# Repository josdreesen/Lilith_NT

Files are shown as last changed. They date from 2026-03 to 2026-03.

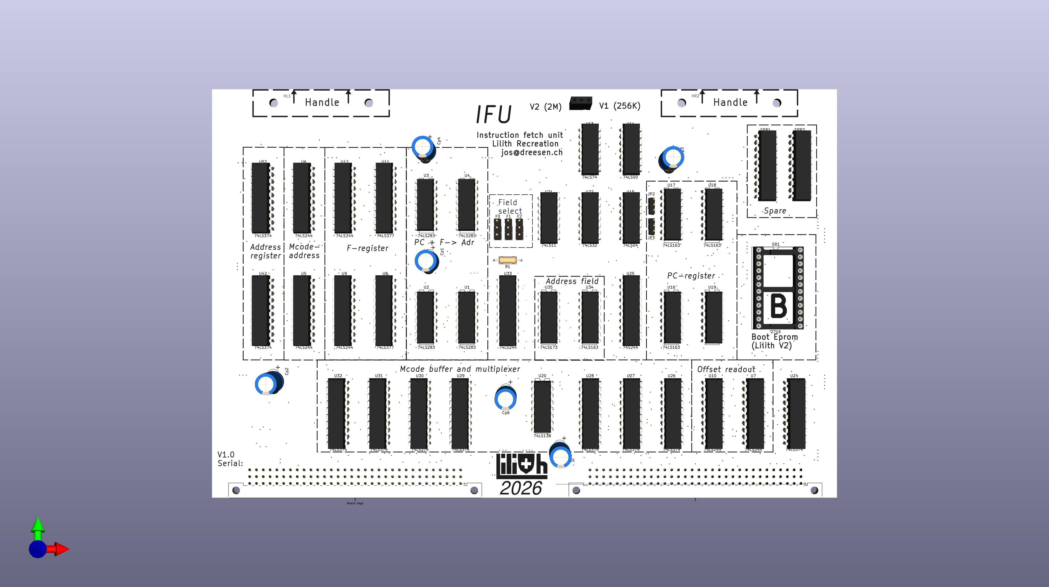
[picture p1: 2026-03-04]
IFU_NT/IFU_NT.jpg

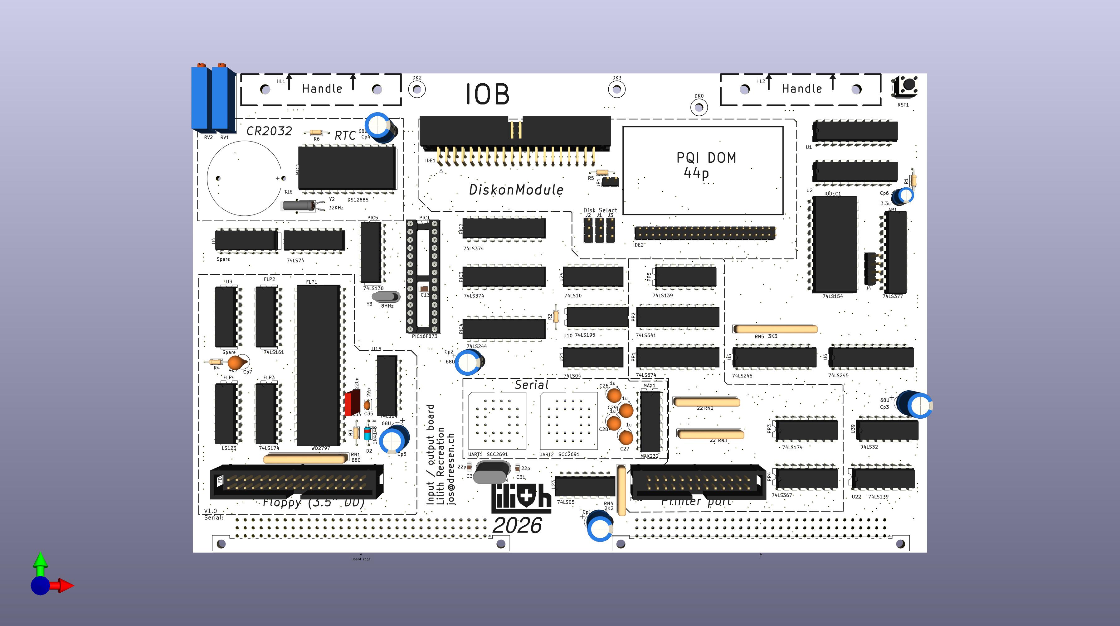
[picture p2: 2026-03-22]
IOB_NT/IOB_NT.jpg

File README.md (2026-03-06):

# Lilith_NT

This database documents my attempt to recreate the 1980's ETH Lilith Modula-2 workstation. Both hardware and software is to be documented here.

The actual CPU will be identical to the original machine, shortcuts will be made to avoid some of the original problems :
- The disk was either a Honeywell-Bull 10Mb cartridge drive, or a 15Mb  MFM drive, controlled by a WD1001.
- NEW -> This is to be replaced by a DOM-disk with ATA interface.
- The original ha 4 PCB's with each 32 4116-type DRAM-chips, for a total of 128K 16bit words.
- NEW -> a single PCB will hold 16 256Kx4 chips, for a total of 1M 16bit words.
  Other characteristics will remain the same ( i.e. write access in 16bit words, read access in either 16bit of 64bit words)
- NEW : DIN41642 connectors will replace the original, hard to find and expensive 1.125" spaced board edge connectors.

Lilith-NT's hardware consists of 8 PCB's, all newly designed in a more compact format (Dual eurocard, 233.4mm x 152mm)

DPU : a MC6802 based debugging aid. This takes over the main busses in the system, allowing direct access to the hardware.
      Original schematic, slightly newer memory chips, new board layout.
      Not needed in normal operation of a Lilith.

ALU : the actual CPU, consisting of 4 AMD2901 bitslices, hardware stack and a 16bit barrel shifter.
      Original schematic with a new board layout.

MCU : microcode unit. Contains the microprogram that controls the bitslices, also has the microcode sequencer and clockgen circuitry.
      Original schematic with a new PCB layout, but now also has the memory address registers, originally in the CDP board.

IFU : instruction fetch unit. Also contains boot eprom. Original schematic with a new board layout.

DRAM: main memory, consisting of 16 4x256K DRAMs. Updated design of the original, using much denser chips. 
      Also contains the Dataregister which was originally in the CDP board.
      
DSP : Display unit / Videocard. Original schematic with a new board layout.      

IOP : IO board : new design, new PCB combining PS2 keyboard & mouse interface. 
      Also contains 2 serial channels, ATA/DOM disk, floppy interface and RTC chip.
      
Mainboard : carrries the above mentioned boards in dedicated slots.
            New design, using DIN-connectors instead of the PCB cardedge connectors to reduce cost and increase reliability.
            Goldplating PCB's is considerable more expensive than just using the DIN connectors.

The subdirectories, one for each pcb,  contain a .zip file with the gerbers, a .pdf with the schematic, a rendering of the PCB
and the Kicad Database itself.

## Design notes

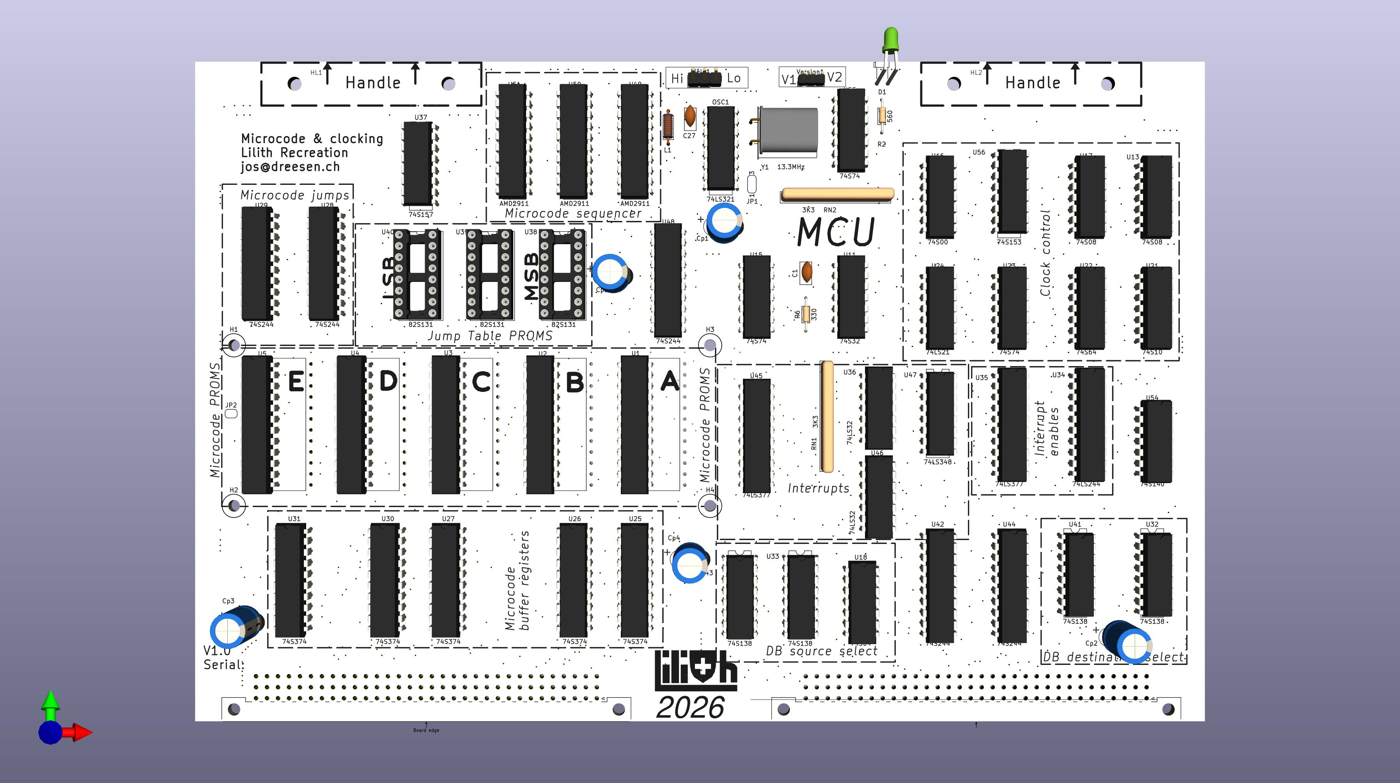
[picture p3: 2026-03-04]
MCU_NT/MCU_NT.jpg

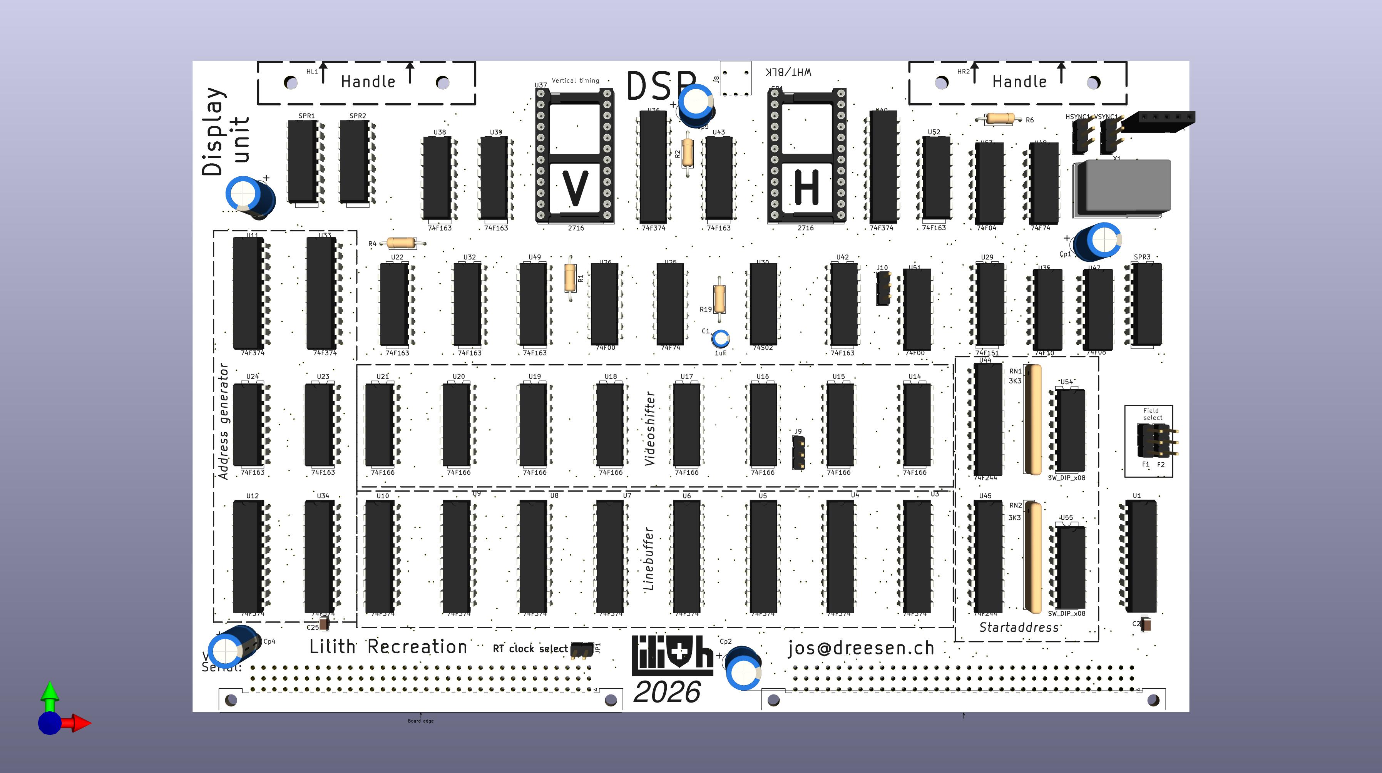
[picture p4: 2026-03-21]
DSP_NT/DSP_NT.jpg

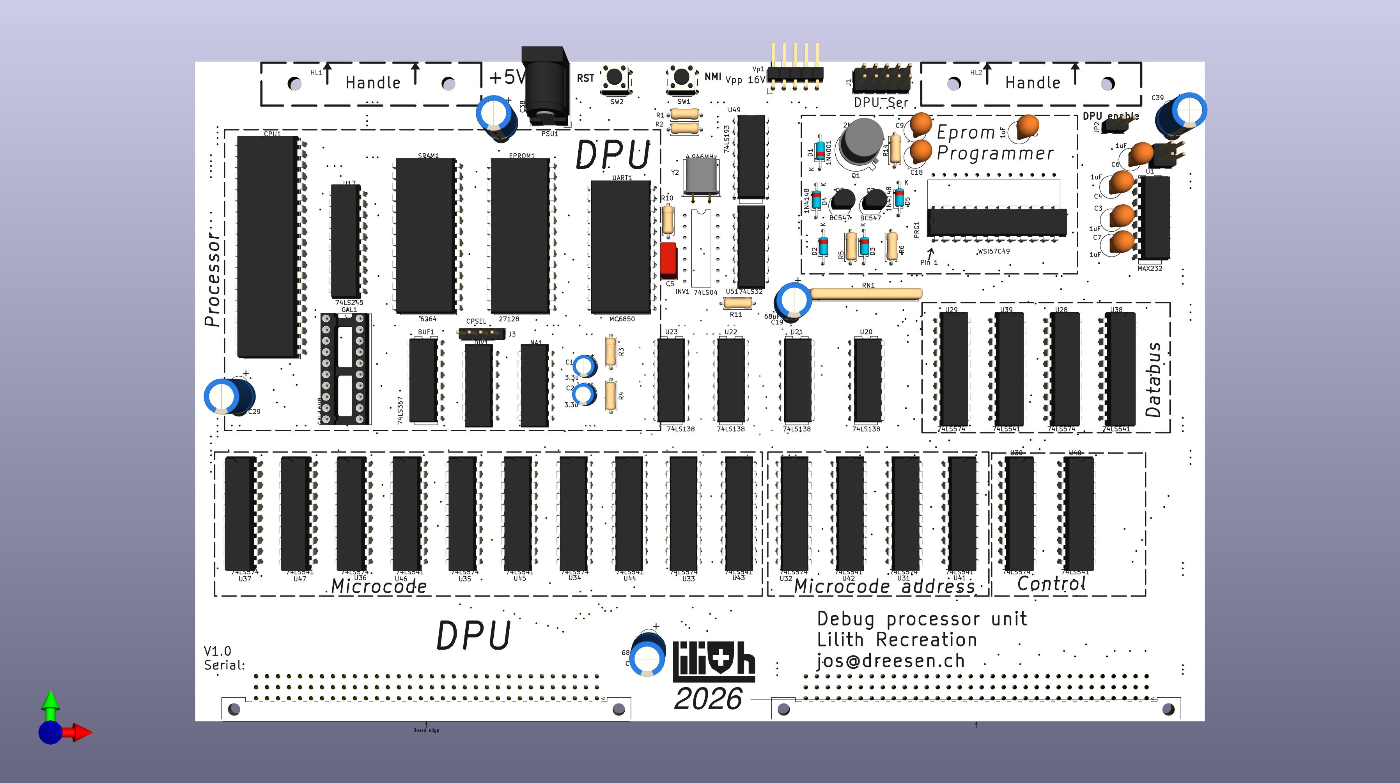
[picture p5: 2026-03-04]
DPU_NT/DPU_NT.jpg

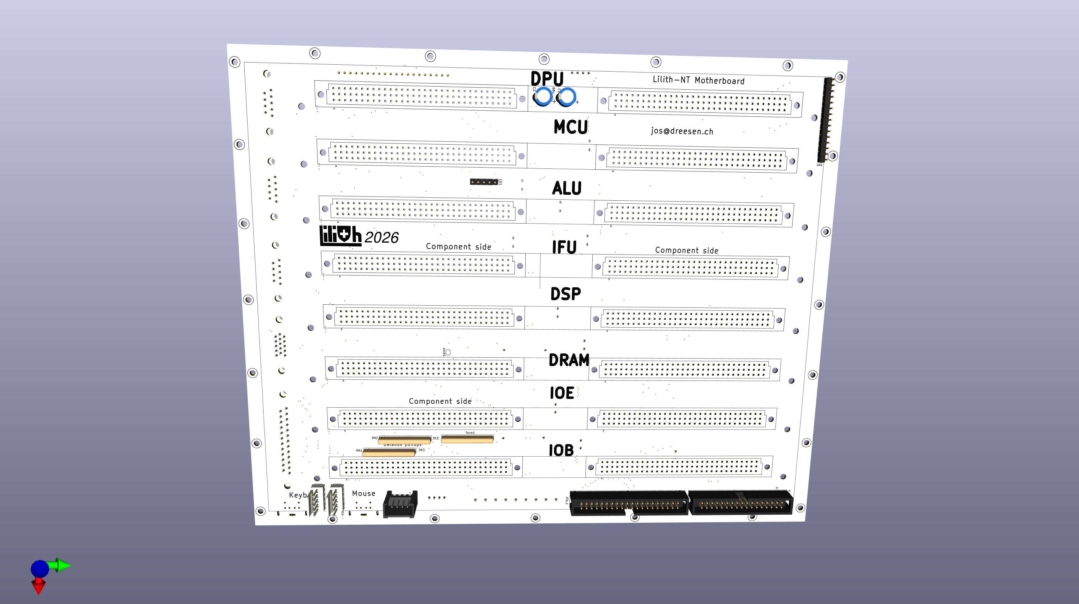
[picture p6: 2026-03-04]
Backplane_NT/Backplane_NT.jpg

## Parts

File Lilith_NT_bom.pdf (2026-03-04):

| Package_ | Number | Pins | Total pins

## Programmed ICs

PIC16F873-XXISP | Package_DIP:DIP-28_W7.62mm_Socket | 1 | 28 | 28 | IOB
Eprom 27128 | Package_DIP:DIP-28_W15.24mm | 1 | 28 | 28 | DPU
Eprom 2716 | Package_DIP:DIP-24_W15.24mm_Socket | 3 | 24 | 72 | DSP | IFU
WSI57C49 | Package_DIP:DIP-24_W15.24mm | 5 | 24 | 120 | MCU
82S131 | Package_DIP:DIP-16_W7.62mm_Socket | 3 | 16 | 48 | MCU
GAL16V8 | Package_DIP:DIP-20_W7.62mm_Socket | 2 | 20 | 40 | DPU | DRAM

## Special ICs

AMD2901 | Package_DIP:DIP-40_W15.24mm | 4 | 40 | 160 | ALU
AMD2911 | Package_DIP:DIP-20_W7.62mm | 3 | 20 | 60 | MCU
DS12885 | Package_DIP:DIP-24_W15.24mm | 1 | 24 | 24 | IOB
WD2797 | Package_DIP:DIP-40_W15.24mm | 1 | 40 | 40 | IOB
SCC2691 | Package_LCC:PLCC-28_THT-Socket | 2 | 28 | 56 | IOB
MAX232 | Package_SO:SO-16_5.3x10.2mm_P1.27mm | 1 | 16 | 16 | IOB
DRAM 256Kx4” | Package_DIP:DIP-20_W7.62mm | 16 | 20 | 320 | DRAM
SRAM 8K 6264 | Package_DIP:DIP-28_W15.24mm | 1 | 28 | 28 | DPU
LM555xN | Package_DIP:DIP-8_W7.62mm | 1 | 8 | 8 | DRAM
MAX232 | Package_DIP:DIP-16_W7.62mm | 1 | 16 | 16 | DPU
MC6802 | Package_DIP:DIP-40_W15.24mm | 1 | 40 | 40 | DPU
MC6850 | Package_DIP:DIP-24_W15.24mm | 1 | 24 | 24 | DPU
SN74S409 | Package_DIP:DIP-48_W15.24mm | 1 | 48 | 48 | DRAM

## TTL ICs

74F00 | Package_DIP:DIP-14_W7.62mm | 2 | 14 | 28 | DSP
74F04 | Package_DIP:DIP-14_W7.62mm | 1 | 14 | 14 | DSP
74F08 | Package_DIP:DIP-14_W7.62mm | 1 | 14 | 14 | DSP
74F10 | Package_DIP:DIP-14_W7.62mm | 1 | 14 | 14 | DSP
74F151 | Package_DIP:DIP-16_W7.62mm | 1 | 16 | 16 | DSP
74F74 | Package_DIP:DIP-14_W7.62mm | 2 | 14 | 28 | DSP
74F163 | Package_DIP:DIP-16_W7.62mm | 10 | 16 | 160 | DSP
74F166 | Package_DIP:DIP-16_W7.62mm | 8 | 16 | 128 | DSP
74F244 | Package_DIP:DIP-20_W7.62mm | 3 | 20 | 60 | DSP
74F374 | Package_DIP:DIP-20_W7.62mm | 14 | 20 | 280 | DSP
74LS00 | Package_DIP:DIP-14_W7.62mm | 1 | 14 | 14 | IFU
74LS04 | Package_DIP:DIP-14_W7.62mm | 5 | 14 | 70 | DPU | DRAM | IFU | IOB
74LS05 | Package_DIP:DIP-14_W7.62mm | 1 | 14 | 14 | IOB
74LS08 | Package_DIP:DIP-14_W7.62mm | 1 | 14 | 14 | IOB
74LS10 | Package_DIP:DIP-14_W7.62mm | 1 | 14 | 14 | IOB
74LS11 | Package_DIP:DIP-14_W7.62mm | 1 | 14 | 14 | IFU
74LS123 | Package_DIP:DIP-16_W7.62mm | 2 | 16 | 32 | DRAM | IOB
74LS125 | Package_DIP:DIP-14_W7.62mm | 1 | 14 | 14 | ALU
74LS132 | Package_DIP:DIP-14_W7.62mm | 1 | 14 | 14
74LS138 | Package_DIP:DIP-16_W7.62mm | 6 | 16 | 96 | DPU | IFU | IOB
74LS139 | Package_DIP:DIP-16_W7.62mm | 3 | 16 | 48 | DRAM | IOB
74LS153 | Package_DIP:DIP-16_W7.62mm | 1 | 16 | 16 | ALU
74LS154 | Package_DIP:DIP-24_W15.24mm | 1 | 24 | 24 | IOB
74LS161 | Package_DIP:DIP-16_W7.62mm | 1 | 16 | 16 | IOB
74LS163 | Package_DIP:DIP-16_W7.62mm | 5 | 16 | 80 | IFU
74LS173 | Package_DIP:DIP-16_W7.62mm | 2 | 16 | 32 | ALU | IFU
74LS174 | Package_DIP:DIP-16_W7.62mm | 2 | 16 | 32 | IOB
74LS191 | Package_DIP:DIP-16_W7.62mm | 1 | 16 | 16 | ALU
74LS193 | Package_DIP:DIP-16_W7.62mm | 1 | 16 | 16 | DPU
74LS195 | Package_DIP:DIP-16_W7.62mm | 1 | 16 | 16 | IOB
74LS21 | Package_DIP:DIP-14_W7.62mm | 1 | 14 | 14 | MCU
74LS244 | Package_DIP:DIP-20_W7.62mm | 10 | 20 | 200 | IFU | MCU | IOB
74LS245 | Package_DIP:DIP-20_W7.62mm | 11 | 20 | 220 | DPU | DRAM | IOB
74ls278 | Package_DIP:DIP-14_W7.62mm | 1 | 14 | 14 | DRAM
74LS283 | Package_DIP:DIP-16_W7.62mm | 5 | 16 | 80 | ALU | IFU
74LS32 | Package_DIP:DIP-14_W7.62mm | 8 | 14 | 112 | DPU | IFU | MCU | IOB
74LS321 | Package_DIP:DIP-16_W7.62mm | 1 | 16 | 16 | MCU
74LS348 | Package_DIP:DIP-16_W7.62mm | 1 | 16 | 16 | MCU
74LS367 | Package_DIP:DIP-16_W7.62mm | 2 | 16 | 32 | DPU | IOB
74LS374 | Package_DIP:DIP-20_W7.62mm | 13 | 20 | 260 | IFU | IOB
74LS377 | Package_DIP:DIP-20_W7.62mm | 5 | 20 | 100 | IFU | MCU | IOB
74LS541 | Package_DIP:DIP-20_W7.62mm | 18 | 20 | 360 | DPU | DRAM
74LS574 | Package_DIP:DIP-20_W7.62mm | 14 | 20 | 280 | DPU | DRAM
74LS74 | Package_DIP:DIP-14_W7.62mm | 5 | 14 | 70 | DPU | DRAM | IFU | IOB
74LS86 | Package_DIP:DIP-14_W7.62mm | 1 | 14 | 14 | ALU
74S00 | Package_DIP:DIP-14_W7.62mm | 1 | 14 | 14 | ALU
74S00 | Package_DIP:DIP-14_W7.62mm | 2 | 14 | 28 | DRAM | MCU
74S02 | Package_DIP:DIP-14_W7.62mm | 2 | 14 | 28 | ALU | DSP
74S04 | Package_DIP:DIP-14_W7.62mm | 2 | 14 | 28 | ALU | MCU
74S08 | Package_DIP:DIP-14_W7.62mm | 2 | 14 | 28 | MCU
74S10 | Package_DIP:DIP-14_W7.62mm | 1 | 14 | 14 | MCU
74S138 | Package_DIP:DIP-16_W7.62mm | 4 | 16 | 64 | MCU
74S140 | Package_DIP:DIP-14_W7.62mm | 1 | 14 | 14 | MCU
74S153 | Package_DIP:DIP-16_W7.62mm | 1 | 16 | 16 | MCU
74S157 | Package_DIP:DIP-16_W7.62mm | 2 | 16 | 32 | ALU | MCU
74S174 | Package_DIP:DIP-16_W7.62mm | 1 | 16 | 16 | ALU
74S182 | Package_DIP:DIP-16_W7.62mm | 1 | 16 | 16 | ALU
74s189 | Package_DIP:DIP-16_W7.62mm | 4 | 16 | 64 | ALU
74S240 | Package_DIP:DIP-20_W7.62mm | 2 | 20 | 40 | ALU
74S244 | Package_DIP:DIP-20_W7.62mm | 9 | 20 | 180 | ALU | IFU | MCU
74S32 | Package_DIP:DIP-14_W7.62mm | 13 | 14 | 182 | ALU | DRAM | MCU
74S350 | Package_DIP:DIP-16_W7.62mm | 8 | 16 | 128 | ALU
74S374 | Package_DIP:DIP-20_W7.62mm | 5 | 20 | 100 | MCU
74S64 | Package_DIP:DIP-14_W7.62mm | 3 | 14 | 42 | ALU | MCU
74S74 | Package_DIP:DIP-14_W7.62mm | 3 | 14 | 42 | MCU | IOB
| Number of IC’s | 293
| Number of IC solder joints | 5374
Resistors | | | 2
| 100 Resistor_SMD:R_0805_2012Metric_Pad1.20x1.40m | 20 | 2 | 40 | DRAM
| 0 Resistor_SMD:R_0805_2012Metric_Pad1.20x1.40m | 9 | 2 | 18 | DRAM
3K3 | Resistor_THT:R_Array_SIP10,Resistor_THT:R_Ax | 5 | 10 | 50 | DRAM
3K3 | Resistor_THT:R_Array_SIP10 | 1 | 10 | 10 | DPU
3K3 | Resistor_THT:R_Array_SIP10 | 2 | 10 | 20 | DSP
3K3 | Resistor_THT:R_Array_SIP10 | 2 | 10 | 20 | MCU
| 560 Resistor_THT:R_Axial_DIN0204_L3.6mm_D1.6mm_P | 4 | 2 | 8 | ALU
| 560 Resistor_THT:R_Axial_DIN0204_L3.6mm_D1.6mm_P | 1 | 2 | 2 | MCU
| 330 Resistor_THT:R_Axial_DIN0204_L3.6mm_D1.6mm_P | 1 | 2 | 2 | MCU
| 560 Resistor_THT:R_Axial_DIN0207_L6.3mm_D2.5mm_P | 4 | 2 | 8 | DSP
10k | Resistor_THT:R_Axial_DIN0207_L6.3mm_D2.5mm_P | 1 | 2 | 2 | DSP
| 560 Resistor_THT:R_Axial_DIN0207_L6.3mm_D2.5mm_P | 1 | 2 | 2 | IFU
10K | Resistor_THT:R_Axial_DIN0207_L6.3mm_D2.5mm_P | 3 | 2 | 6 | DPU
1K | Resistor_THT:R_Axial_DIN0207_L6.3mm_D2.5mm_P | 6 | 2 | 12 | DPU
2K2 | Resistor_THT:R_Axial_DIN0207_L6.3mm_D2.5mm_P | 3 | 2 | 6 | DRAM
4K7 | Resistor_THT:R_Axial_DIN0207_L6.3mm_D2.5mm_P | 1 | 2 | 2 | DRAM
| 680 Resistor_THT:R_Array_SIP10 | 1 | 10 | 10 | IOB
| 220 Resistor_THT:R_Array_SIP10 | 1 | 10 | 10 | IOB
3K3 | Resistor_THT:R_Array_SIP10 | 1 | 10 | 10 | IOB
3K3 | Resistor_THT:R_Array_SIP10 | 2 | 10 | 20 | MoBo
R_Network_Dividers_x08_SResistor_THT:R_Array_SIP10 | 1 | 10 | 10 | MoBo
| 22 Resistor_THT:R_Array_SIP8 | 2 | 8 | 16 | IOB
10K | Resistor_THT:R_Axial_DIN0204_L3.6mm_D1.6mm_P | 1 | 2 | 2 | IOB
2K2 | Resistor_THT:R_Axial_DIN0204_L3.6mm_D1.6mm_P | 2 | 2 | 4 | IOB
1K | Resistor_THT:R_Axial_DIN0204_L3.6mm_D1.6mm_P | 1 | 2 | 2 | IOB
75K | Resistor_THT:R_Axial_DIN0204_L3.6mm_D1.6mm_P | 1 | 2 | 2 | IOB

## Connectors

PCB interconnect | DIN41642-96pin-male-90degrees | 16 | 96 | 1536 | ALU | DPU | DRAM | DSP | IFU | MCU | IOB
PCB interconnect | DIN41642-96pin-female | 16 | 96 | 1536 | ALU | MoBo
DE15_Socket_HighDensity_Connector_Dsub:DSUB-15-HD_Socket_Vertical_P2 | 1 | 15 | 15 | MoBo
Conn_02x13_Top_Bottom Connector_Dsub:DSUB-25_Socket_Vertical_P2.77x | 1 | 25 | 25 | MoBo
DE9_Pins_MountingHoles Connector_Dsub:DSUB-9_Pins_Vertical_P2.77x2.8 | 3 | 9 | 27 | MoBo
Conn_02x13_Top_Bottom Connector_IDC:IDC-Header_2x13_P2.54mm_Vertica | 1 | 26 | 26 | IOB
Conn_02x17_Odd_Even | Connector_IDC:IDC-Header_2x17_P2.54mm_Vertica | 1 | 34 | 34 | IOB
Conn_02x17_Odd_Even | Connector_IDC:IDC-Header_2x17_P2.54mm_Vertica | 1 | 34 | 34 | MoBo
Conn_02x20_Odd_Even | Connector_IDC:IDC-Header_2x20_P2.54mm_Horizon | 1 | 40 | 40 | IOB
Conn_02x20_Odd_Even | Connector_IDC:IDC-Header_2x20_P2.54mm_Vertica | 1 | 20 | 20 | MoBo
Conn_01x05_Pin | Connector_Molex:Molex_KK-254_AE-6410-05A_1x0 | 2 | 5 | 10 | MoBo
Conn_01x09_Socket | Connector_Phoenix_MC_HighVoltage:PhoenixConta | 1 | 9 | 9 | MoBo
Conn_02x22_Odd_Even | Connector_PinHeader_2.00mm:PinHeader_2x22_P2 | 2 | 44 | 88 | IOB
Conn_01x01_Pin | Connector_PinHeader_2.54mm:PinHeader_1x01_P2 | 1 | 1 | 1 | MoBo
Conn_01x04_Pin | Connector_PinHeader_2.54mm:PinHeader_1x04_P2 | 4 | 4 | 16 | IOB
Conn_01x04_Pin | Connector_Stocko:Stocko_MKS_1654-6-0-404_1x4_ | 3 | 4 | 12 | MoBo
Mini-DIN-7 | Mini-DIN PS2 | 2 | 9 | 18 | MoBo

## Capacitors

22p | Capacitor_SMD:C_0805_2012Metric | 2 | 2 | 4 | IOB
22p | Capacitor_SMD:C_0805_2012Metric_Pad1.18x1.45 | 2 | 2 | 4 | IOB
100n | Capacitor_SMD:C_1206_3216Metric_Pad1.33x1.80 | 25 | 2 | 50 | IOB
22p | Capacitor_THT:C_Disc_D3.0mm_W2.0mm_P2.50m | 1 | 2 | 2 | IOB
220n | Capacitor_THT:C_Rect_L7.0mm_W2.5mm_P5.00m | 1 | 2 | 2 | IOB
1u | Capacitor_THT:CP_Radial_Tantal_D4.5mm_P2.50 | 4 | 2 | 8 | IOB
4u7 | Capacitor_THT:CP_Radial_Tantal_D4.5mm_P2.50 | 1 | 2 | 2 | IOB
470n | Capacitor_SMD:C_0805_2012Metric_Pad1.18x1.45 | 75 | 2 | 150 | DRAM | DPU
100n | Capacitor_SMD:C_1206_3216Metric_Pad1.33x1. | 160 | 2 | 320 | DRAM | ALU
68uF | Capacitor_Tantalum_SMD:CP_EIA-7343-20_Kemet-V | 8 | 2 | 16 | DRAM
68uF | Elco 5mm pitch | 40 | 2 | 80 | ALU | DPU
220p | Capacitor_THT:C_Disc_D5.0mm_W2.5mm_P2.50m | 1 | 2 | 2 | MCU | | DSP | IFU | MCU
10p | Capacitor_THT:C_Disc_D5.0mm_W2.5mm_P2.50m | 1 | 2 | 2 | MCU
1n | Capacitor_THT:C_Rect_L7.2mm_W3.5mm_P5.00 | 4 | 2 | 8 | DRAM | | DSP | IFU | IOB
1uF | Capacitor_THT:CP_Radial_D4.0mm_P2.00mm | 1 | 2 | 2 | DSP
3.3u | Capacitor_THT:CP_Radial_D5.0mm_P2.50mm | 2 | 2 | 4 | DPU
1uF | Capacitor_THT:CP_Radial_Tantal_D5.0mm_P2.50 | 7 | 2 | 14 | DPU

## Chrystals

CXO_DIP8 28 MHz | Oscillator:Oscillator_DIP-8 | 1 | 4 | 4 | DSP
13.3MHz | Crystal:Crystal_HC18-U_Horizontal | 1 | 2 | 2 | MCU
4.946MHz | Crystal:Crystal_HC52-8mm_Horizontal | 1 | 2 | 2 | DPU
32KHz | Crystal:Crystal_AT310_D3.0mm_L10.0mm_Horizonta | 1 | 4 | 4 | IOB | 32KHz
3.684MHz | Crystal:Crystal_HC49-U_Vertical | 1 | 2 | 2 | IOB | 3.684MHz
8MHz | Crystal:Crystal_HC52-6mm_Vertical | 1 | 2 | 2 | IOB | 8MHz
| Total number of solder points | | | 9801

## Rest

10uH | Inductor_THT:L_Axial_L5.3mm_D2.2mm_P7.62mm_H | 1 | | | MCU
CR2032 | Battery:BatteryHolder_MYOUNG_BS-07-A1BJ001_ | 1 | | | IOB
SW_DIP_x08 | Package_DIP:DIP-16_W7.62mm | 2 | 16 | | DSP
RSTNMI | Button_Switch_THT:SW_PUSH_6mm | Button_Switch_THT:SW_PUSH_6mm 1 | | | DPU
Barrel_Jack_Switch | Connector_BarrelJack:BarrelJack_GCT_DCJ200-10- | 1 | | | DPU
Boot | LED_THT:LED_D3.0mm_Horizontal_O3.81mm_Z10 | 2 | | | MCU | DRAM
10uH | Inductor_THT:L_Axial_L5.3mm_D2.2mm_P7.62mm_H | 1 | | | MCU
50K | Potentiometer_THT:Potentiometer_Bourns_3006P_Ho | 1 | | | IOB
10K | Potentiometer_THT:Potentiometer_Bourns_3006P_Ho | 1 | | | IOB

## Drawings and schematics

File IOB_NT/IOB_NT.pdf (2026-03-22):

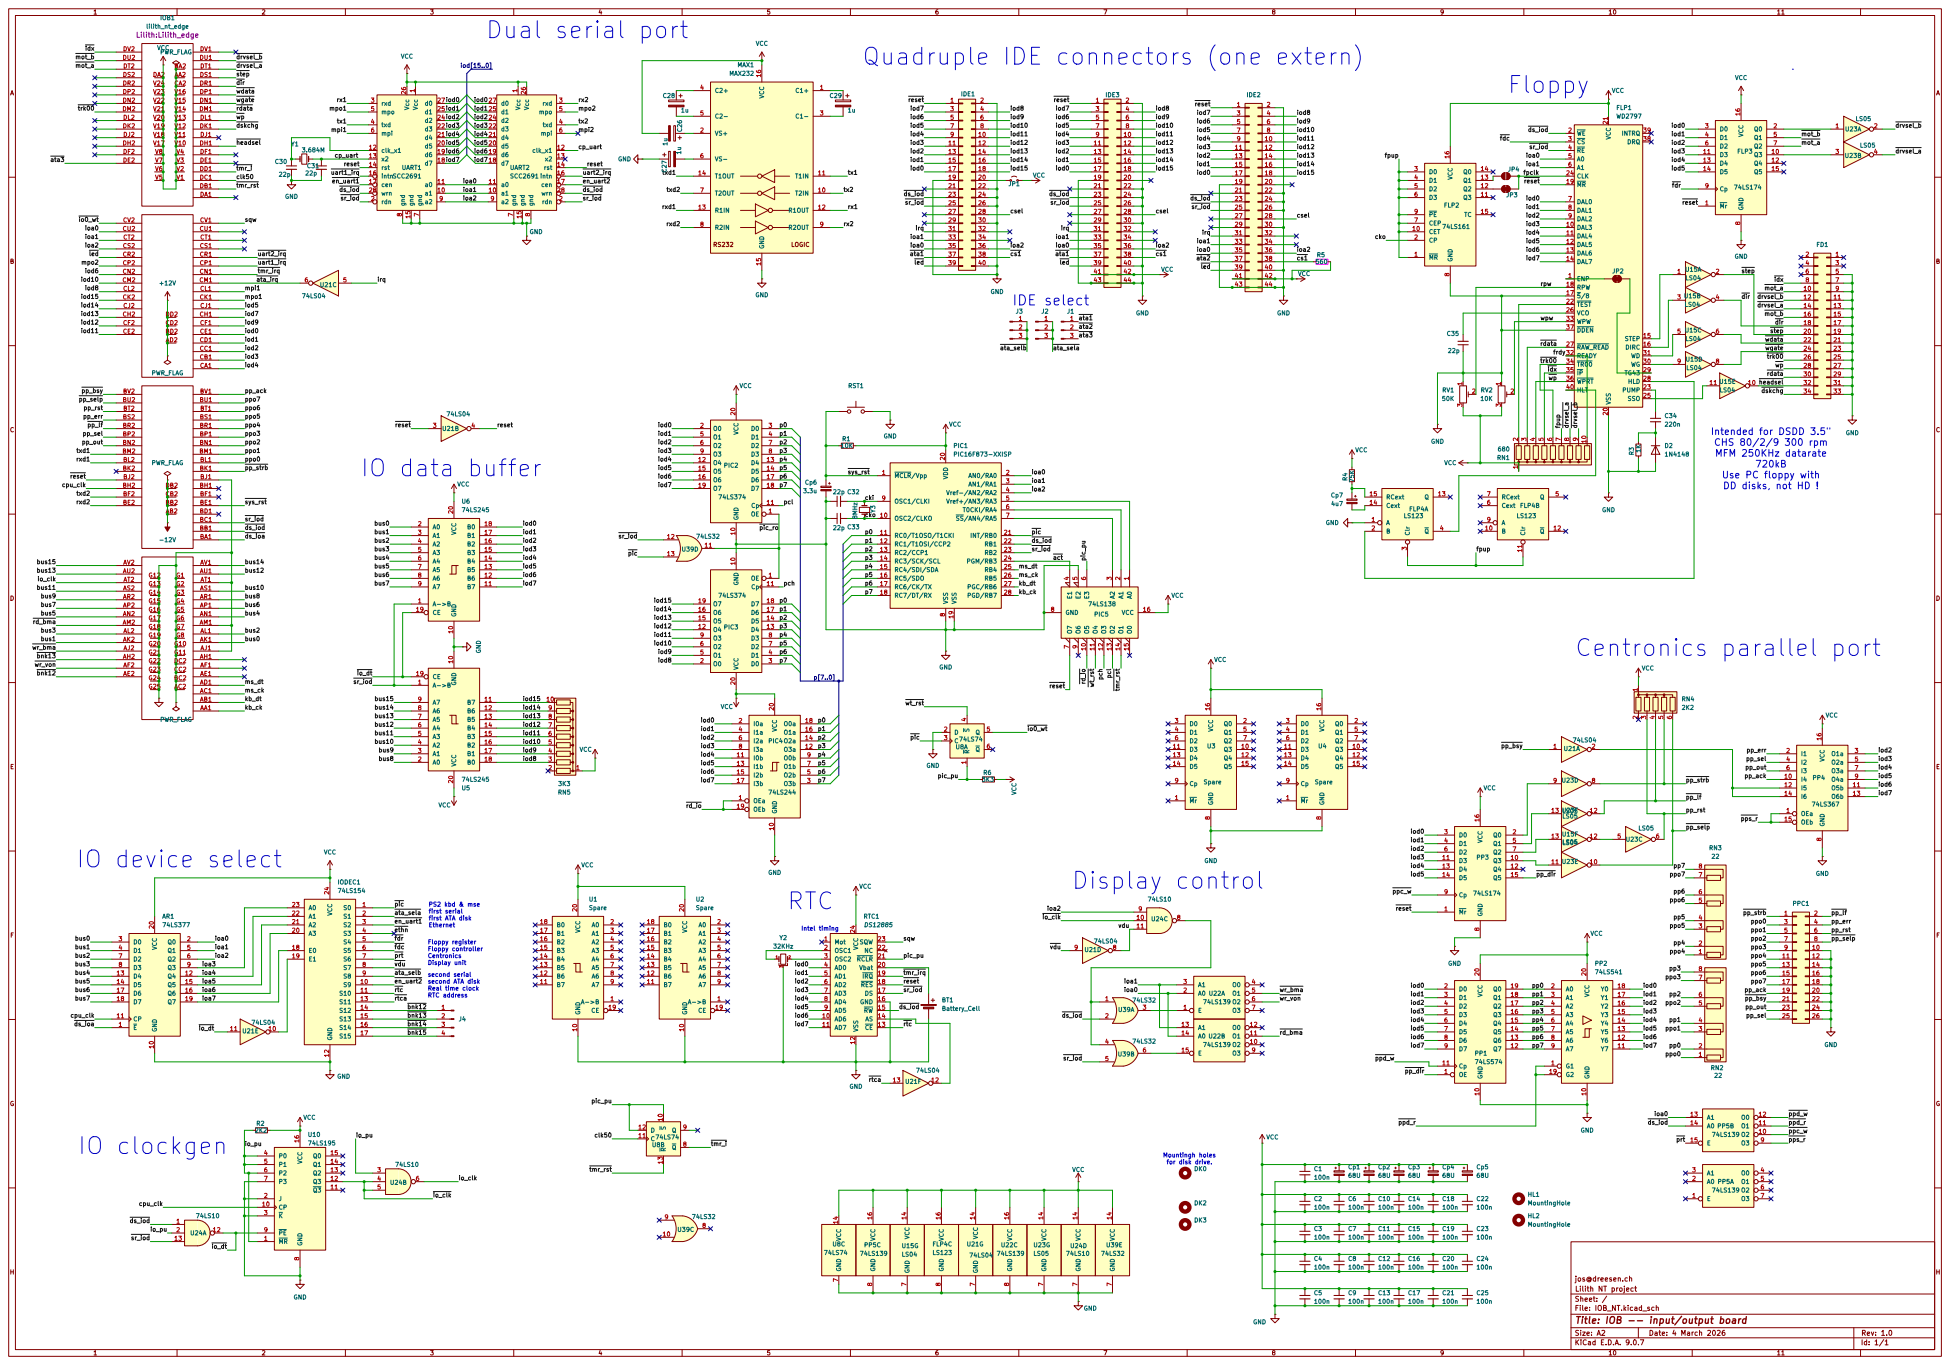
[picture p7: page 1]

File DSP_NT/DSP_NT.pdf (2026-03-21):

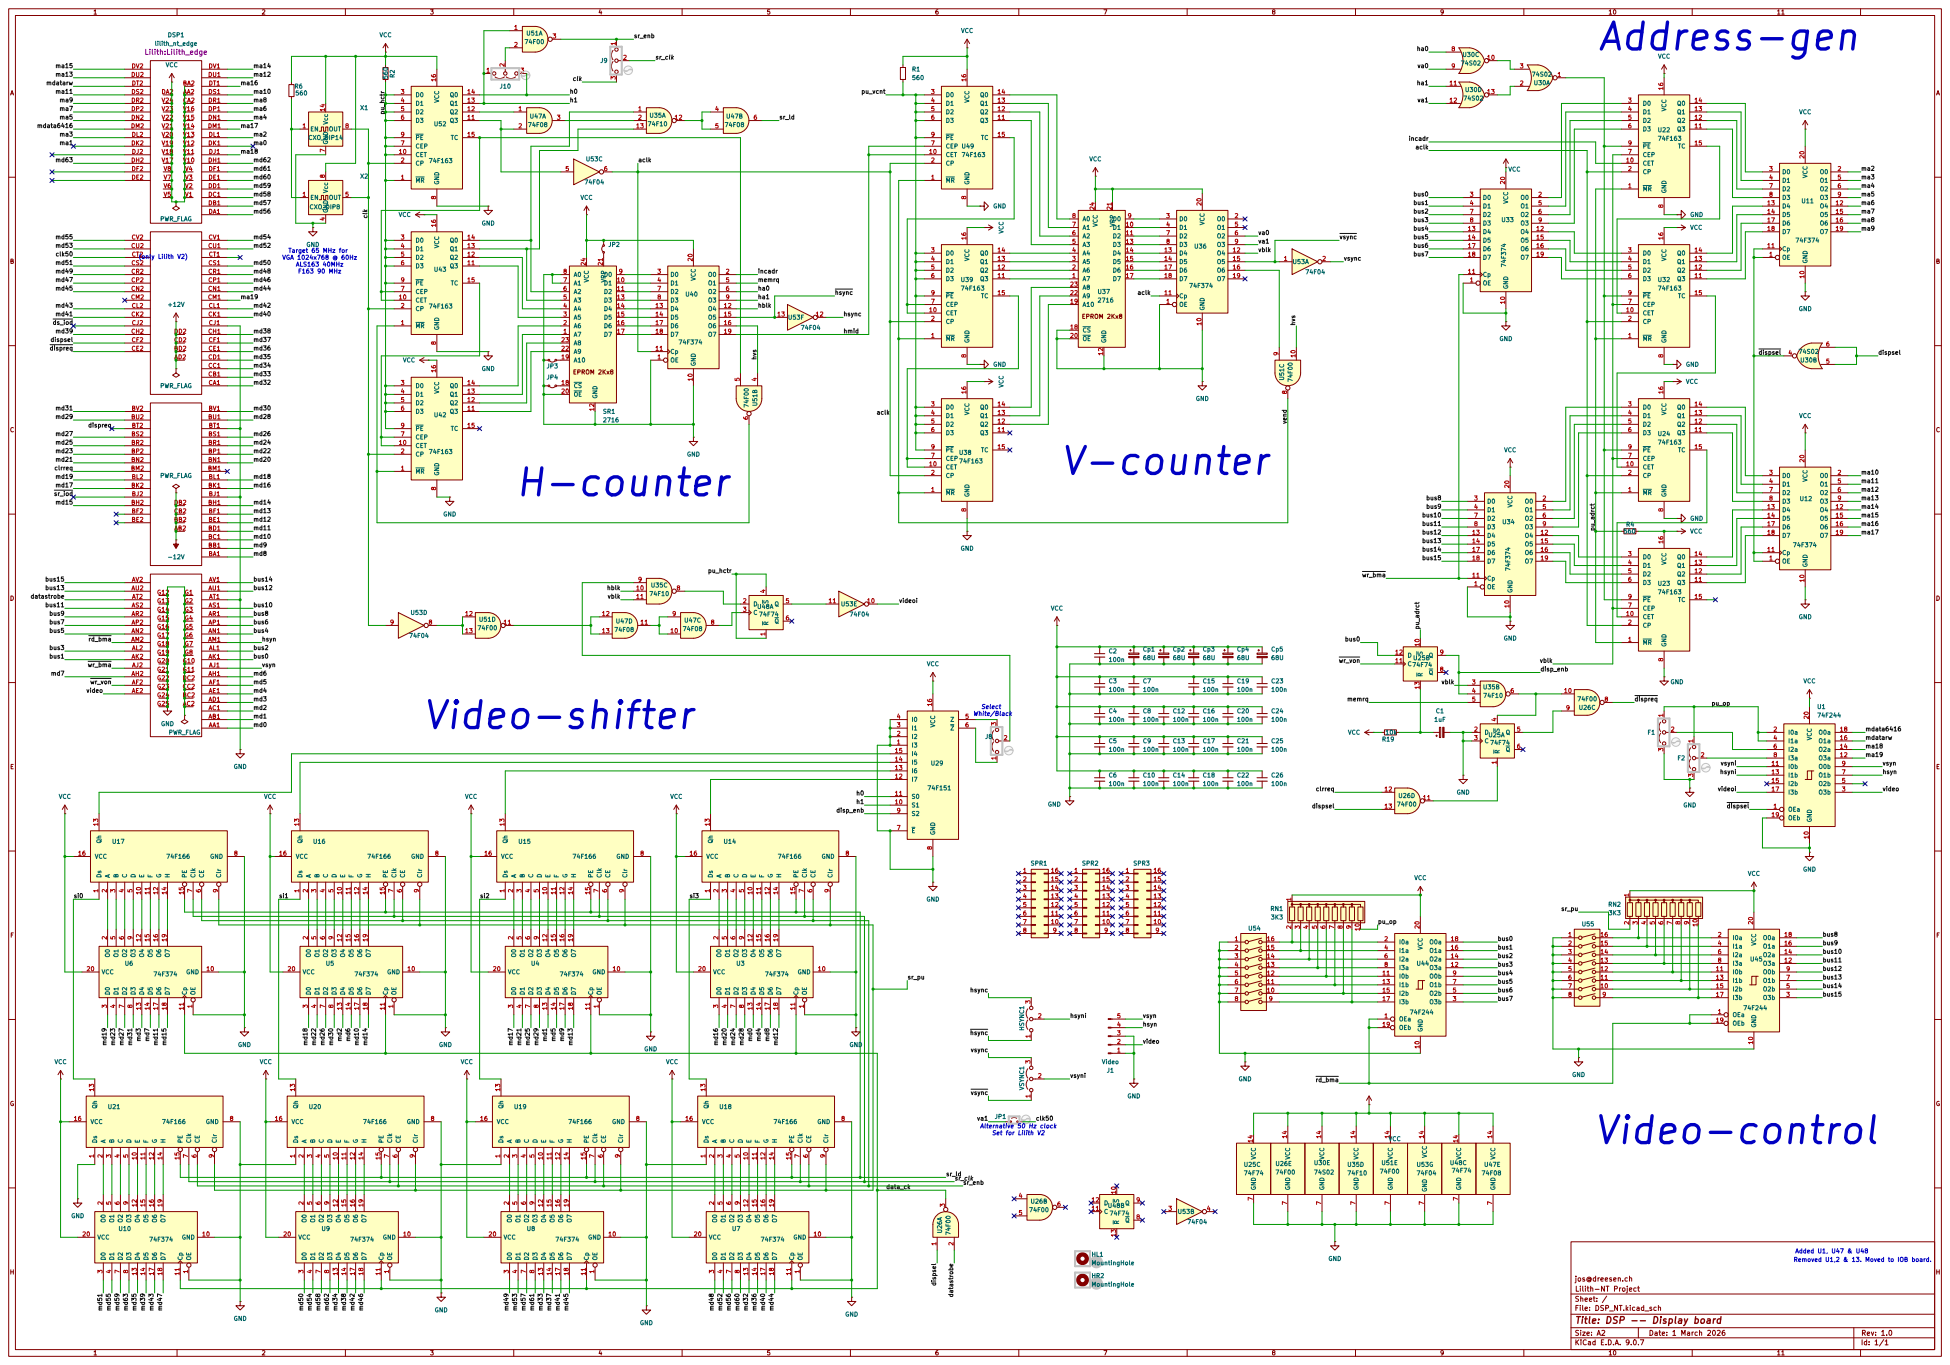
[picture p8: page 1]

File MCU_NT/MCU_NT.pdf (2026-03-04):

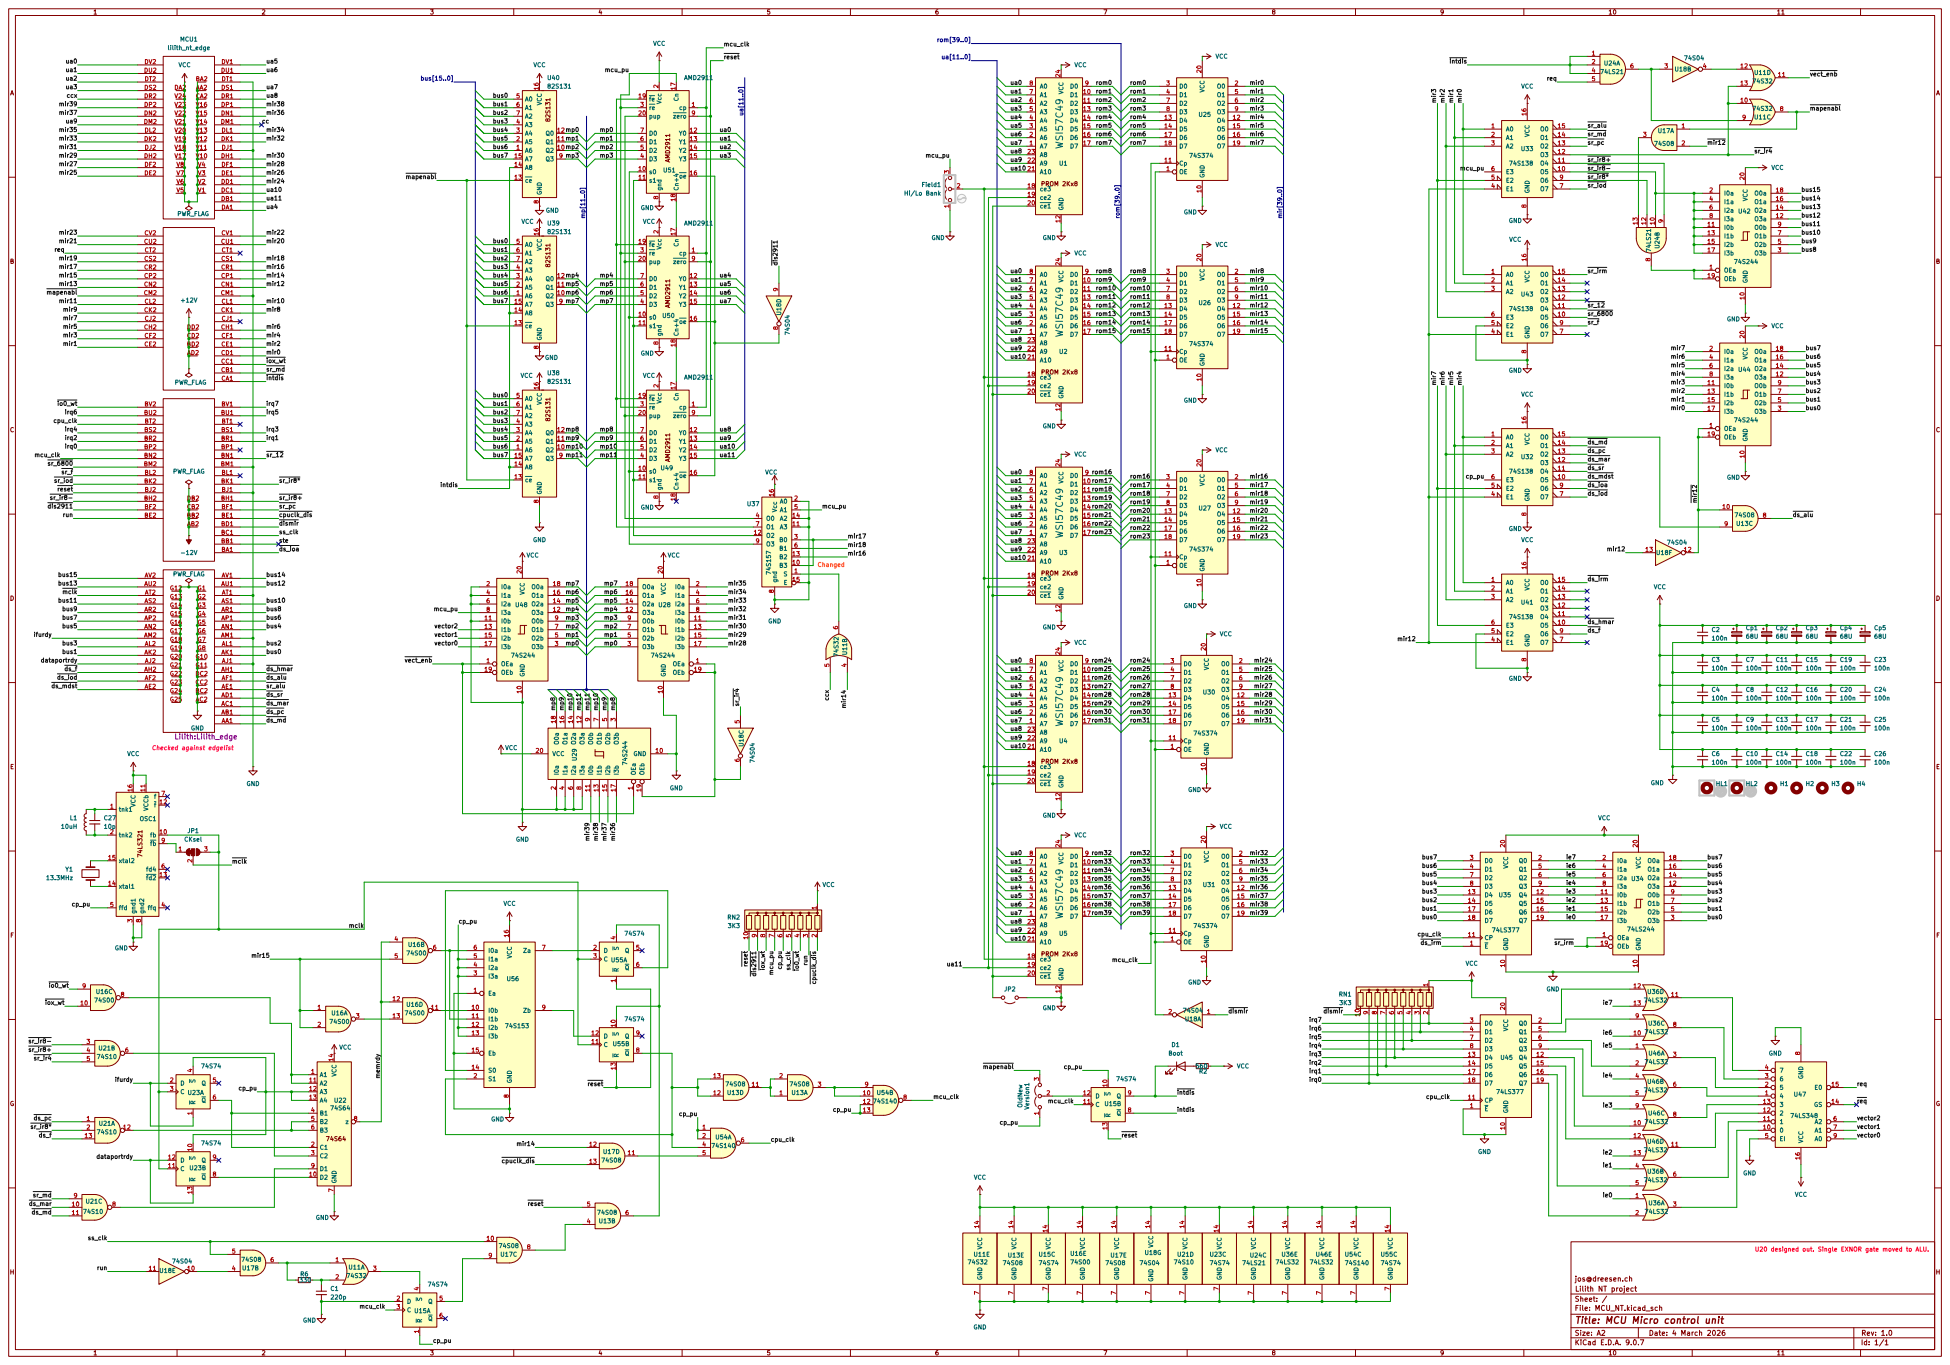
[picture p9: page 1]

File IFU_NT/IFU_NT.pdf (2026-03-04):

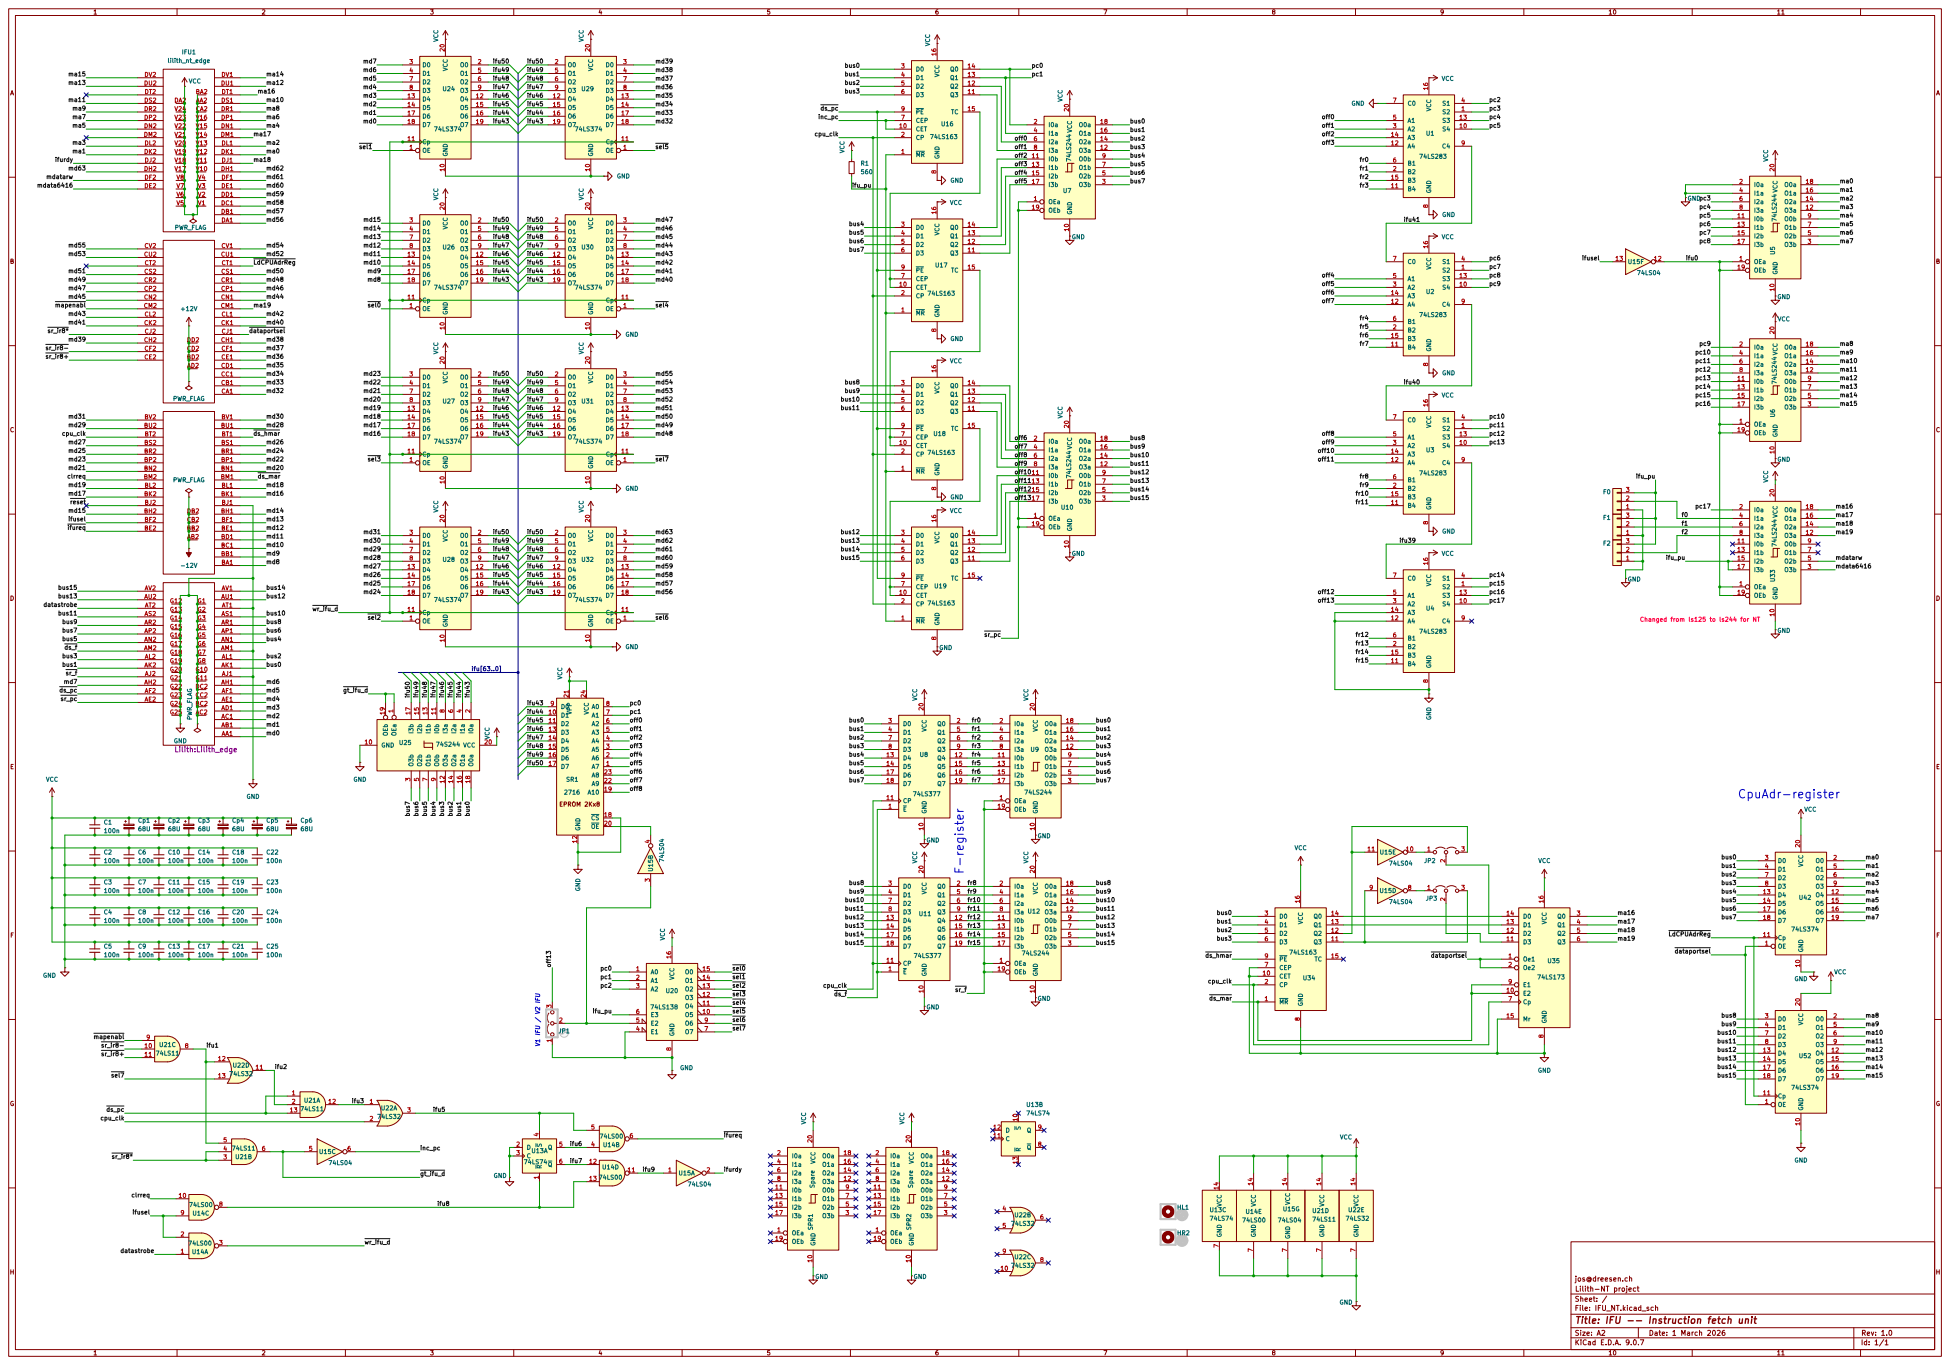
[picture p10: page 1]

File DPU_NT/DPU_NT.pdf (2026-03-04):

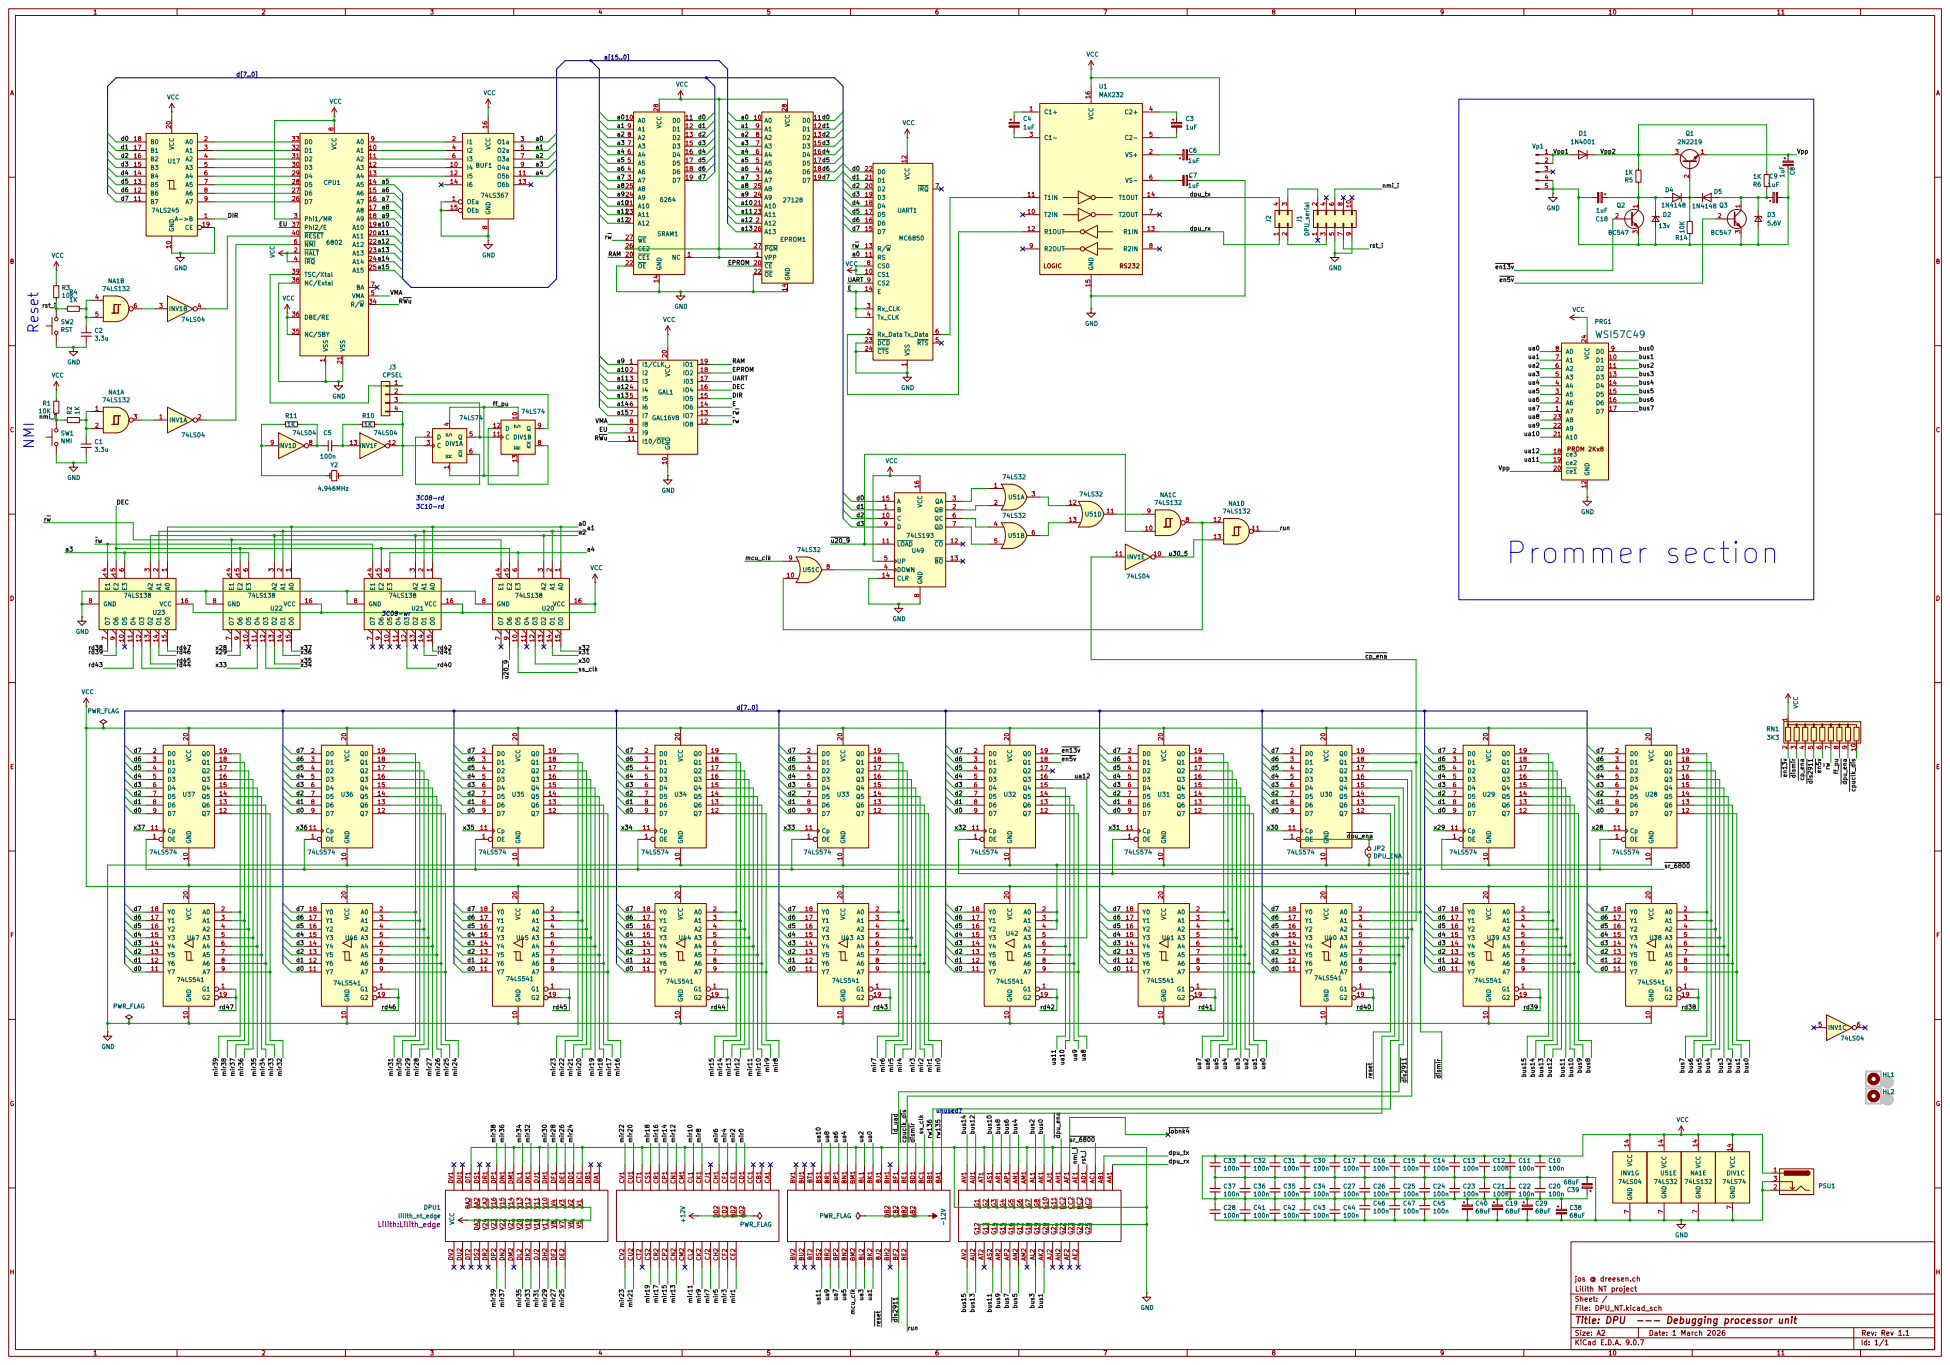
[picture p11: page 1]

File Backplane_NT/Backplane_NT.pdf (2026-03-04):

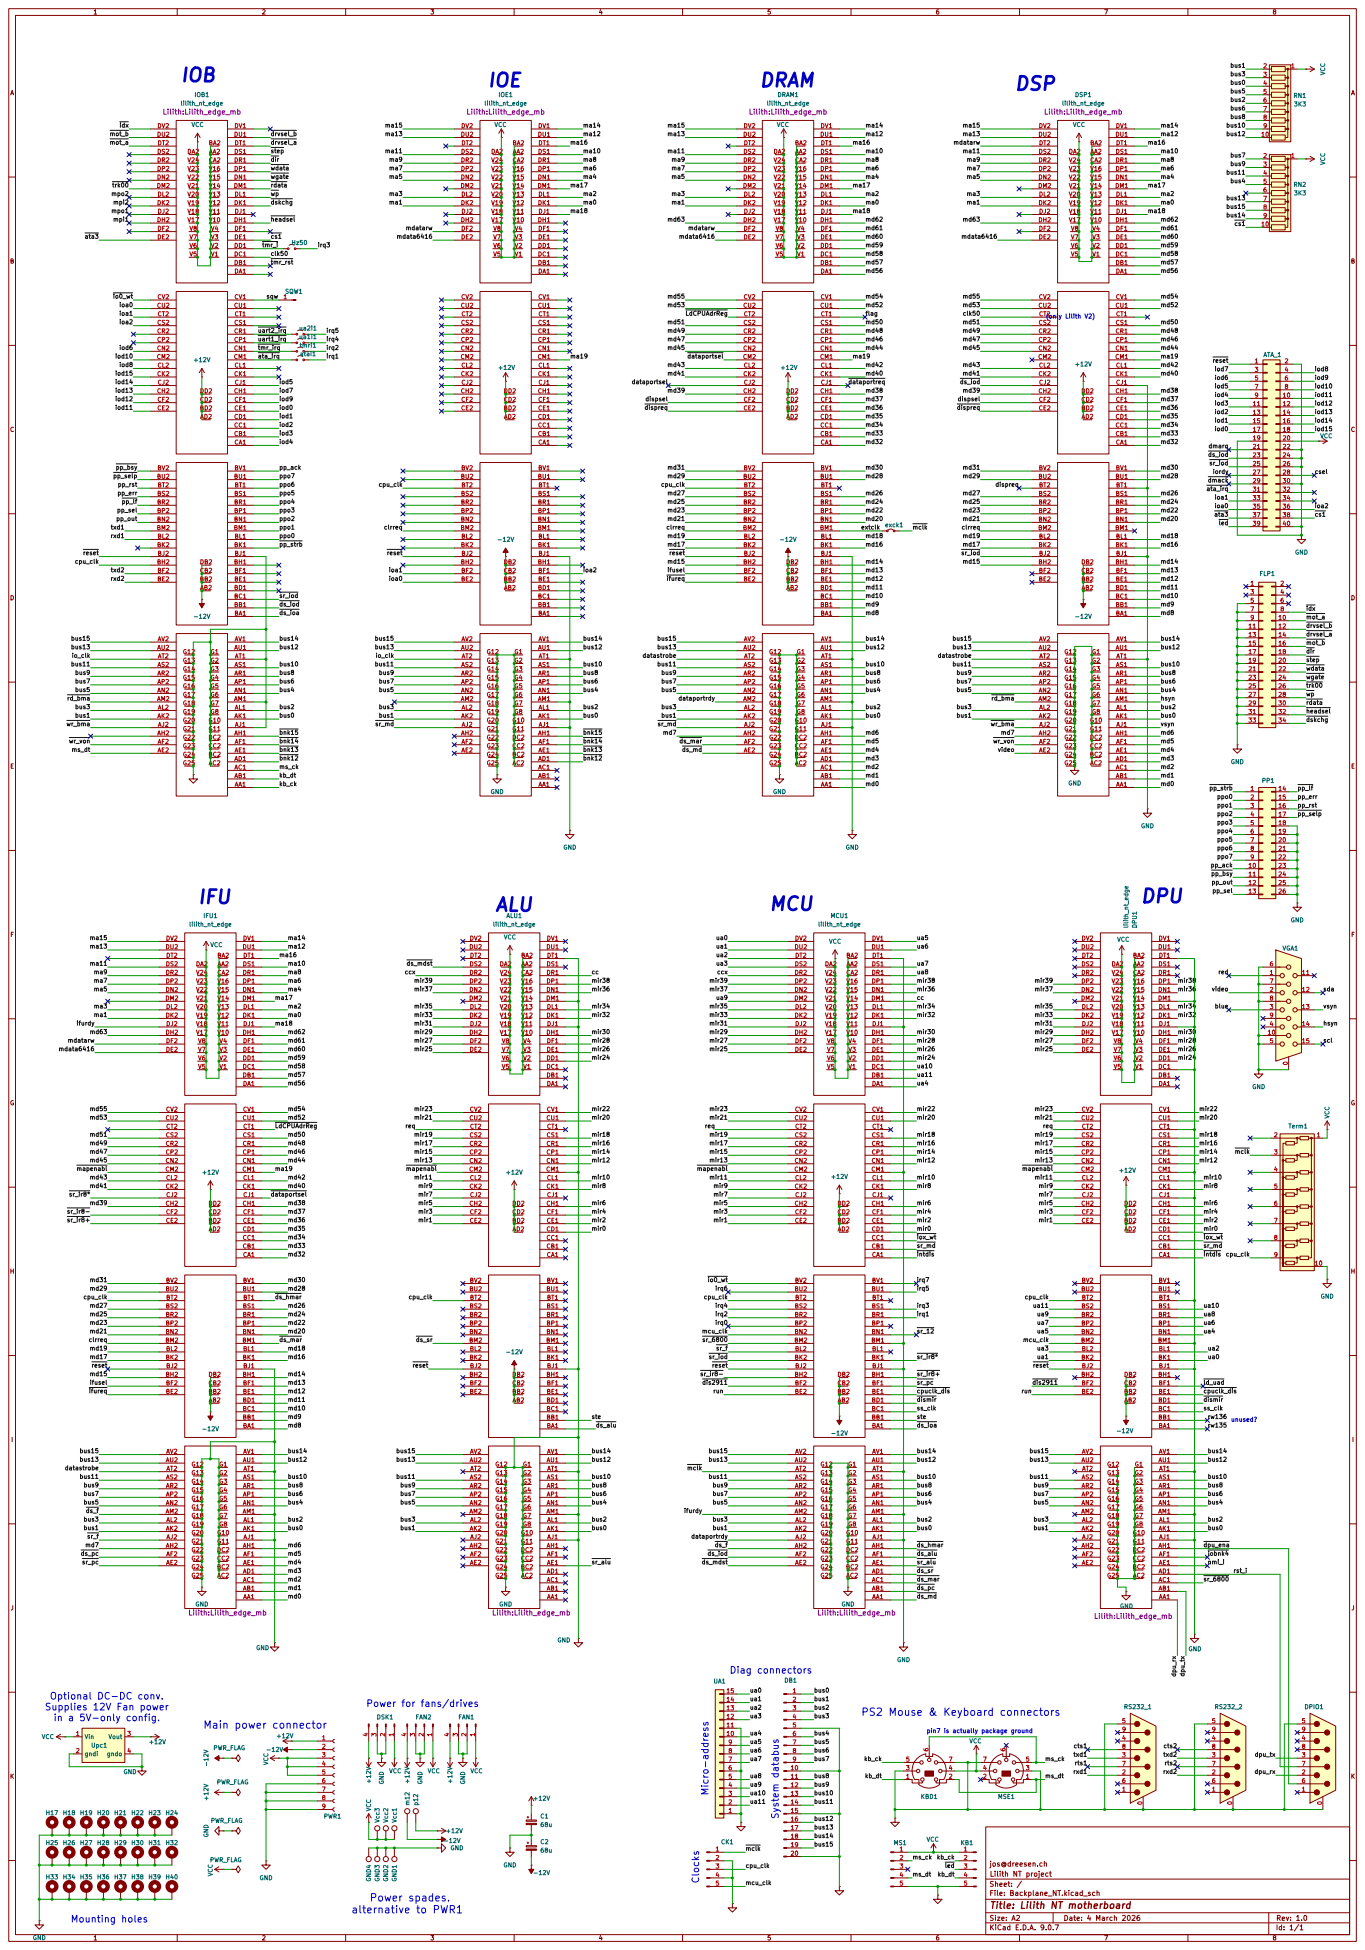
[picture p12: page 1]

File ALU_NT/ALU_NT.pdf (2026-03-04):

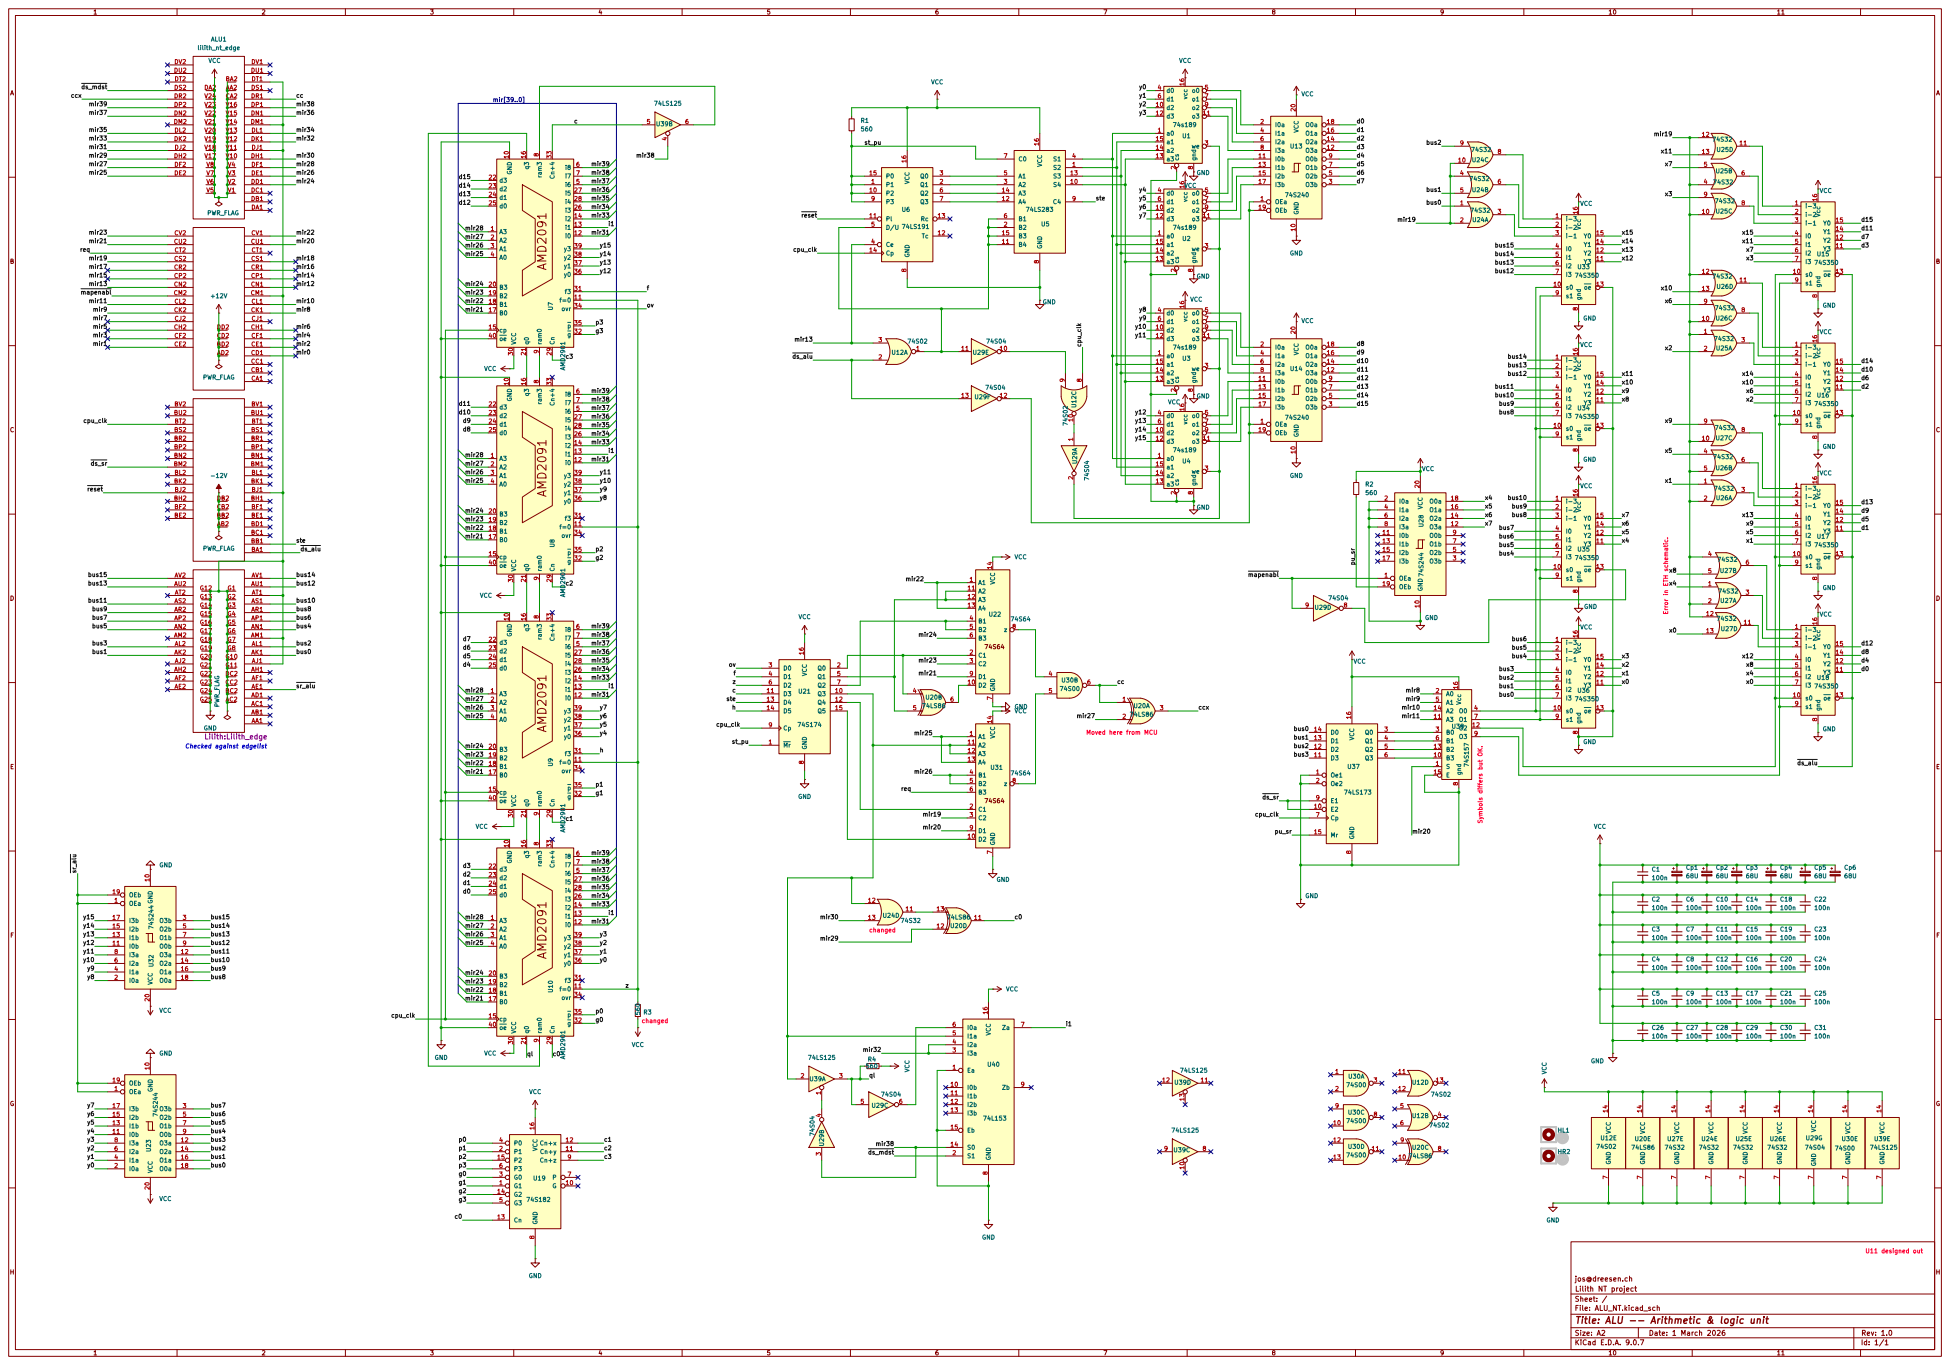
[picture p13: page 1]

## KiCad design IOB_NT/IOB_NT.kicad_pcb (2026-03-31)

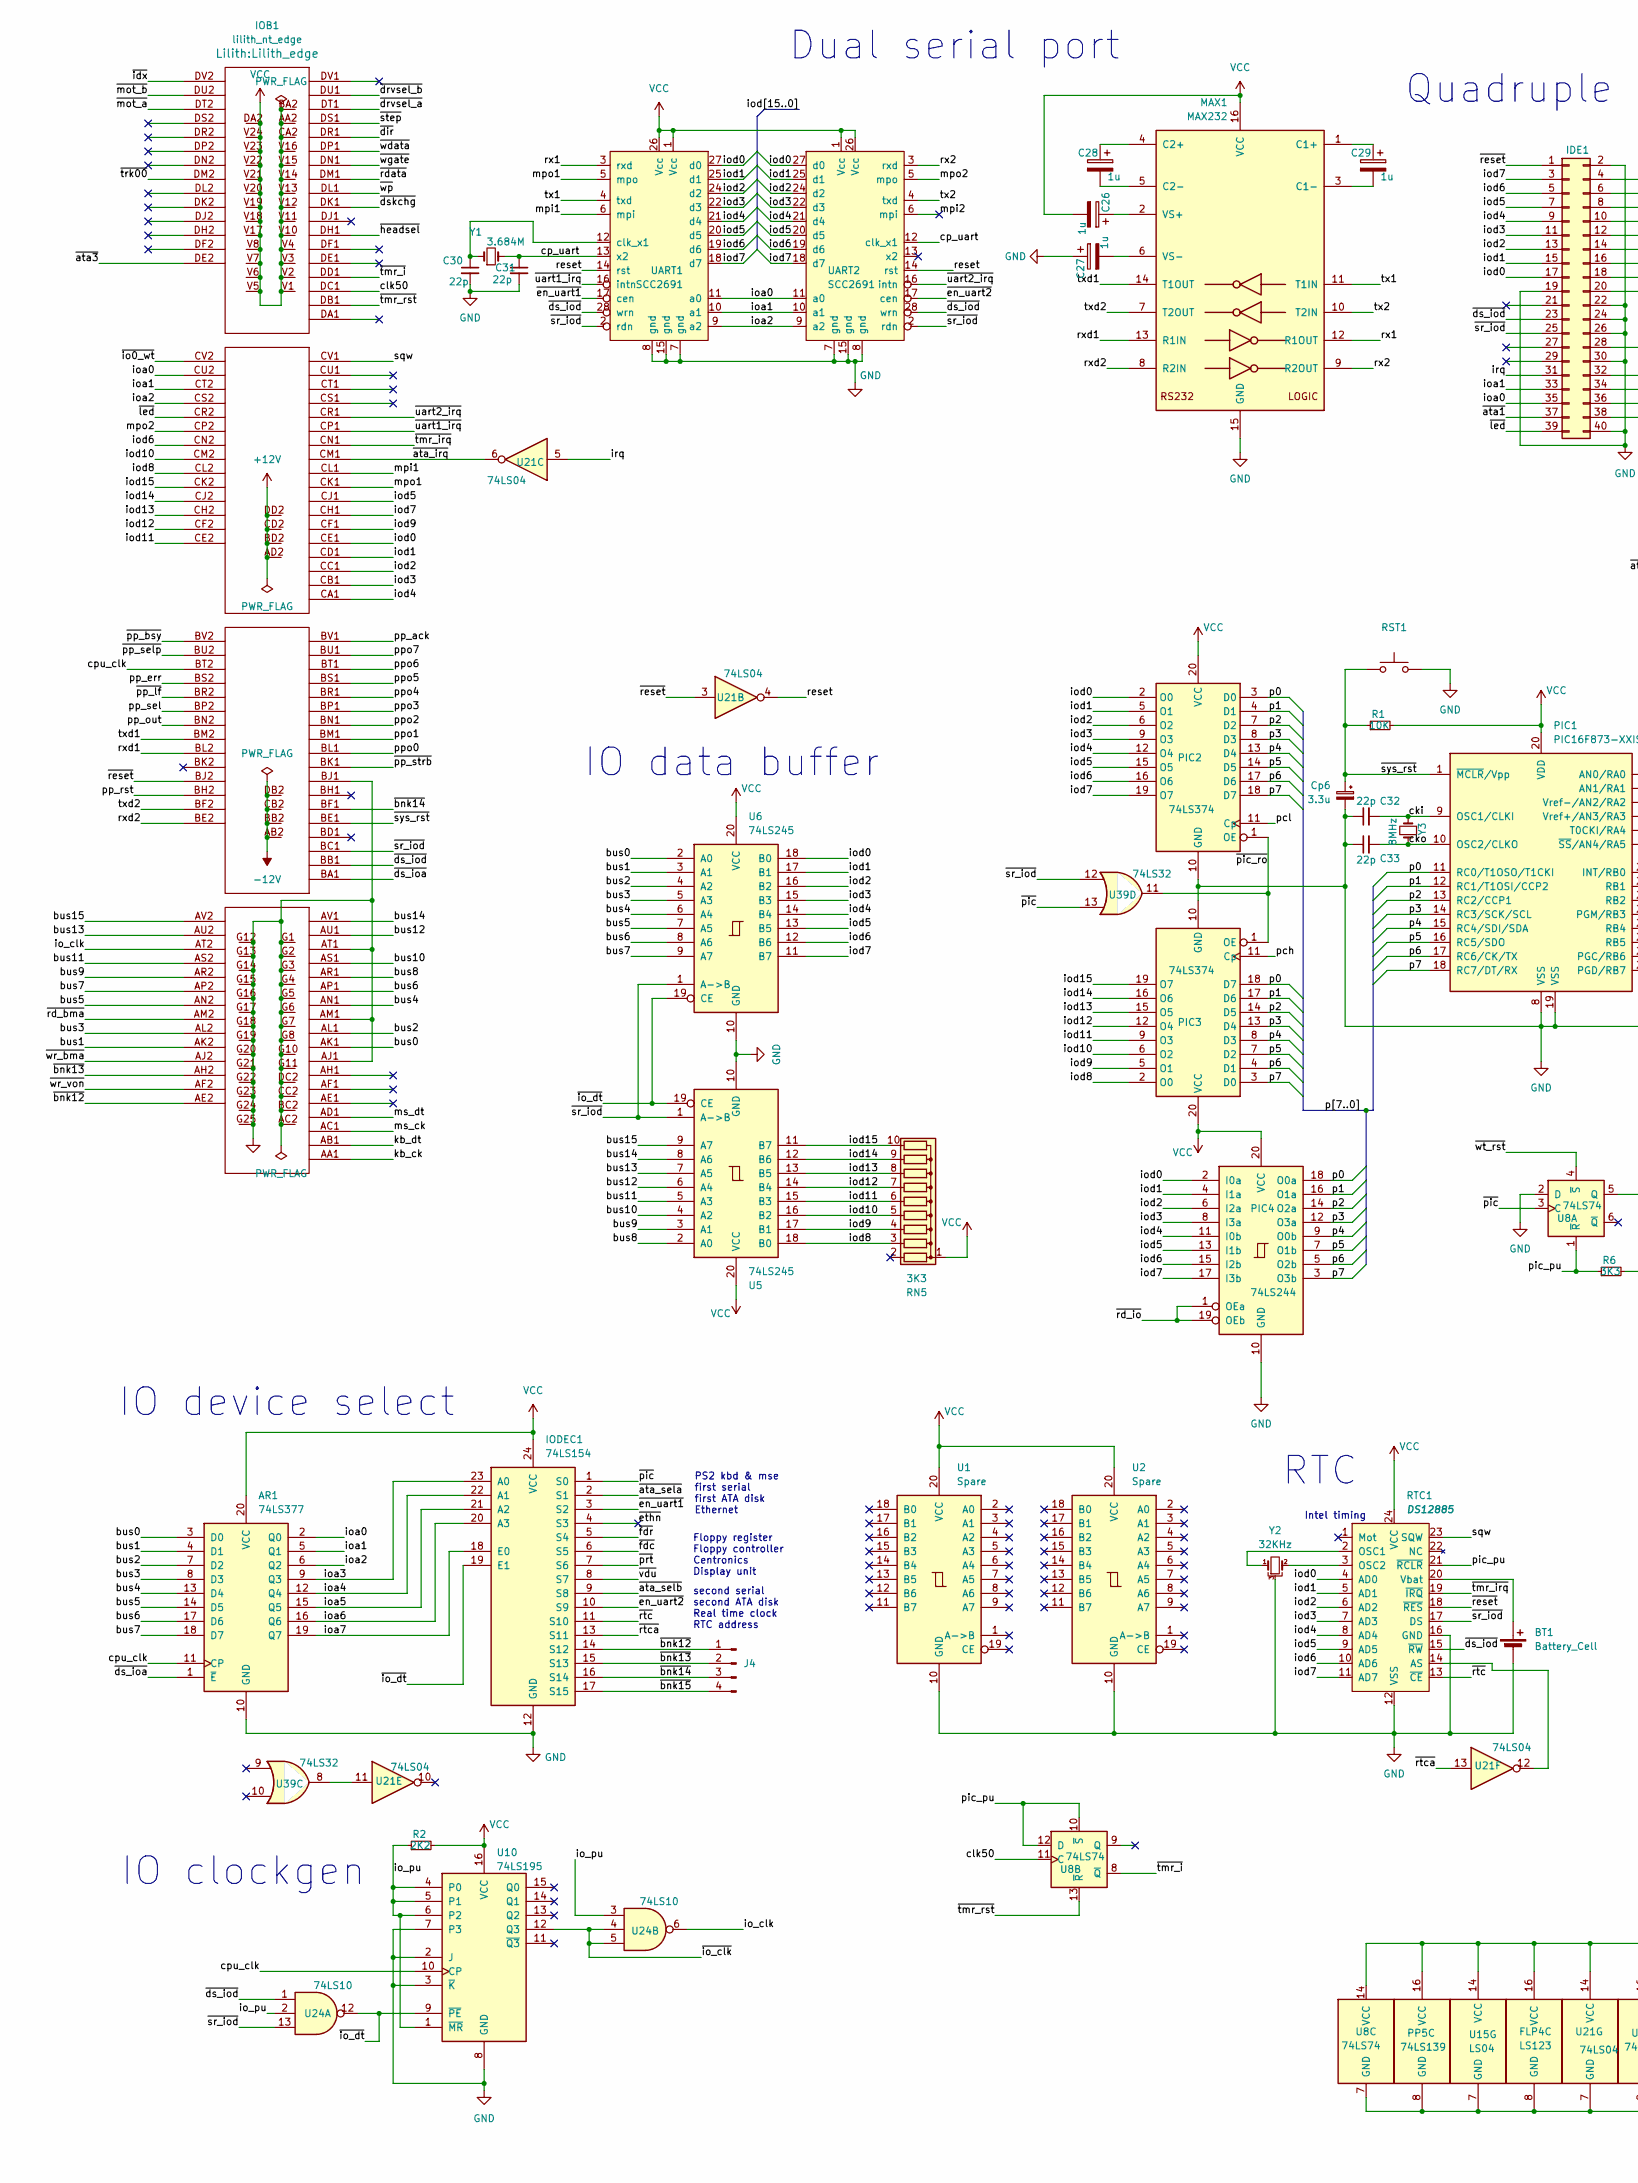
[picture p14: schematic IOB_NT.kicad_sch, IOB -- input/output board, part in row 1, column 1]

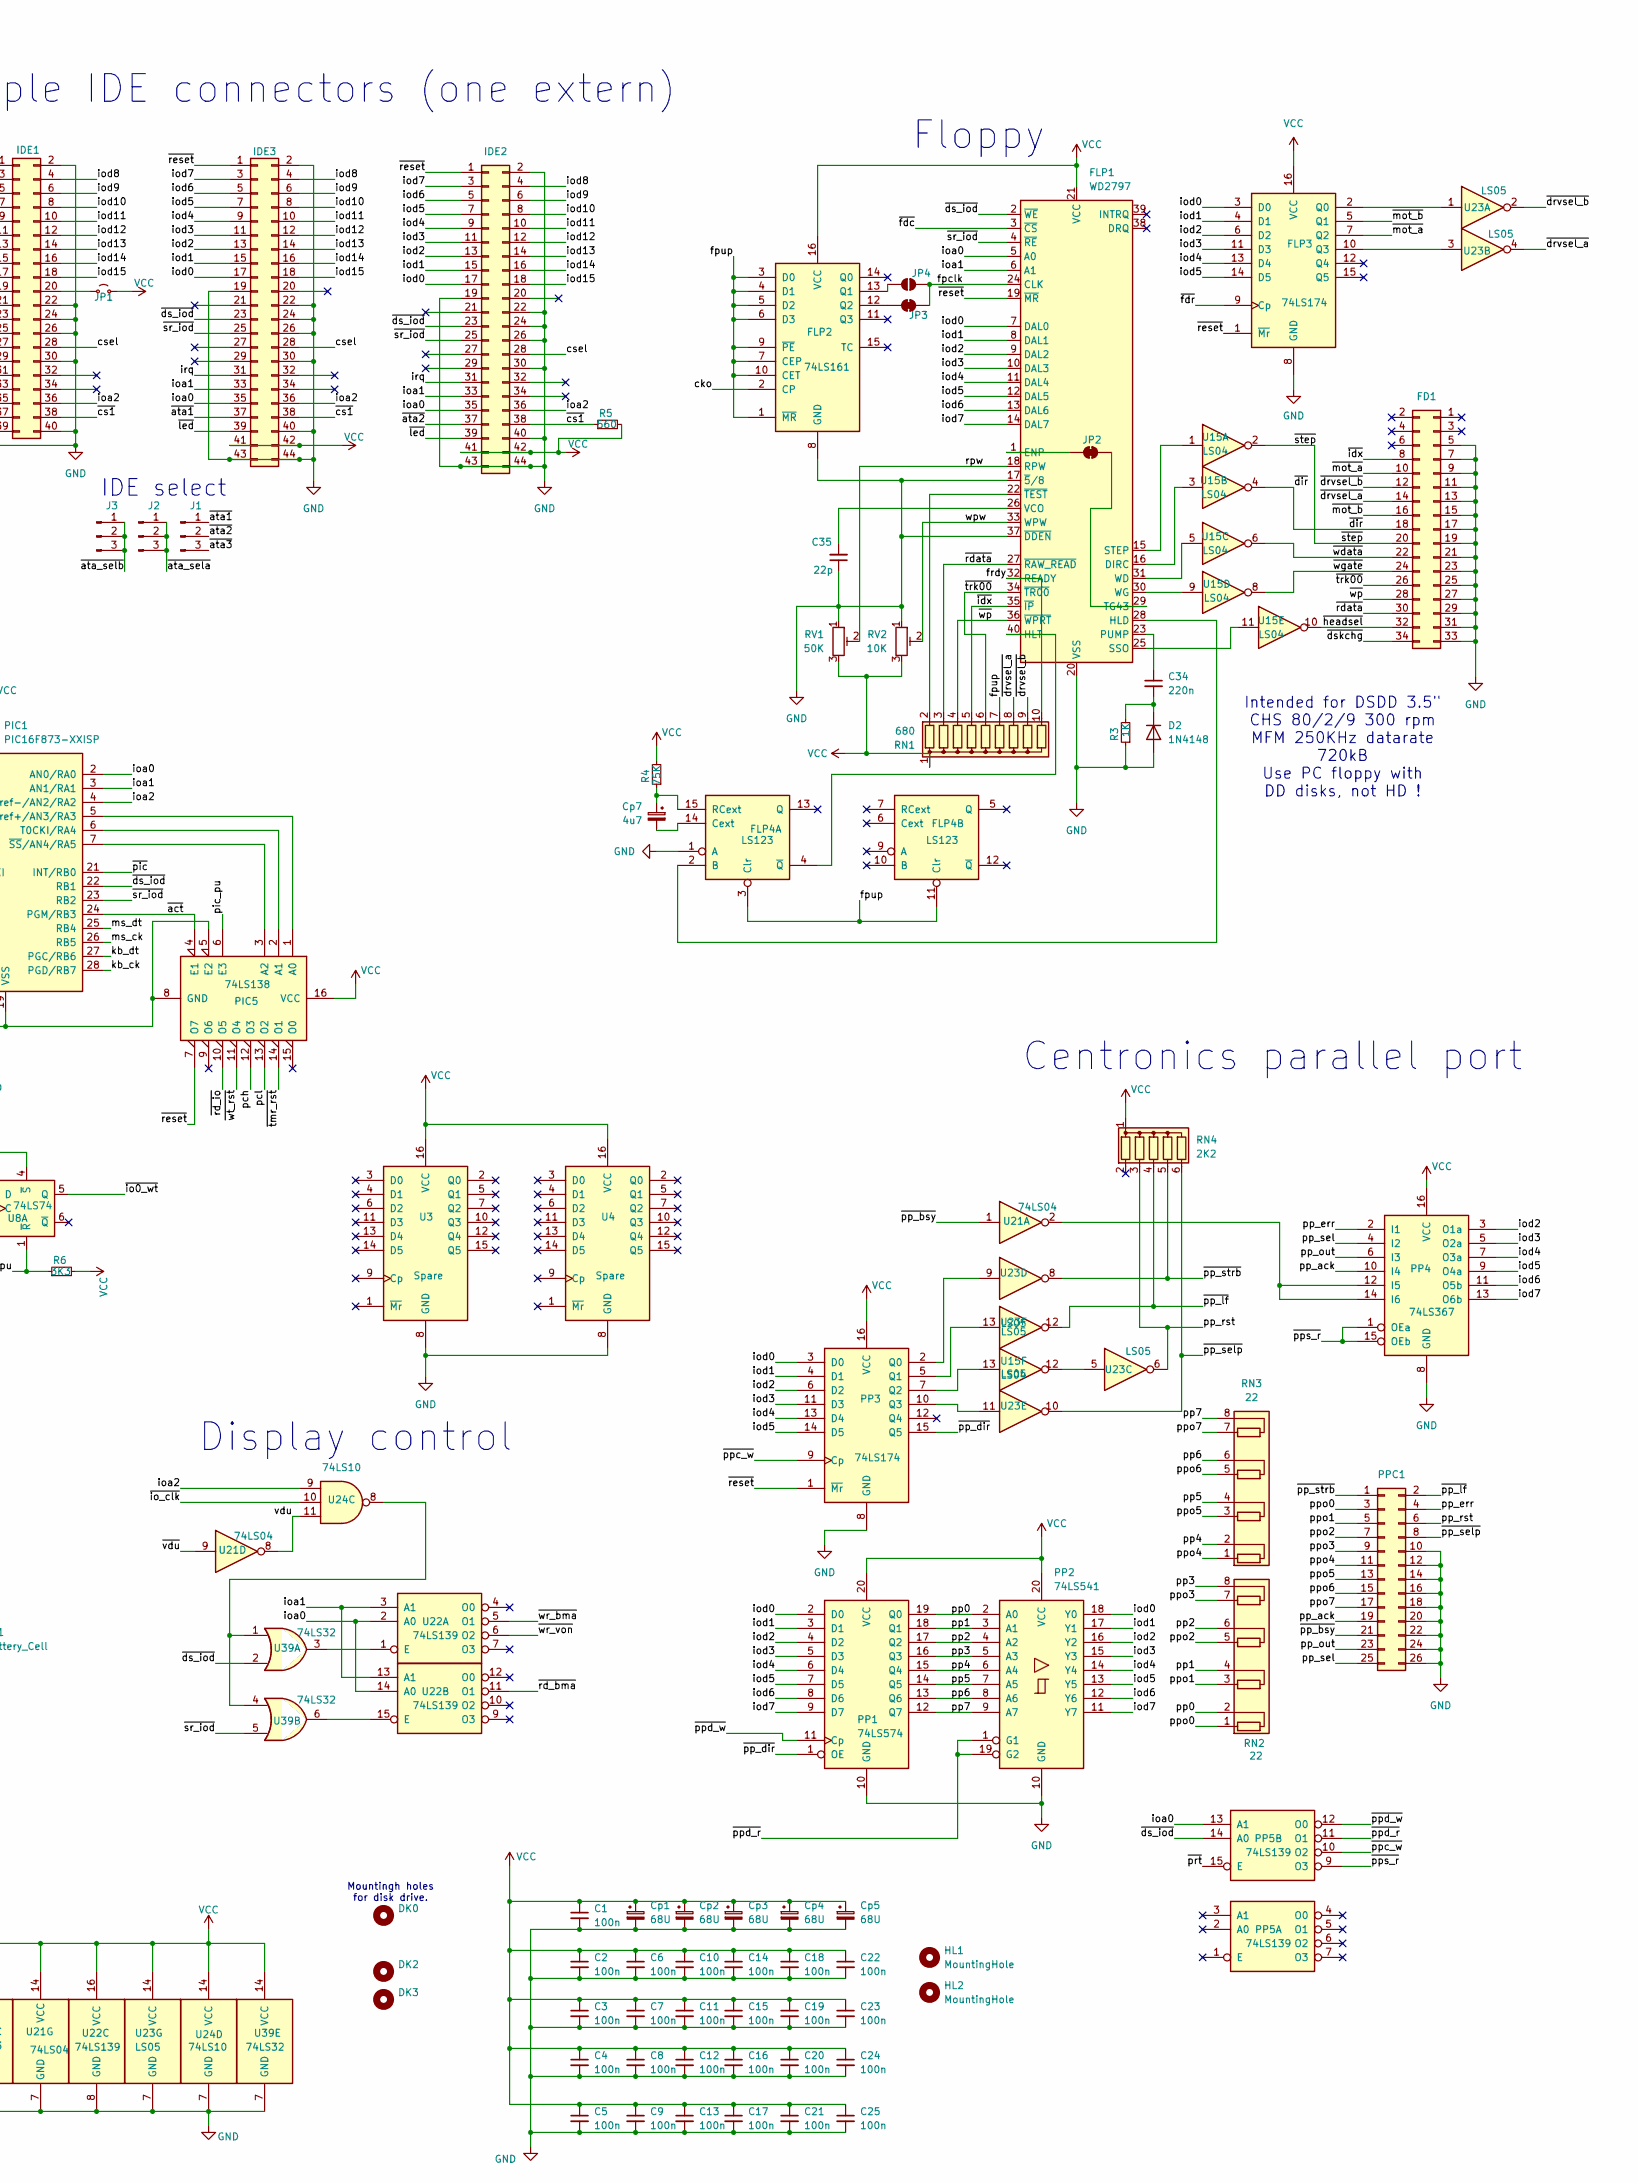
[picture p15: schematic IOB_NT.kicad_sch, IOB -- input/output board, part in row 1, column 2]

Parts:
AR1: 74LS377; DIP-20_W7.62mm
BT1: Battery_Cell; BatteryHolder_MYOUNG_BS-07-A1BJ001_CR2032
C1, C2, C3, C4, C5, C6, C7, C8, C9, C10, C11, C12, C13, C14, C15, C16, C17, C18, C19, C20, C21, C22, C23, C24, C25: 100n; C_1206_3216Metric_Pad1.33x1.80mm_HandSolder
C26, C27, C28, C29: 1u; CP_Radial_Tantal_D4.5mm_P2.50mm
C30, C31: 22p; C_0805_2012Metric_Pad1.18x1.45mm_HandSolder
C32, C33: 22p; C_0805_2012Metric
C34: 220n; C_Rect_L7.0mm_W2.5mm_P5.00mm
C35: 22p; C_Disc_D3.0mm_W2.0mm_P2.50mm
Cp1, Cp2, Cp3, Cp4, Cp5: 68U; CP_PHP
Cp6: 3.3u; CP_Radial_D5.0mm_P2.50mm
Cp7: 4u7; CP_Radial_Tantal_D4.5mm_P2.50mm
D2: 1N4148; D_DO-35_SOD27_P7.62mm_Horizontal
DK0, DK2, DK3: MountingHole; MountingHole_2.7mm_M2.5
FD1: Conn_02x17_Odd_Even; IDC-Header_2x17_P2.54mm_Vertical
FLP1: WD2797; DIP-40_W15.24mm
FLP2: 74LS161; DIP-16_W7.62mm
FLP3: 74LS174; DIP-16_W7.62mm
FLP4: LS123; DIP-16_W7.62mm
HL1, HL2: MountingHole; Handle
IDE1: Conn_02x20_Odd_Even; IDC-Header_2x20_P2.54mm_Horizontal
IDE2, IDE3: Conn_02x22_Odd_Even; PinHeader_2x22_P2.00mm_Vertical
IOB1: lilith_nt_edge; Lilith_edge
IODEC1: 74LS154; DIP-24_W15.24mm
J1, J2, J3: Conn_01x03_Pin; PinHeader_1x03_P2.54mm_Vertical
J4: Conn_01x04_Pin; PinHeader_1x04_P2.54mm_Vertical
JP1: Jumper_2_Small_Open; PinHeader_1x02_P2.54mm_Vertical
JP2, JP3: SolderJumper_2_Bridged; SolderJumper-2_P1.3mm_Bridged_RoundedPad1.0x1.5mm
JP4: SolderJumper_2_Open; SolderJumper-2_P1.3mm_Open_RoundedPad1.0x1.5mm
MAX1: MAX232; DIP-16_W7.62mm
PIC1: PIC16F873-XXISP; DIP-28_W7.62mm_Socket
PIC2, PIC3: 74LS374; DIP-20_W7.62mm
PIC4: 74LS244; DIP-20_W7.62mm
PIC5: 74LS138; DIP-16_W7.62mm
PP1: 74LS574; DIP-20_W7.62mm
PP2: 74LS541; DIP-20_W7.62mm
PP3: 74LS174; DIP-16_W7.62mm
PP4: 74LS367; DIP-16_W7.62mm
PP5: 74LS139; DIP-16_W7.62mm
PPC1: Conn_02x13_Odd_Even; IDC-Header_2x13_P2.54mm_Vertical
R1: 10K; R_Axial_DIN0204_L3.6mm_D1.6mm_P7.62mm_Horizontal
R2: 2K2; R_Axial_DIN0204_L3.6mm_D1.6mm_P7.62mm_Horizontal
R3: 1K; R_Axial_DIN0204_L3.6mm_D1.6mm_P7.62mm_Horizontal
R4: 75K; R_Axial_DIN0204_L3.6mm_D1.6mm_P7.62mm_Horizontal
R5: 560; R_Axial_DIN0204_L3.6mm_D1.6mm_P7.62mm_Horizontal
R6: 3K3; R_Axial_DIN0204_L3.6mm_D1.6mm_P7.62mm_Horizontal
RN1: 680; R_Array_SIP10
RN2, RN3: 22; R_Array_SIP8
RN4: 2K2; R_Array_SIP6
RN5: 3K3; R_Array_SIP10
RST1: SW_Push; SW_PUSH_6mm
RTC1: DS12885; DIP-24_W15.24mm
RV1: 50K; Potentiometer_Bourns_3006P_Horizontal
RV2: 10K; Potentiometer_Bourns_3006P_Horizontal
U1, U2: Spare; DIP-20_W7.62mm
U3, U4: Spare; DIP-16_W7.62mm
U5, U6: 74LS245; DIP-20_W7.62mm
U8: 74LS74; DIP-14_W7.62mm
U10: 74LS195; DIP-16_W7.62mm
U15: LS04; DIP-14_W7.62mm
U21: 74LS04; DIP-14_W7.62mm
U22: 74LS139; DIP-16_W7.62mm
U23: LS05; DIP-14_W7.62mm
U24: 74LS10; DIP-14_W7.62mm
U39: 74LS32; DIP-14_W7.62mm
UART1, UART2: SCC2691; PLCC-28_THT-Socket
Y1: 3.684M; Crystal_HC49-U_Vertical
Y2: 32KHz; Crystal_AT310_D3.0mm_L10.0mm_Horizontal_1EP_style2
Y3: 8MHz; Crystal_HC52-6mm_Vertical

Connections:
+12V: IOB1.AD2, IOB1.BD2, IOB1.CD2, IOB1.DD2
-12V: IOB1.AB2, IOB1.BB2, IOB1.CB2, IOB1.DB2
/bus0: AR1.3 (D0), IOB1.AK1, U6.2 (A0)
/bus1: AR1.4 (D1), IOB1.AK2, U6.3 (A1)
/bus2: AR1.7 (D2), IOB1.AL1, U6.4 (A2)
/bus3: AR1.8 (D3), IOB1.AL2, U6.5 (A3)
/bus4: AR1.13 (D4), IOB1.AN1, U6.6 (A4)
/bus5: AR1.14 (D5), IOB1.AN2, U6.7 (A5)
/bus6: AR1.17 (D6), IOB1.AP1, U6.8 (A6)
/bus7: AR1.18 (D7), IOB1.AP2, U6.9 (A7)
/bus8: IOB1.AR1, U5.2 (A0)
/bus9: IOB1.AR2, U5.3 (A1)
/bus10: IOB1.AS1, U5.4 (A2)
/bus11: IOB1.AS2, U5.5 (A3)
/bus12: IOB1.AU1, U5.6 (A4)
/bus13: IOB1.AU2, U5.7 (A5)
/bus14: IOB1.AV1, U5.8 (A6)
/bus15: IOB1.AV2, U5.9 (A7)
/cki: C32.2, PIC1.9 (OSC1/CLKI), Y3.2
/cko: C33.2, FLP2.2 (CP), PIC1.10 (OSC2/CLKO), Y3.1
/clk50: IOB1.DC1, U8.11 (C)
/cp_uart: C31.1, UART1.13 (x2), UART2.12 (clk_x1), Y1.2
/cpu_clk: AR1.11 (CP), IOB1.BT2, U10.10 (CP)
/csel: IDE1.28, IDE2.28, IDE3.28
/fpclk: FLP1.24 (CLK), JP3.2 (B), JP4.2 (B)
/fpup: FLP2.1 (~MR), FLP2.3 (D0), FLP2.4 (D1), FLP2.5 (D2), FLP2.6 (D3), FLP2.7 (CEP), FLP2.9 (~PE), FLP2.10 (CET), FLP4.3 (Clr), FLP4.11 (Clr), RN1.7 (R6)
/frdy: FLP1.32 (READY), RN1.10 (R9)
/io_clk: IOB1.AT2, U24.6
/io_pu: R2.1, U10.1 (~MR), U10.4 (P0), U10.5 (P1), U10.6 (P2), U24.2, U24.3
/ioa0: AR1.2 (Q0), FLP1.5 (A0), IDE1.35, IDE2.35, IDE3.35, IOB1.CU2, PIC1.2 (AN0/RA0), PP5.13 (A1), U22.2 (A0), U22.14 (A0), UART1.11 (a0), UART2.11 (a0)
/ioa1: AR1.5 (Q1), FLP1.6 (A1), IDE1.33, IDE2.33, IDE3.33, IOB1.CT2, PIC1.3 (AN1/RA1), U22.3 (A1), U22.13 (A1), UART1.10 (a1), UART2.10 (a1)
/ioa2: AR1.6 (Q2), IDE1.36, IDE2.36, IDE3.36, IOB1.CS2, PIC1.4 (Vref-/AN2/RA2), U24.9, UART1.9 (a2), UART2.9 (a2)
/ioa3: AR1.9 (Q3), IODEC1.23 (A0)
/ioa4: AR1.12 (Q4), IODEC1.22 (A1)
/ioa5: AR1.15 (Q5), IODEC1.21 (A2)
/ioa6: AR1.16 (Q6), IODEC1.20 (A3)
/ioa7: AR1.19 (Q7), IODEC1.18 (E0)
/iod0: FLP1.7 (DAL0), FLP3.3 (D0), IDE1.17, IDE2.17, IDE3.17, IOB1.CE1, PIC2.2 (O0), PIC4.2 (I0a), PP1.2 (D0), PP2.18 (Y0), PP3.3 (D0), RTC1.4 (AD0), U6.18 (B0), UART1.27 (d0), UART2.27 (d0)
/iod1: FLP1.8 (DAL1), FLP3.4 (D1), IDE1.15, IDE2.15, IDE3.15, IOB1.CD1, PIC2.5 (O1), PIC4.4 (I1a), PP1.3 (D1), PP2.17 (Y1), PP3.4 (D1), RTC1.5 (AD1), U6.17 (B1), UART1.25 (d1), UART2.25 (d1)
/iod2: FLP1.9 (DAL2), FLP3.6 (D2), IDE1.13, IDE2.13, IDE3.13, IOB1.CC1, PIC2.6 (O2), PIC4.6 (I2a), PP1.4 (D2), PP2.16 (Y2), PP3.6 (D2), PP4.3 (O1a), RTC1.6 (AD2), U6.16 (B2), UART1.24 (d2), UART2.24 (d2)
/iod3: FLP1.10 (DAL3), FLP3.11 (D3), IDE1.11, IDE2.11, IDE3.11, IOB1.CB1, PIC2.9 (O3), PIC4.8 (I3a), PP1.5 (D3), PP2.15 (Y3), PP3.11 (D3), PP4.5 (O2a), RTC1.7 (AD3), U6.15 (B3), UART1.22 (d3), UART2.22 (d3)
/iod4: FLP1.11 (DAL4), FLP3.13 (D4), IDE1.9, IDE2.9, IDE3.9, IOB1.CA1, PIC2.12 (O4), PIC4.11 (I0b), PP1.6 (D4), PP2.14 (Y4), PP3.13 (D4), PP4.7 (O3a), RTC1.8 (AD4), U6.14 (B4), UART1.21 (d4), UART2.21 (d4)
/iod5: FLP1.12 (DAL5), FLP3.14 (D5), IDE1.7, IDE2.7, IDE3.7, IOB1.CJ1, PIC2.15 (O5), PIC4.13 (I1b), PP1.7 (D5), PP2.13 (Y5), PP3.14 (D5), PP4.9 (O4a), RTC1.9 (AD5), U6.13 (B5), UART1.20 (d5), UART2.20 (d5)
/iod6: FLP1.13 (DAL6), IDE1.5, IDE2.5, IDE3.5, IOB1.CN2, PIC2.16 (O6), PIC4.15 (I2b), PP1.8 (D6), PP2.12 (Y6), PP4.11 (O5b), RTC1.10 (AD6), U6.12 (B6), UART1.19 (d6), UART2.19 (d6)
/iod7: FLP1.14 (DAL7), IDE1.3, IDE2.3, IDE3.3, IOB1.CH1, PIC2.19 (O7), PIC4.17 (I3b), PP1.9 (D7), PP2.11 (Y7), PP4.13 (O6b), RTC1.11 (AD7), U6.11 (B7), UART1.18 (d7), UART2.18 (d7)
/iod8: IDE1.4, IDE2.4, IDE3.4, IOB1.CL2, PIC3.2 (O0), RN5.3 (R2), U5.18 (B0)
/iod9: IDE1.6, IDE2.6, IDE3.6, IOB1.CF1, PIC3.5 (O1), RN5.4 (R3), U5.17 (B1)
/iod10: IDE1.8, IDE2.8, IDE3.8, IOB1.CM2, PIC3.6 (O2), RN5.5 (R4), U5.16 (B2)
/iod11: IDE1.10, IDE2.10, IDE3.10, IOB1.CE2, PIC3.9 (O3), RN5.6 (R5), U5.15 (B3)
/iod12: IDE1.12, IDE2.12, IDE3.12, IOB1.CF2, PIC3.12 (O4), RN5.7 (R6), U5.14 (B4)
/iod13: IDE1.14, IDE2.14, IDE3.14, IOB1.CH2, PIC3.15 (O5), RN5.8 (R7), U5.13 (B5)
/iod14: IDE1.16, IDE2.16, IDE3.16, IOB1.CJ2, PIC3.16 (O6), RN5.9 (R8), U5.12 (B6)
/iod15: IDE1.18, IDE2.18, IDE3.18, IOB1.CK2, PIC3.19 (O7), RN5.10 (R9), U5.11 (B7)
/irq: IDE1.31, IDE2.31, IDE3.31, U21.5
/kb_ck: IOB1.AA1, PIC1.28 (PGD/RB7)
/kb_dt: IOB1.AB1, PIC1.27 (PGC/RB6)
/mpi1: IOB1.CL1, UART1.6 (mpi)
/mpi2: UART2.6 (mpi)
/mpo1: IOB1.CK1, UART1.5 (mpo)
/mpo2: IOB1.CP2, UART2.5 (mpo)
/ms_ck: IOB1.AC1, PIC1.26 (RB5)
/ms_dt: IOB1.AD1, PIC1.25 (RB4)
/p0: PIC1.11 (RC0/T1OSO/T1CKI), PIC2.3 (D0), PIC3.18 (D7), PIC4.18 (O0a)
/p1: PIC1.12 (RC1/T1OSI/CCP2), PIC2.4 (D1), PIC3.17 (D6), PIC4.16 (O1a)
/p2: PIC1.13 (RC2/CCP1), PIC2.7 (D2), PIC3.14 (D5), PIC4.14 (O2a)
/p3: PIC1.14 (RC3/SCK/SCL), PIC2.8 (D3), PIC3.13 (D4), PIC4.12 (O3a)
/p4: PIC1.15 (RC4/SDI/SDA), PIC2.13 (D4), PIC3.8 (D3), PIC4.9 (O0b)
/p5: PIC1.16 (RC5/SDO), PIC2.14 (D5), PIC3.7 (D2), PIC4.7 (O1b)
/p6: PIC1.17 (RC6/CK/TX), PIC2.17 (D6), PIC3.4 (D1), PIC4.5 (O2b)
/p7: PIC1.18 (RC7/DT/RX), PIC2.18 (D7), PIC3.3 (D0), PIC4.3 (O3b)
/pch: PIC3.11 (Cp), PIC5.12 (O3)
/pcl: PIC2.11 (Cp), PIC5.13 (O2)
/pic_pu: PIC5.6 (E3), R6.1, RTC1.21 (~RCLR), U8.1 (~R), U8.10 (~S), U8.12 (D)
/pp0: PP1.19 (Q0), PP2.2 (A0), RN2.2 (R1.2)
/pp1: PP1.18 (Q1), PP2.3 (A1), RN2.4 (R2.2)
/pp2: PP1.17 (Q2), PP2.4 (A2), RN2.6 (R3.2)
/pp3: PP1.16 (Q3), PP2.5 (A3), RN2.8 (R4.2)
/pp4: PP1.15 (Q4), PP2.6 (A4), RN3.2 (R1.2)
/pp5: PP1.14 (Q5), PP2.7 (A5), RN3.4 (R2.2)
/pp6: PP1.13 (Q6), PP2.8 (A6), RN3.6 (R3.2)
/pp7: PP1.12 (Q7), PP2.9 (A7), RN3.8 (R4.2)
/pp_ack: IOB1.BV1, PP4.10 (I4), PPC1.19
/pp_err: IOB1.BS2, PP4.2 (I1), PPC1.4
/pp_out: IOB1.BN2, PP4.6 (I3), PPC1.23
/pp_rst: IOB1.BH2, PPC1.6, RN4.3 (R2), U23.6
/pp_sel: IOB1.BP2, PP4.4 (I2), PPC1.25
/ppo0: IOB1.BL1, PPC1.3, RN2.1 (R1.1)
/ppo1: IOB1.BM1, PPC1.5, RN2.3 (R2.1)
/ppo2: IOB1.BN1, PPC1.7, RN2.5 (R3.1)
/ppo3: IOB1.BP1, PPC1.9, RN2.7 (R4.1)
/ppo4: IOB1.BR1, PPC1.11, RN3.1 (R1.1)
/ppo5: IOB1.BS1, PPC1.13, RN3.3 (R2.1)
/ppo6: IOB1.BT1, PPC1.15, RN3.5 (R3.1)
/ppo7: IOB1.BU1, PPC1.17, RN3.7 (R4.1)
/reset: U21.4, UART1.14 (rst), UART2.14 (rst)
/rpw: FLP1.18 (RPW), RV1.2
/rx1: MAX1.12 (R1OUT), UART1.3 (rxd)
/rx2: MAX1.9 (R2OUT), UART2.3 (rxd)
/rxd1: IOB1.BL2, MAX1.13 (R1IN)
/rxd2: IOB1.BE2, MAX1.8 (R2IN)
/sqw: IOB1.CV1, RTC1.23 (SQW)
/tx1: MAX1.11 (T1IN), UART1.4 (txd)
/tx2: MAX1.10 (T2IN), UART2.4 (txd)
/txd1: IOB1.BM2, MAX1.14 (T1OUT)
/txd2: IOB1.BF2, MAX1.7 (T2OUT)
/vdu: U21.8, U24.11
/wpw: FLP1.33 (WPW), RV2.2
/~act: PIC1.24 (PGM/RB3), PIC5.4 (E1)
/~ata1: IDE1.37, IDE3.37, J1.1
/~ata2: IDE2.37, J1.2
/~ata3: IOB1.DE2, J1.3
/~ata_irq: IOB1.CM1, U21.6
/~ata_sela: IODEC1.2 (S1), J2.1, J2.2, J2.3
/~ata_selb: IODEC1.9 (S8), J3.1, J3.2, J3.3
/~bnk12: IOB1.AE2, IODEC1.14 (S12), J4.1
/~bnk13: IOB1.AH2, IODEC1.15 (S13), J4.2
/~bnk14: IOB1.BF1, IODEC1.16 (S14), J4.3
/~bnk15: IODEC1.17 (S15), J4.4
/~cs1: IDE1.38, IDE2.38, IDE3.38, R5.1
/~dir: FD1.18, IOB1.DR1, U15.4
/~drvsel_a: FD1.14, IOB1.DT1, RN1.8 (R7), U23.4
/~drvsel_b: FD1.12, IOB1.DU1, RN1.9 (R8), U23.2
/~ds_ioa: AR1.1 (~E), IOB1.BA1
/~ds_iod: FLP1.2 (~WE), IDE1.23, IDE2.23, IDE3.23, IOB1.BB1, PIC1.22 (RB1), PP5.14 (A0), RTC1.15 (~RW), U24.1, U39.2, UART1.28 (wrn), UART2.28 (wrn)
/~dskchg: FD1.34, IOB1.DK1
/~en_uart1: IODEC1.3 (S2), UART1.17 (cen)
/~en_uart2: IODEC1.10 (S9), UART2.17 (cen)
/~ethn: IODEC1.4 (S3)
/~fdc: FLP1.3 (~CS), IODEC1.6 (S5)
/~fdr: FLP3.9 (Cp), IODEC1.5 (S4)
/~headsel: FD1.32, IOB1.DH1, U15.10
/~idx: FD1.8, FLP1.35 (~IP), IOB1.DV2, RN1.5 (R4)
/~io0_wt: IOB1.CV2, U8.5 (Q)
/~io_clk: U10.12 (Q3), U24.4, U24.5, U24.10
/~io_dt: IODEC1.19 (E1), U5.19 (CE), U6.19 (CE), U10.9 (~PE), U24.12
/~led: IDE1.39, IDE2.39, IDE3.39, IOB1.CR2
/~mot_a: FD1.10, FLP3.7 (Q2), IOB1.DT2
/~mot_b: FD1.16, FLP3.5 (Q1), IOB1.DU2
/~pic_ro: PIC2.1 (OE), PIC3.1 (OE), U39.11
/~pic: IODEC1.1 (S0), PIC1.21 (INT/RB0), U8.3 (C), U39.13
/~pp_bsy: IOB1.BV2, PPC1.21, U21.1
/~pp_dir: PP1.1 (OE), PP3.15 (Q5)
/~pp_lf: IOB1.BR2, PPC1.2, RN4.4 (R3), U23.12
/~pp_selp: IOB1.BU2, PPC1.8, RN4.6 (R5), U23.10
/~pp_strb: IOB1.BK1, PPC1.1, RN4.5 (R4), U23.8
/~ppc_w: PP3.9 (Cp), PP5.10 (O2)
/~ppd_r: PP2.1 (G1), PP2.19 (G2), PP5.11 (O1)
/~ppd_w: PP1.11 (Cp), PP5.12 (O0)
/~pps_r: PP4.1 (OEa), PP4.15 (OEb), PP5.9 (O3)
/~prt: IODEC1.7 (S6), PP5.15 (E)
/~rd_bma: IOB1.AM2, U22.11 (O1)
/~rd_io: PIC4.1 (OEa), PIC4.19 (OEb), PIC5.10 (O5)
/~rdata: FD1.30, FLP1.27 (~RAW_READ), IOB1.DM1, RN1.3 (R2)
/~reset: FLP1.19 (~MR), FLP3.1 (~Mr), IDE1.1, IDE2.1, IDE3.1, IOB1.BJ2, PIC5.7 (O7), PP3.1 (~Mr), RTC1.18 (~RES), U21.3
/~rtca: IODEC1.13 (S11), U21.13
/~rtc: IODEC1.11 (S10), RTC1.13 (~CE)
/~sr_iod: FLP1.4 (~RE), IDE1.25, IDE2.25, IDE3.25, IOB1.BC1, PIC1.23 (RB2), RTC1.17 (DS), U5.1 (A->B), U6.1 (A->B), U24.13, U39.5, U39.12, UART1.2 (rdn), UART2.2 (rdn)
/~step: FD1.20, IOB1.DS1, U15.2
/~sys_rst: Cp6.1, IOB1.BE1, PIC1.1 (~MCLR/Vpp), R1.1, RST1.1
/~tmr_irq: IOB1.CN1, RTC1.19 (~IRQ)
/~tmr_i: IOB1.DD1, U8.8 (~Q)
/~tmr_rst: IOB1.DB1, PIC5.14 (O1), U8.13 (~R)
/~trk00: FD1.26, FLP1.34 (~TR00), IOB1.DM2, RN1.6 (R5)
/~uart1_irq: IOB1.CP1, UART1.16 (intn)
/~uart2_irq: IOB1.CR1, UART2.16 (intn)
/~vdu: IODEC1.8 (S7), U21.9
/~wdata: FD1.22, IOB1.DP1, U15.6
/~wgate: FD1.24, IOB1.DN1, U15.8
/~wp: FD1.28, FLP1.36 (~WPRT), IOB1.DL1, RN1.4 (R3)
/~wr_bma: IOB1.AJ2, U22.5 (O1)
/~wr_von: IOB1.AF2, U22.6 (O2)
/~wt_rst: PIC5.11 (O4), U8.4 (~S)
GND: AR1.10 (GND), BT1.2 (-), C1.2, C2.2, C3.2, C4.2, C5.2, C6.2, C7.2, C8.2, C9.2, C10.2, C11.2, C12.2, C13.2, C14.2, C15.2, C16.2, C17.2, C18.2, C19.2, C20.2, C21.2, C22.2, C23.2, C24.2, C25.2, C27.1, C30.2, C31.2, C32.1, C33.1, C35.1, Cp1.2, Cp2.2, Cp3.2, Cp4.2, Cp5.2, Cp6.2, D2.2 (A), FD1.5, FD1.7, FD1.9, FD1.11, FD1.13, FD1.15, FD1.17, FD1.19, FD1.21, FD1.23, FD1.25, FD1.27, FD1.29, FD1.31, FD1.33, FLP1.17 (~5/8), FLP1.20 (VSS), FLP1.37 (~DDEN), FLP2.8 (GND), FLP3.8 (GND), FLP4.1 (A), FLP4.8 (GND), IDE1.2, IDE1.19, IDE1.22, IDE1.24, IDE1.26, IDE1.30, IDE1.40, IDE2.2, IDE2.19, IDE2.22, IDE2.24, IDE2.26, IDE2.30, IDE2.40, IDE2.43, IDE2.44, IDE3.2, IDE3.19, IDE3.22, IDE3.24, IDE3.26, IDE3.30, IDE3.40, IDE3.43, IDE3.44, IOB1.AC2, IOB1.AJ1, IOB1.AM1, IOB1.AT1, IOB1.BC2, IOB1.BJ1, IOB1.CC2, IOB1.DC2, IOB1.G1 (GND), IOB1.G2 (GND), IOB1.G3 (GND), IOB1.G4 (GND), IOB1.G5 (GND), IOB1.G6 (GND), IOB1.G7 (GND), IOB1.G8 (GND), IOB1.G10, IOB1.G11, IOB1.G12, IOB1.G13, IOB1.G14, IOB1.G15, IOB1.G16, IOB1.G17, IOB1.G18, IOB1.G19, IOB1.G20, IOB1.G21, IOB1.G22, IOB1.G23, IOB1.G24, IOB1.G25, IODEC1.12 (GND), MAX1.15 (GND), PIC1.8 (VSS), PIC1.19 (VSS), PIC2.10 (GND), PIC3.10 (GND), PIC4.10 (GND), PIC5.5 (E2), PIC5.8 (GND), PP1.10 (GND), PP2.10 (GND), PP3.8 (GND), PP4.8 (GND), PP5.8 (GND), PPC1.10, PPC1.12, PPC1.14, PPC1.16, PPC1.18, PPC1.20, PPC1.22, PPC1.24, PPC1.26, R3.1, RST1.2, RTC1.12 (VSS), RTC1.16 (GND), RV1.1, RV2.1, U1.10 (GND), U2.10 (GND), U3.8 (GND), U4.8 (GND), U5.10 (GND), U6.10 (GND), U8.2 (D), U8.7 (GND), U10.2 (J), U10.3 (~K), U10.7 (P3), U10.8 (GND), U15.7 (GND), U21.7 (GND), U22.8 (GND), U23.7 (GND), U24.7 (GND), U39.7 (GND), UART1.7 (gnd), UART1.8 (gnd), UART1.15 (gnd), UART2.7 (gnd), UART2.8 (gnd), UART2.15 (gnd), Y2.3
unnamed: BT1.1 (+), RTC1.20 (Vbat)
unnamed: C34.2, D2.1 (K), R3.2
unnamed: FLP1.16 (DIRC), U15.3
unnamed: FLP1.1 (ENP), JP2.1 (A)
unnamed: FLP1.28 (HLD), FLP4.2 (B)
unnamed: FLP1.40 (HLT), FLP4.4 (~Q)
unnamed: C34.1, FLP1.23 (PUMP)
unnamed: FLP1.25 (SSO), U15.11
unnamed: FLP1.15 (STEP), U15.1
unnamed: FLP1.29 (TG43), JP2.2 (B)
unnamed: C35.2, FLP1.26 (VCO)
unnamed: FLP1.31 (WD), U15.5
unnamed: FLP1.30 (WG), U15.9
unnamed: FLP1.22 (~TEST), RN1.2 (R1)
unnamed: FLP2.13 (Q1), JP4.1 (A)
unnamed: FLP2.12 (Q2), JP3.1 (A)
unnamed: FLP3.2 (Q0), U23.1
unnamed: FLP3.10 (Q3), U23.3
unnamed: Cp7.2, FLP4.14 (Cext)
unnamed: Cp7.1, FLP4.15 (RCext), R4.1
unnamed: IDE1.20, JP1.1 (A)
unnamed: C29.1, MAX1.1 (C1+)
unnamed: C29.2, MAX1.3 (C1-)
unnamed: C28.1, MAX1.4 (C2+)
unnamed: C28.2, MAX1.5 (C2-)
unnamed: C26.1, MAX1.2 (VS+)
unnamed: C27.2, MAX1.6 (VS-)
unnamed: PIC1.6 (T0CKI/RA4), PIC5.2 (A1)
unnamed: PIC1.5 (Vref+/AN3/RA3), PIC5.1 (A0)
unnamed: PIC1.7 (~SS/AN4/RA5), PIC5.3 (A2)
unnamed: PP3.2 (Q0), U23.9
unnamed: PP3.5 (Q1), U23.13
unnamed: PP3.7 (Q2), U15.13
unnamed: PP3.10 (Q3), U23.11
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

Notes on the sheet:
Floppy
IO device select
Centronics parallel port
IDE select
PS2 kbd & mse first serial first ATA disk Ethernet
Intended for DSDD 3.5" CHS 80/2/9 300 rpm MFM 250KHz datarate 720kB Use PC floppy with DD disks, not HD !
Dual serial port
Intel timing
RTC
IO data buffer
IO clockgen
Floppy register Floppy controller Centronics Display unit
Mountingh holes for disk drive.
Quadruple IDE connectors (one extern)
second serial second ATA disk Real time clock RTC address
Display control

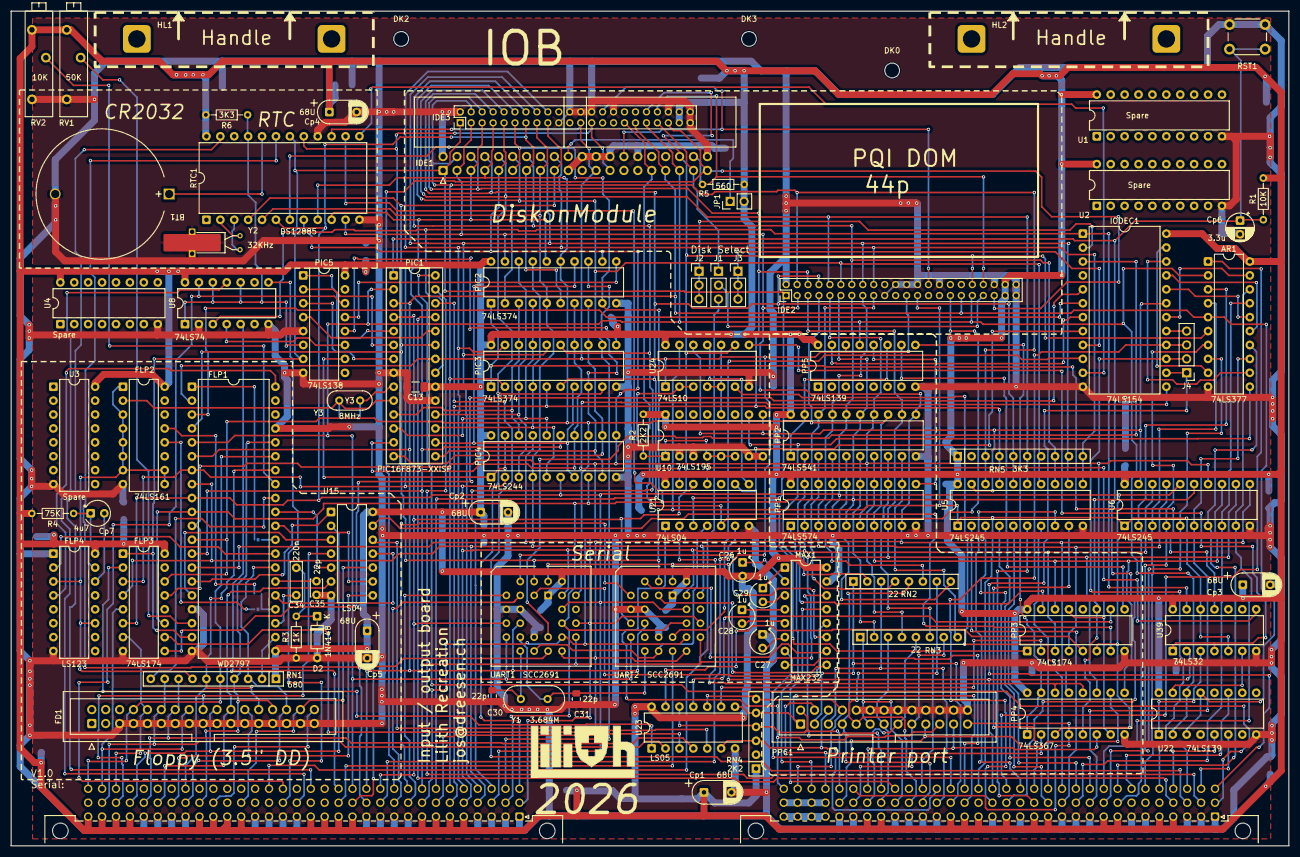
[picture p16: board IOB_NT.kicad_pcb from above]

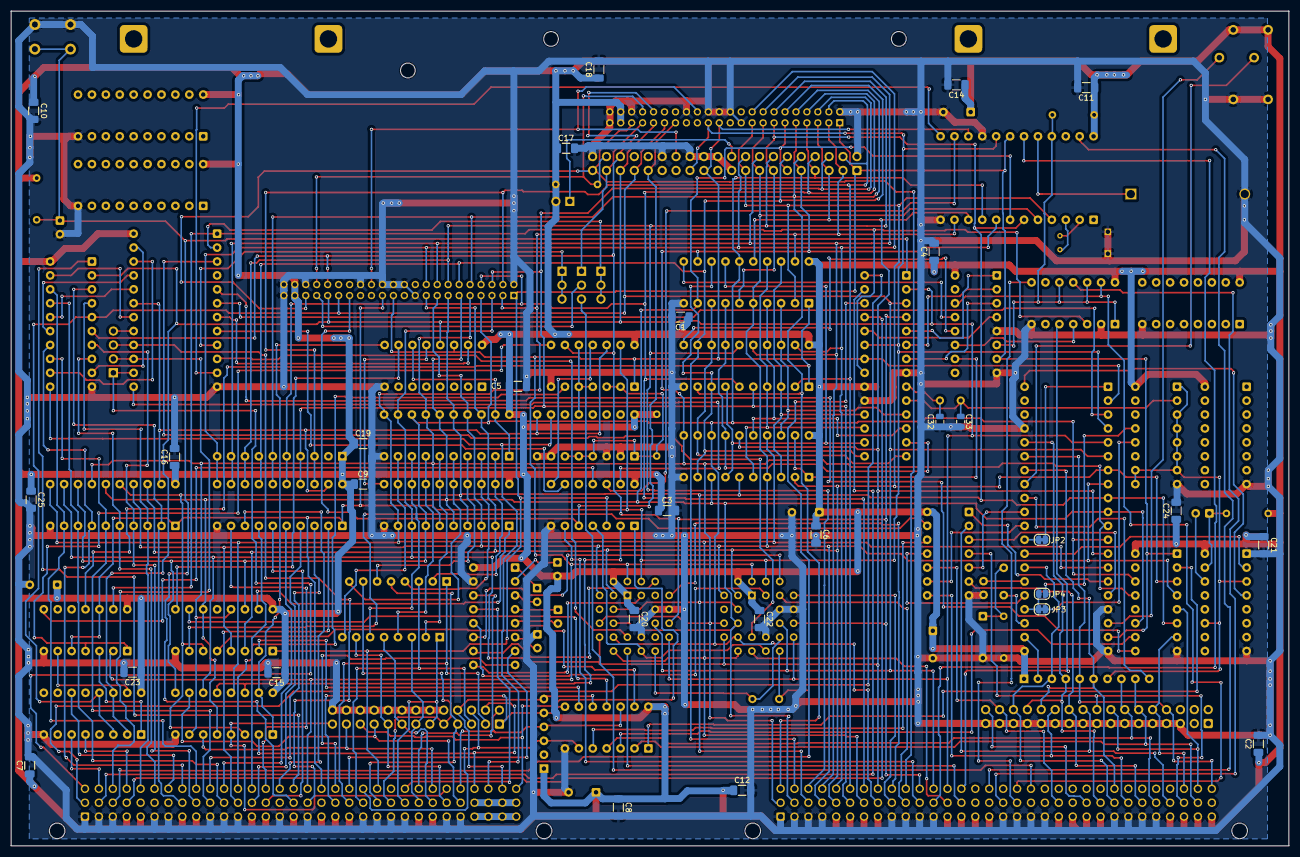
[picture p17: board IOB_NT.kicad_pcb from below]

Board: 2 copper layers, 233.3 x 152.4 mm, 114 parts (29 on the bottom side), 216 nets.

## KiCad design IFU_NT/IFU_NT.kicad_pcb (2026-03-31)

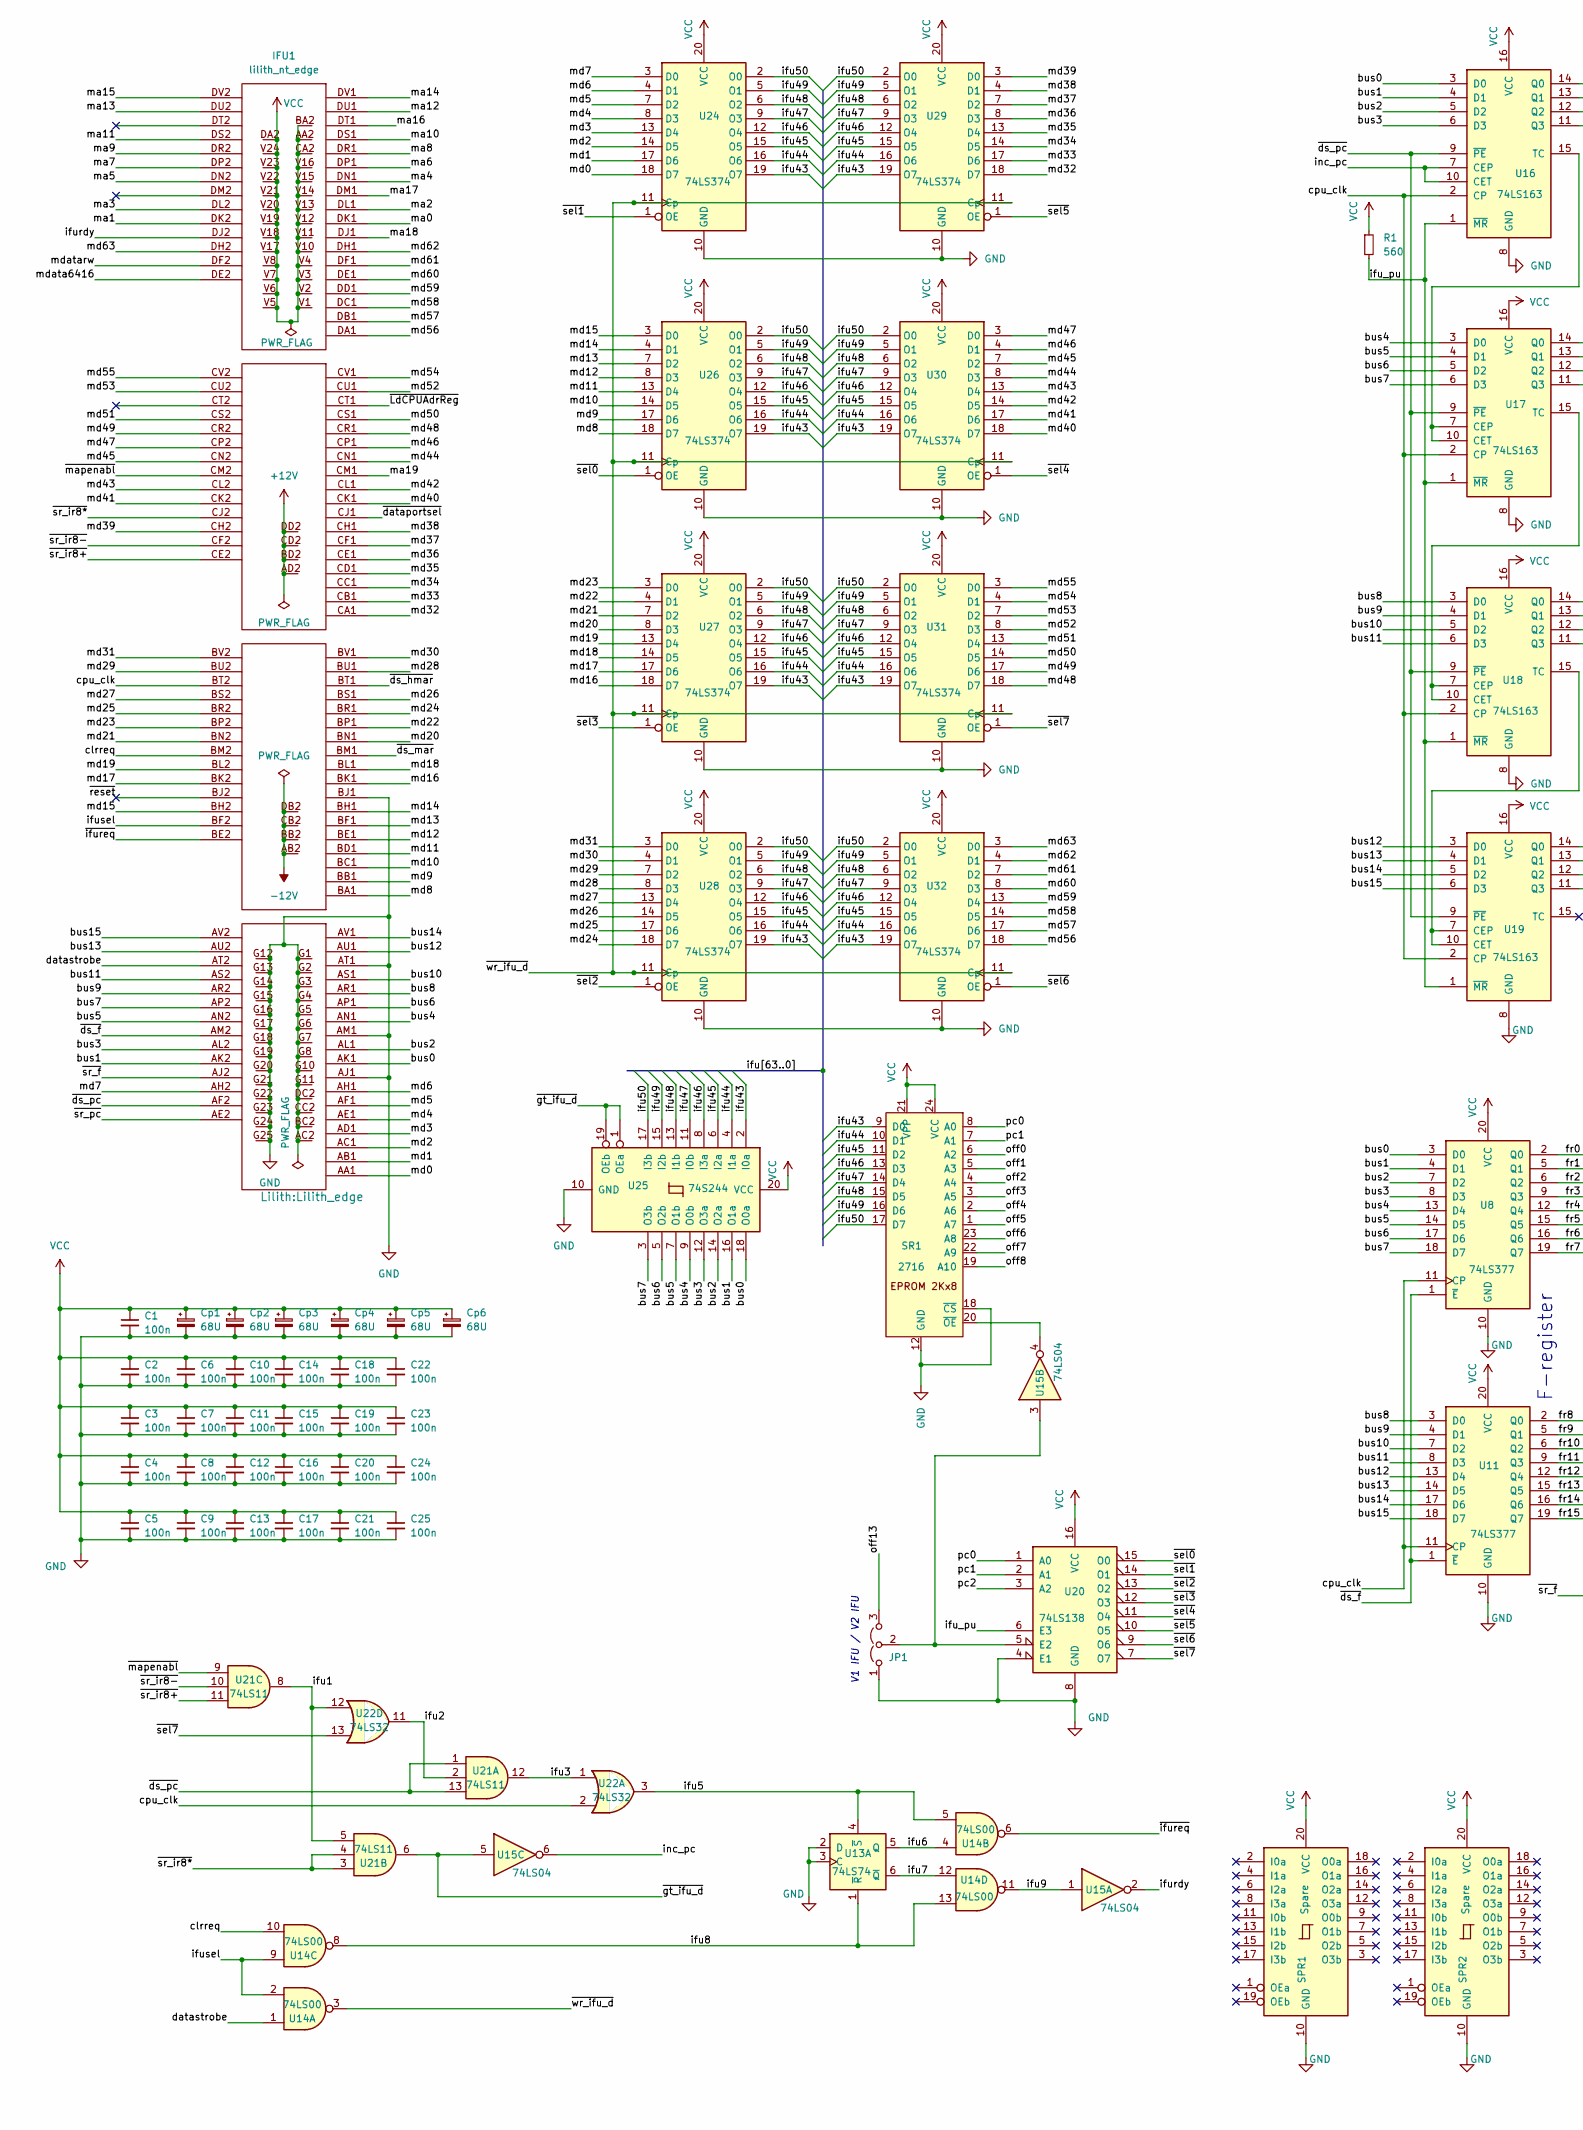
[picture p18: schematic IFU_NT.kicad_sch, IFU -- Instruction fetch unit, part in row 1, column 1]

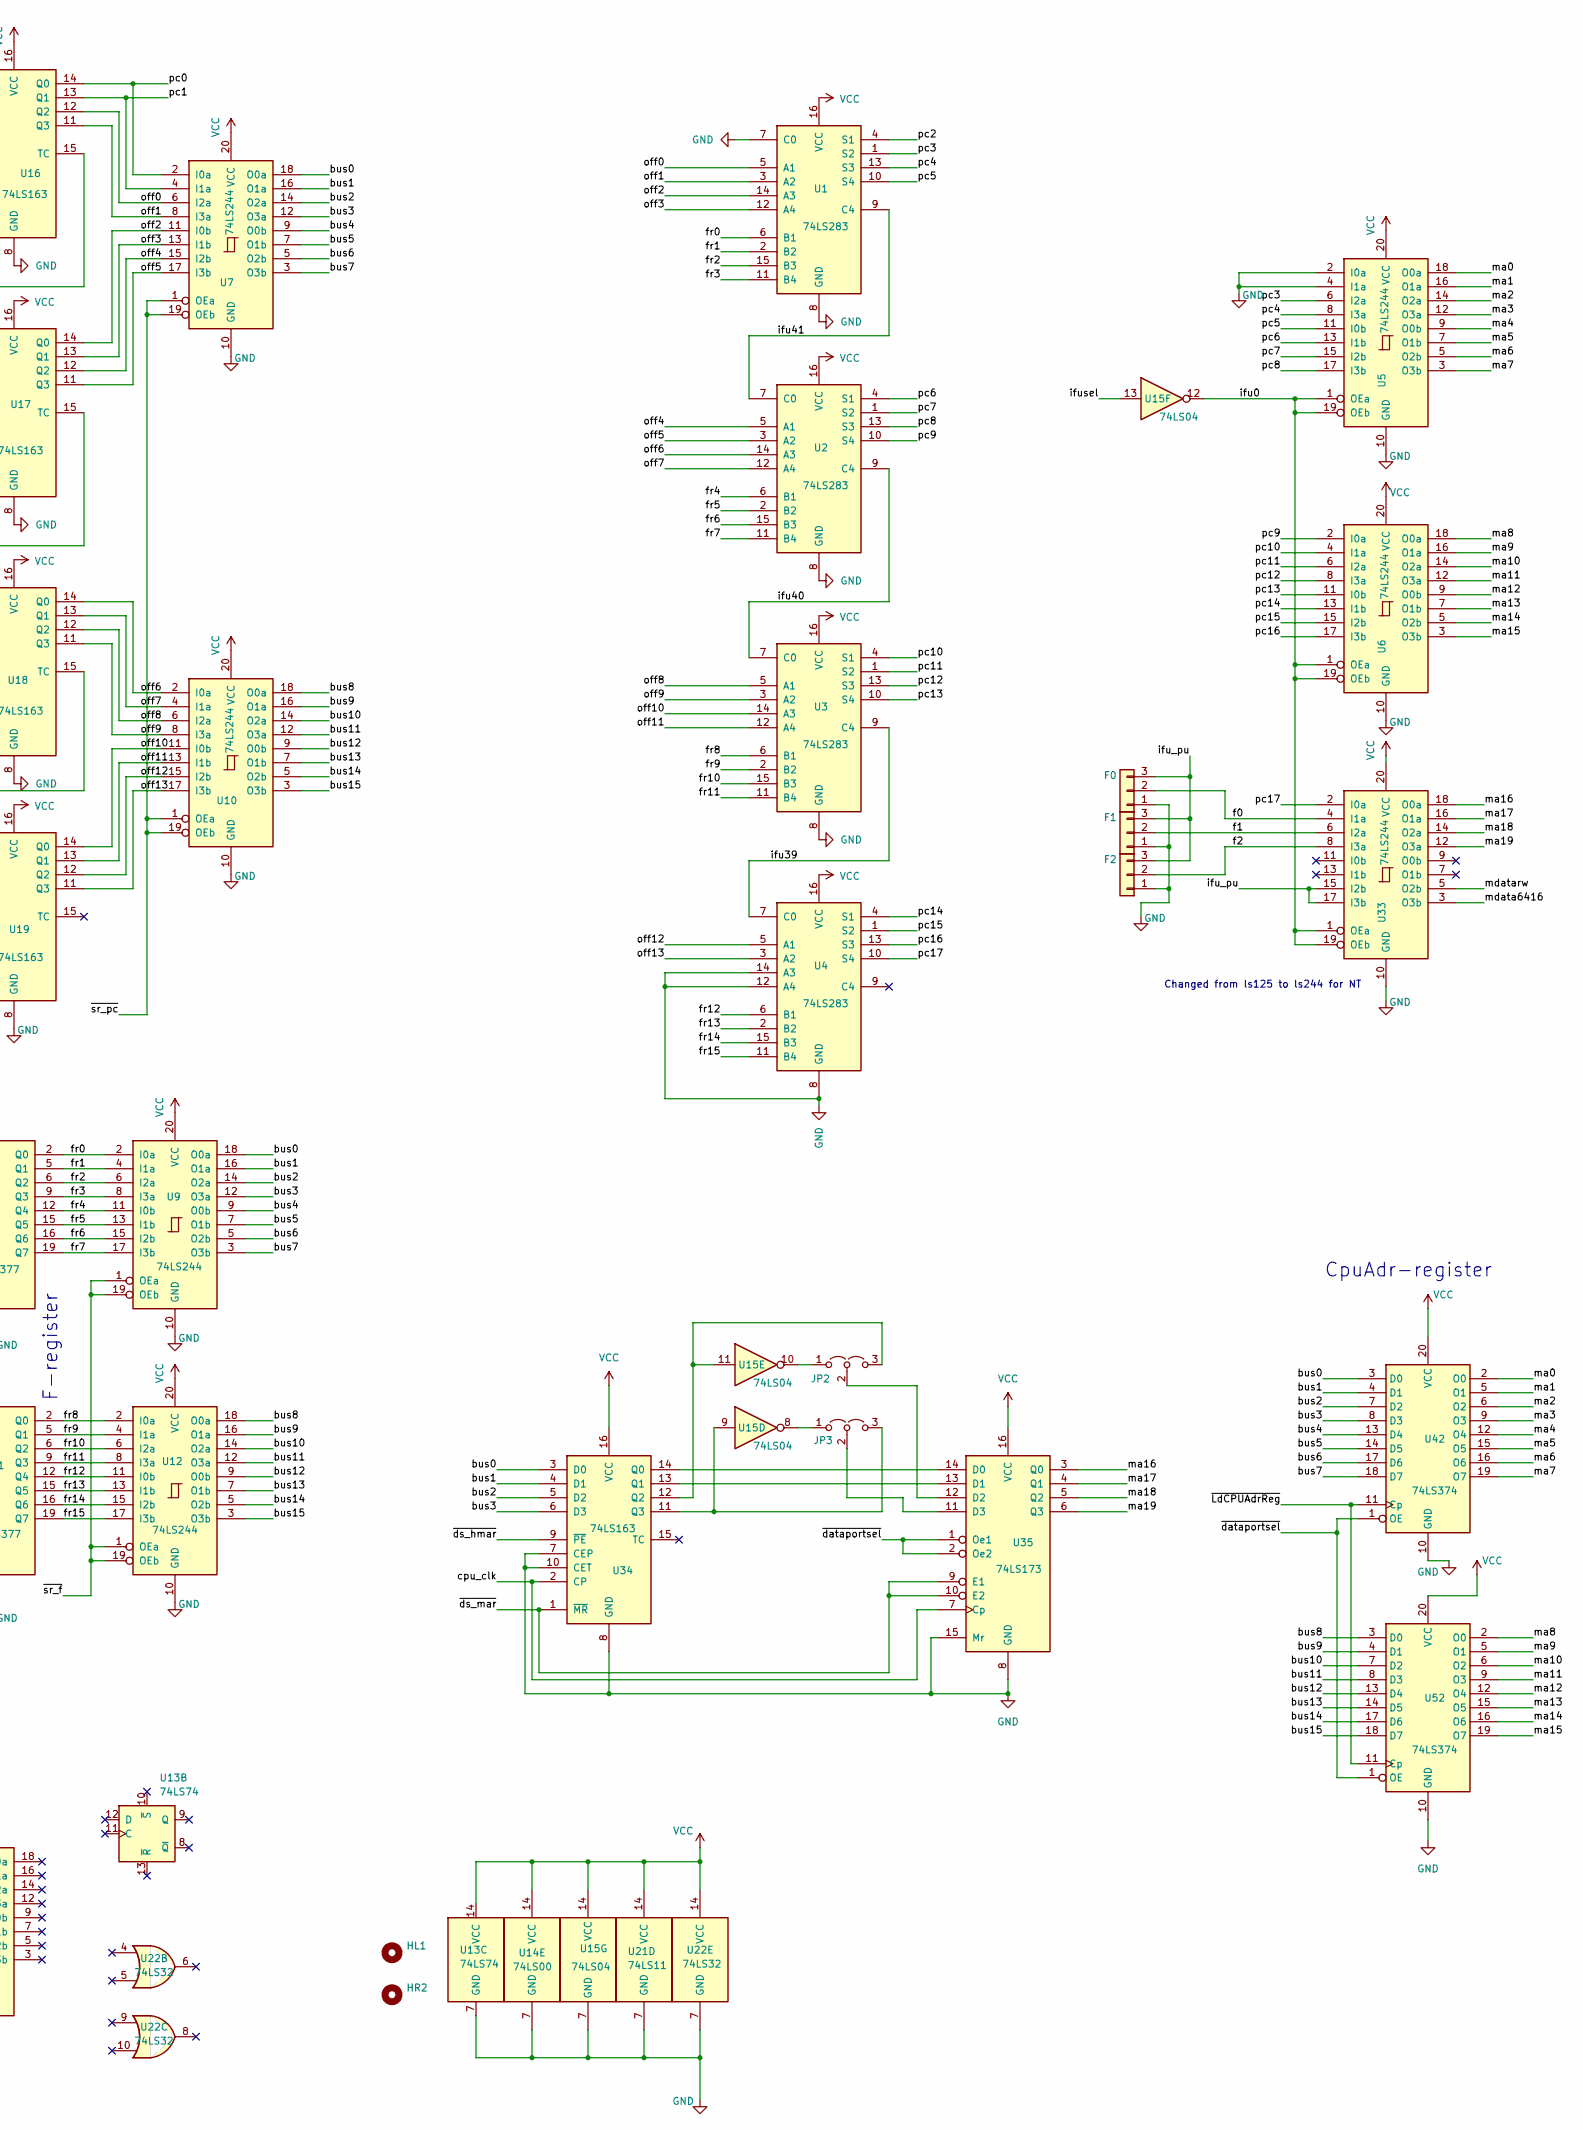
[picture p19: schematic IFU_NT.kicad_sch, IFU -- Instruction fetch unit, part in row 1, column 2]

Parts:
C1, C2, C3, C4, C5, C6, C7, C8, C9, C10, C11, C12, C13, C14, C15, C16, C17, C18, C19, C20, C21, C22, C23, C24, C25: 100n; C_1206_3216Metric_Pad1.33x1.80mm_HandSolder
Cp1, Cp2, Cp3, Cp4, Cp5, Cp6: 68U; CP_PHP
F0, F1, F2: Conn_01x03; PinHeader_1x03_P2.54mm_Vertical
HL1: MountingHole; Handle
HR2: MountingHole; Handle
IFU1: lilith_nt_edge; Lilith_edge
JP1: Jumper_3_Open; PinSocket_1x03_P2.54mm_Vertical
JP2, JP3: Jumper_3_Open; PinHeader_1x03_P2.00mm_Vertical
R1: 560; R_Axial_DIN0207_L6.3mm_D2.5mm_P10.16mm_Horizontal
SPR1, SPR2: Spare; DIP-20_W7.62mm
SR1: 2716; DIP-24_W15.24mm_Socket
U1, U2, U3, U4: 74LS283; DIP-16_W7.62mm
U5, U6, U7, U9, U10, U12, U33: 74LS244; DIP-20_W7.62mm
U8, U11: 74LS377; DIP-20_W7.62mm
U13: 74LS74; DIP-14_W7.62mm
U14: 74LS00; DIP-14_W7.62mm
U15: 74LS04; DIP-14_W7.62mm
U16, U17, U18, U19, U34: 74LS163; DIP-16_W7.62mm
U20: 74LS138; DIP-16_W7.62mm
U21: 74LS11; DIP-14_W7.62mm
U22: 74LS32; DIP-14_W7.62mm
U24, U26, U27, U28, U29, U30, U31, U32, U42, U52: 74LS374; DIP-20_W7.62mm
U25: 74S244; DIP-20_W7.62mm
U35: 74LS173; DIP-16_W7.62mm

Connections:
+12V: IFU1.AD2, IFU1.BD2, IFU1.CD2, IFU1.DD2
-12V: IFU1.AB2, IFU1.BB2, IFU1.CB2, IFU1.DB2
/bus0: IFU1.AK1, U7.18 (O0a), U8.3 (D0), U9.18 (O0a), U16.3 (D0), U25.18 (O0a), U34.3 (D0), U42.3 (D0)
/bus1: IFU1.AK2, U7.16 (O1a), U8.4 (D1), U9.16 (O1a), U16.4 (D1), U25.16 (O1a), U34.4 (D1), U42.4 (D1)
/bus2: IFU1.AL1, U7.14 (O2a), U8.7 (D2), U9.14 (O2a), U16.5 (D2), U25.14 (O2a), U34.5 (D2), U42.7 (D2)
/bus3: IFU1.AL2, U7.12 (O3a), U8.8 (D3), U9.12 (O3a), U16.6 (D3), U25.12 (O3a), U34.6 (D3), U42.8 (D3)
/bus4: IFU1.AN1, U7.9 (O0b), U8.13 (D4), U9.9 (O0b), U17.3 (D0), U25.9 (O0b), U42.13 (D4)
/bus5: IFU1.AN2, U7.7 (O1b), U8.14 (D5), U9.7 (O1b), U17.4 (D1), U25.7 (O1b), U42.14 (D5)
/bus6: IFU1.AP1, U7.5 (O2b), U8.17 (D6), U9.5 (O2b), U17.5 (D2), U25.5 (O2b), U42.17 (D6)
/bus7: IFU1.AP2, U7.3 (O3b), U8.18 (D7), U9.3 (O3b), U17.6 (D3), U25.3 (O3b), U42.18 (D7)
/bus8: IFU1.AR1, U10.18 (O0a), U11.3 (D0), U12.18 (O0a), U18.3 (D0), U52.3 (D0)
/bus9: IFU1.AR2, U10.16 (O1a), U11.4 (D1), U12.16 (O1a), U18.4 (D1), U52.4 (D1)
/bus10: IFU1.AS1, U10.14 (O2a), U11.7 (D2), U12.14 (O2a), U18.5 (D2), U52.7 (D2)
/bus11: IFU1.AS2, U10.12 (O3a), U11.8 (D3), U12.12 (O3a), U18.6 (D3), U52.8 (D3)
/bus12: IFU1.AU1, U10.9 (O0b), U11.13 (D4), U12.9 (O0b), U19.3 (D0), U52.13 (D4)
/bus13: IFU1.AU2, U10.7 (O1b), U11.14 (D5), U12.7 (O1b), U19.4 (D1), U52.14 (D5)
/bus14: IFU1.AV1, U10.5 (O2b), U11.17 (D6), U12.5 (O2b), U19.5 (D2), U52.17 (D6)
/bus15: IFU1.AV2, U10.3 (O3b), U11.18 (D7), U12.3 (O3b), U19.6 (D3), U52.18 (D7)
/clrreq: IFU1.BM2, U14.10
/cpu_clk: IFU1.BT2, U8.11 (CP), U11.11 (CP), U16.2 (CP), U17.2 (CP), U18.2 (CP), U19.2 (CP), U22.2, U34.2 (CP), U35.7 (Cp)
/datastrobe: IFU1.AT2, U14.1
/f0: F0.2, U33.4 (I1a); also elsewhere on the board
/f1: F1.2, U33.6 (I2a); also elsewhere on the board
/f2: F2.2, U33.8 (I3a); also elsewhere on the board
/fr0: U1.6 (B1), U8.2 (Q0), U9.2 (I0a)
/fr1: U1.2 (B2), U8.5 (Q1), U9.4 (I1a)
/fr2: U1.15 (B3), U8.6 (Q2), U9.6 (I2a)
/fr3: U1.11 (B4), U8.9 (Q3), U9.8 (I3a)
/fr4: U2.6 (B1), U8.12 (Q4), U9.11 (I0b)
/fr5: U2.2 (B2), U8.15 (Q5), U9.13 (I1b)
/fr6: U2.15 (B3), U8.16 (Q6), U9.15 (I2b)
/fr7: U2.11 (B4), U8.19 (Q7), U9.17 (I3b)
/fr8: U3.6 (B1), U11.2 (Q0), U12.2 (I0a)
/fr9: U3.2 (B2), U11.5 (Q1), U12.4 (I1a)
/fr10: U3.15 (B3), U11.6 (Q2), U12.6 (I2a)
/fr11: U3.11 (B4), U11.9 (Q3), U12.8 (I3a)
/fr12: U4.6 (B1), U11.12 (Q4), U12.11 (I0b)
/fr13: U4.2 (B2), U11.15 (Q5), U12.13 (I1b)
/fr14: U4.15 (B3), U11.16 (Q6), U12.15 (I2b)
/fr15: U4.11 (B4), U11.19 (Q7), U12.17 (I3b)
/ifu0: U5.1 (OEa), U5.19 (OEb), U6.1 (OEa), U6.19 (OEb), U15.12, U33.1 (OEa), U33.19 (OEb)
/ifu1: U21.5, U21.8, U22.12
/ifu2: U21.2, U22.11
/ifu3: U21.12, U22.1
/ifu5: U13.4 (~S), U14.5, U22.3
/ifu6: U13.5 (Q), U14.4
/ifu7: U13.6 (~Q), U14.12
/ifu8: U13.1 (~R), U14.8, U14.13
/ifu9: U14.11, U15.1
/ifu39: U3.9 (C4), U4.7 (C0)
/ifu40: U2.9 (C4), U3.7 (C0)
/ifu41: U1.9 (C4), U2.7 (C0)
/ifu43: SR1.9 (D0), U24.19 (O7), U25.2 (I0a), U26.19 (O7), U27.19 (O7), U28.19 (O7), U29.19 (O7), U30.19 (O7), U31.19 (O7), U32.19 (O7)
/ifu44: SR1.10 (D1), U24.16 (O6), U25.4 (I1a), U26.16 (O6), U27.16 (O6), U28.16 (O6), U29.16 (O6), U30.16 (O6), U31.16 (O6), U32.16 (O6)
/ifu45: SR1.11 (D2), U24.15 (O5), U25.6 (I2a), U26.15 (O5), U27.15 (O5), U28.15 (O5), U29.15 (O5), U30.15 (O5), U31.15 (O5), U32.15 (O5)
/ifu46: SR1.13 (D3), U24.12 (O4), U25.8 (I3a), U26.12 (O4), U27.12 (O4), U28.12 (O4), U29.12 (O4), U30.12 (O4), U31.12 (O4), U32.12 (O4)
/ifu47: SR1.14 (D4), U24.9 (O3), U25.11 (I0b), U26.9 (O3), U27.9 (O3), U28.9 (O3), U29.9 (O3), U30.9 (O3), U31.9 (O3), U32.9 (O3)
/ifu48: SR1.15 (D5), U24.6 (O2), U25.13 (I1b), U26.6 (O2), U27.6 (O2), U28.6 (O2), U29.6 (O2), U30.6 (O2), U31.6 (O2), U32.6 (O2)
/ifu49: SR1.16 (D6), U24.5 (O1), U25.15 (I2b), U26.5 (O1), U27.5 (O1), U28.5 (O1), U29.5 (O1), U30.5 (O1), U31.5 (O1), U32.5 (O1)
/ifu50: SR1.17 (D7), U24.2 (O0), U25.17 (I3b), U26.2 (O0), U27.2 (O0), U28.2 (O0), U29.2 (O0), U30.2 (O0), U31.2 (O0), U32.2 (O0)
/ifu_pu: F0.3, F1.3, F2.3, R1.2, U16.1 (~MR), U17.1 (~MR), U18.1 (~MR), U19.1 (~MR), U20.6 (E3), U33.15 (I2b), U33.17 (I3b); also elsewhere on the board
/ifurdy: IFU1.DJ2, U15.2
/ifusel: IFU1.BF2, U14.2, U14.9, U15.13
/inc_pc: U15.6, U16.7 (CEP), U16.10 (CET)
/ma0: IFU1.DK1, U5.18 (O0a), U42.2 (O0)
/ma1: IFU1.DK2, U5.16 (O1a), U42.5 (O1)
/ma2: IFU1.DL1, U5.14 (O2a), U42.6 (O2)
/ma3: IFU1.DL2, U5.12 (O3a), U42.9 (O3)
/ma4: IFU1.DN1, U5.9 (O0b), U42.12 (O4)
/ma5: IFU1.DN2, U5.7 (O1b), U42.15 (O5)
/ma6: IFU1.DP1, U5.5 (O2b), U42.16 (O6)
/ma7: IFU1.DP2, U5.3 (O3b), U42.19 (O7)
/ma8: IFU1.DR1, U6.18 (O0a), U52.2 (O0)
/ma9: IFU1.DR2, U6.16 (O1a), U52.5 (O1)
/ma10: IFU1.DS1, U6.14 (O2a), U52.6 (O2)
/ma11: IFU1.DS2, U6.12 (O3a), U52.9 (O3)
/ma12: IFU1.DU1, U6.9 (O0b), U52.12 (O4)
/ma13: IFU1.DU2, U6.7 (O1b), U52.15 (O5)
/ma14: IFU1.DV1, U6.5 (O2b), U52.16 (O6)
/ma15: IFU1.DV2, U6.3 (O3b), U52.19 (O7)
/ma16: IFU1.DT1, U33.18 (O0a), U35.3 (Q0)
/ma17: IFU1.DM1, U33.16 (O1a), U35.4 (Q1)
/ma18: IFU1.DJ1, U33.14 (O2a), U35.5 (Q2)
/ma19: IFU1.CM1, U33.12 (O3a), U35.6 (Q3)
/md0: IFU1.AA1, U24.18 (D7)
/md1: IFU1.AB1, U24.17 (D6)
/md2: IFU1.AC1, U24.14 (D5)
/md3: IFU1.AD1, U24.13 (D4)
/md4: IFU1.AE1, U24.8 (D3)
/md5: IFU1.AF1, U24.7 (D2)
/md6: IFU1.AH1, U24.4 (D1)
/md7: IFU1.AH2, U24.3 (D0)
/md8: IFU1.BA1, U26.18 (D7)
/md9: IFU1.BB1, U26.17 (D6)
/md10: IFU1.BC1, U26.14 (D5)
/md11: IFU1.BD1, U26.13 (D4)
/md12: IFU1.BE1, U26.8 (D3)
/md13: IFU1.BF1, U26.7 (D2)
/md14: IFU1.BH1, U26.4 (D1)
/md15: IFU1.BH2, U26.3 (D0)
/md16: IFU1.BK1, U27.18 (D7)
/md17: IFU1.BK2, U27.17 (D6)
/md18: IFU1.BL1, U27.14 (D5)
/md19: IFU1.BL2, U27.13 (D4)
/md20: IFU1.BN1, U27.8 (D3)
/md21: IFU1.BN2, U27.7 (D2)
/md22: IFU1.BP1, U27.4 (D1)
/md23: IFU1.BP2, U27.3 (D0)
/md24: IFU1.BR1, U28.18 (D7)
/md25: IFU1.BR2, U28.17 (D6)
/md26: IFU1.BS1, U28.14 (D5)
/md27: IFU1.BS2, U28.13 (D4)
/md28: IFU1.BU1, U28.8 (D3)
/md29: IFU1.BU2, U28.7 (D2)
/md30: IFU1.BV1, U28.4 (D1)
/md31: IFU1.BV2, U28.3 (D0)
/md32: IFU1.CA1, U29.18 (D7)
/md33: IFU1.CB1, U29.17 (D6)
/md34: IFU1.CC1, U29.14 (D5)
/md35: IFU1.CD1, U29.13 (D4)
/md36: IFU1.CE1, U29.8 (D3)
/md37: IFU1.CF1, U29.7 (D2)
/md38: IFU1.CH1, U29.4 (D1)
/md39: IFU1.CH2, U29.3 (D0)
/md40: IFU1.CK1, U30.18 (D7)
/md41: IFU1.CK2, U30.17 (D6)
/md42: IFU1.CL1, U30.14 (D5)
/md43: IFU1.CL2, U30.13 (D4)
/md44: IFU1.CN1, U30.8 (D3)
/md45: IFU1.CN2, U30.7 (D2)
/md46: IFU1.CP1, U30.4 (D1)
/md47: IFU1.CP2, U30.3 (D0)
/md48: IFU1.CR1, U31.18 (D7)
/md49: IFU1.CR2, U31.17 (D6)
/md50: IFU1.CS1, U31.14 (D5)
/md51: IFU1.CS2, U31.13 (D4)
/md52: IFU1.CU1, U31.8 (D3)
/md53: IFU1.CU2, U31.7 (D2)
/md54: IFU1.CV1, U31.4 (D1)
/md55: IFU1.CV2, U31.3 (D0)
/md56: IFU1.DA1, U32.18 (D7)
/md57: IFU1.DB1, U32.17 (D6)
/md58: IFU1.DC1, U32.14 (D5)
/md59: IFU1.DD1, U32.13 (D4)
/md60: IFU1.DE1, U32.8 (D3)
/md61: IFU1.DF1, U32.7 (D2)
/md62: IFU1.DH1, U32.4 (D1)
/md63: IFU1.DH2, U32.3 (D0)
/mdata6416: IFU1.DE2, U33.3 (O3b)
/mdatarw: IFU1.DF2, U33.5 (O2b)
/off0: SR1.6 (A2), U1.5 (A1), U7.6 (I2a), U16.12 (Q2)
/off1: SR1.5 (A3), U1.3 (A2), U7.8 (I3a), U16.11 (Q3)
/off2: SR1.4 (A4), U1.14 (A3), U7.11 (I0b), U17.14 (Q0)
/off3: SR1.3 (A5), U1.12 (A4), U7.13 (I1b), U17.13 (Q1)
/off4: SR1.2 (A6), U2.5 (A1), U7.15 (I2b), U17.12 (Q2)
/off5: SR1.1 (A7), U2.3 (A2), U7.17 (I3b), U17.11 (Q3)
/off6: SR1.23 (A8), U2.14 (A3), U10.2 (I0a), U18.14 (Q0)
/off7: SR1.22 (A9), U2.12 (A4), U10.4 (I1a), U18.13 (Q1)
/off8: SR1.19 (A10), U3.5 (A1), U10.6 (I2a), U18.12 (Q2)
/off9: U3.3 (A2), U10.8 (I3a), U18.11 (Q3)
/off10: U3.14 (A3), U10.11 (I0b), U19.14 (Q0)
/off11: U3.12 (A4), U10.13 (I1b), U19.13 (Q1)
/off12: U4.5 (A1), U10.15 (I2b), U19.12 (Q2)
/off13: JP1.3 (B), U4.3 (A2), U10.17 (I3b), U19.11 (Q3)
/pc0: SR1.8 (A0), U7.2 (I0a), U16.14 (Q0), U20.1 (A0)
/pc1: SR1.7 (A1), U7.4 (I1a), U16.13 (Q1), U20.2 (A1)
/pc2: U1.4 (S1), U20.3 (A2)
/pc3: U1.1 (S2), U5.6 (I2a)
/pc4: U1.13 (S3), U5.8 (I3a)
/pc5: U1.10 (S4), U5.11 (I0b)
/pc6: U2.4 (S1), U5.13 (I1b)
/pc7: U2.1 (S2), U5.15 (I2b)
/pc8: U2.13 (S3), U5.17 (I3b)
/pc9: U2.10 (S4), U6.2 (I0a)
/pc10: U3.4 (S1), U6.4 (I1a)
/pc11: U3.1 (S2), U6.6 (I2a)
/pc12: U3.13 (S3), U6.8 (I3a)
/pc13: U3.10 (S4), U6.11 (I0b)
/pc14: U4.4 (S1), U6.13 (I1b)
/pc15: U4.1 (S2), U6.15 (I2b)
/pc16: U4.13 (S3), U6.17 (I3b)
/pc17: U4.10 (S4), U33.2 (I0a)
/~LdCPUAdrReg: IFU1.CT1, U42.11 (Cp), U52.11 (Cp)
/~dataportsel: IFU1.CJ1, U35.1 (Oe1), U35.2 (Oe2), U42.1 (OE), U52.1 (OE)
/~ds_f: IFU1.AM2, U8.1 (~E), U11.1 (~E)
/~ds_hmar: IFU1.BT1, U34.9 (~PE)
/~ds_mar: IFU1.BM1, U34.1 (~MR), U35.9 (E1), U35.10 (E2)
/~ds_pc: IFU1.AF2, U16.9 (~PE), U17.9 (~PE), U18.9 (~PE), U19.9 (~PE), U21.1, U21.13
/~gt_ifu_d: U15.5, U21.6, U25.1 (OEa), U25.19 (OEb)
/~ifureq: IFU1.BE2, U14.6
/~mapenabl: IFU1.CM2, U21.9
/~reset: IFU1.BJ2
/~sel0: U20.15 (O0), U26.1 (OE)
/~sel1: U20.14 (O1), U24.1 (OE)
/~sel2: U20.13 (O2), U28.1 (OE)
/~sel3: U20.12 (O3), U27.1 (OE)
/~sel4: U20.11 (O4), U30.1 (OE)
/~sel5: U20.10 (O5), U29.1 (OE)
/~sel6: U20.9 (O6), U32.1 (OE)
/~sel7: U20.7 (O7), U22.13, U31.1 (OE)
/~sr_f: IFU1.AJ2, U9.1 (OEa), U9.19 (OEb), U12.1 (OEa), U12.19 (OEb)
/~sr_ir8*: IFU1.CJ2, U21.3, U21.4
/~sr_ir8+: IFU1.CE2, U21.11
/~sr_ir8-: IFU1.CF2, U21.10
/~sr_pc: IFU1.AE2, U7.1 (OEa), U7.19 (OEb), U10.1 (OEa), U10.19 (OEb)
/~wr_ifu_d: U14.3, U24.11 (Cp), U26.11 (Cp), U27.11 (Cp), U28.11 (Cp), U29.11 (Cp), U30.11 (Cp), U31.11 (Cp), U32.11 (Cp)
GND: C1.2, C2.2, C3.2, C4.2, C5.2, C6.2, C7.2, C8.2, C9.2, C10.2, C11.2, C12.2, C13.2, C14.2, C15.2, C16.2, C17.2, C18.2, C19.2, C20.2, C21.2, C22.2, C23.2, C24.2, C25.2, Cp1.2, Cp2.2, Cp3.2, Cp4.2, Cp5.2, Cp6.2, F0.1, F1.1, F2.1, IFU1.AC2, IFU1.AJ1, IFU1.AM1, IFU1.AT1, IFU1.BC2, IFU1.BJ1, IFU1.CC2, IFU1.DC2, IFU1.G1 (GND), IFU1.G2 (GND), IFU1.G3 (GND), IFU1.G4 (GND), IFU1.G5 (GND), IFU1.G6 (GND), IFU1.G7 (GND), IFU1.G8 (GND), IFU1.G10, IFU1.G11, IFU1.G12, IFU1.G13, IFU1.G14, IFU1.G15, IFU1.G16, IFU1.G17, IFU1.G18, IFU1.G19, IFU1.G20, IFU1.G21, IFU1.G22, IFU1.G23, IFU1.G24, IFU1.G25, JP1.1 (A), SPR1.10 (GND), SPR2.10 (GND), SR1.12 (GND), SR1.18 (~CS), U1.7 (C0), U1.8 (GND), U2.8 (GND), U3.8 (GND), U4.8 (GND), U4.12 (A4), U4.14 (A3), U5.2 (I0a), U5.4 (I1a), U5.10 (GND), U6.10 (GND), U7.10 (GND), U8.10 (GND), U9.10 (GND), U10.10 (GND), U11.10 (GND), U12.10 (GND), U13.2 (D), U13.3 (C), U13.7 (GND), U14.7 (GND), U15.7 (GND), U16.8 (GND), U17.8 (GND), U18.8 (GND), U19.8 (GND), U20.4 (E1), U20.8 (GND), U21.7 (GND), U22.7 (GND), U24.10 (GND), U25.10 (GND), U26.10 (GND), U27.10 (GND), U28.10 (GND), U29.10 (GND), U30.10 (GND), U31.10 (GND), U32.10 (GND), U33.10 (GND), U34.7 (CEP), U34.8 (GND), U34.10 (CET), U35.8 (GND), U35.15 (Mr), U42.10 (GND), U52.10 (GND); also elsewhere on the board
unnamed: JP1.2 (C), U15.3, U20.5 (E2)
unnamed: JP2.1 (A), U15.10
unnamed: JP2.3 (B), U15.11, U34.12 (Q2)
unnamed: JP2.2 (C), U35.12 (D2)
unnamed: JP3.1 (A), U15.8
unnamed: JP3.3 (B), U15.9, U34.11 (Q3)
unnamed: JP3.2 (C), U35.11 (D3)
unnamed: SR1.20 (~OE), U15.4
unnamed: U16.15 (TC), U17.7 (CEP), U17.10 (CET)
unnamed: U17.15 (TC), U18.7 (CEP), U18.10 (CET)
unnamed: U18.15 (TC), U19.7 (CEP), U19.10 (CET)
unnamed: U34.14 (Q0), U35.14 (D0)
unnamed: U34.13 (Q1), U35.13 (D1)
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

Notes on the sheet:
Changed from ls125 to ls244 for NT
V1 IFU / V2 IFU
F-register
CpuAdr-register

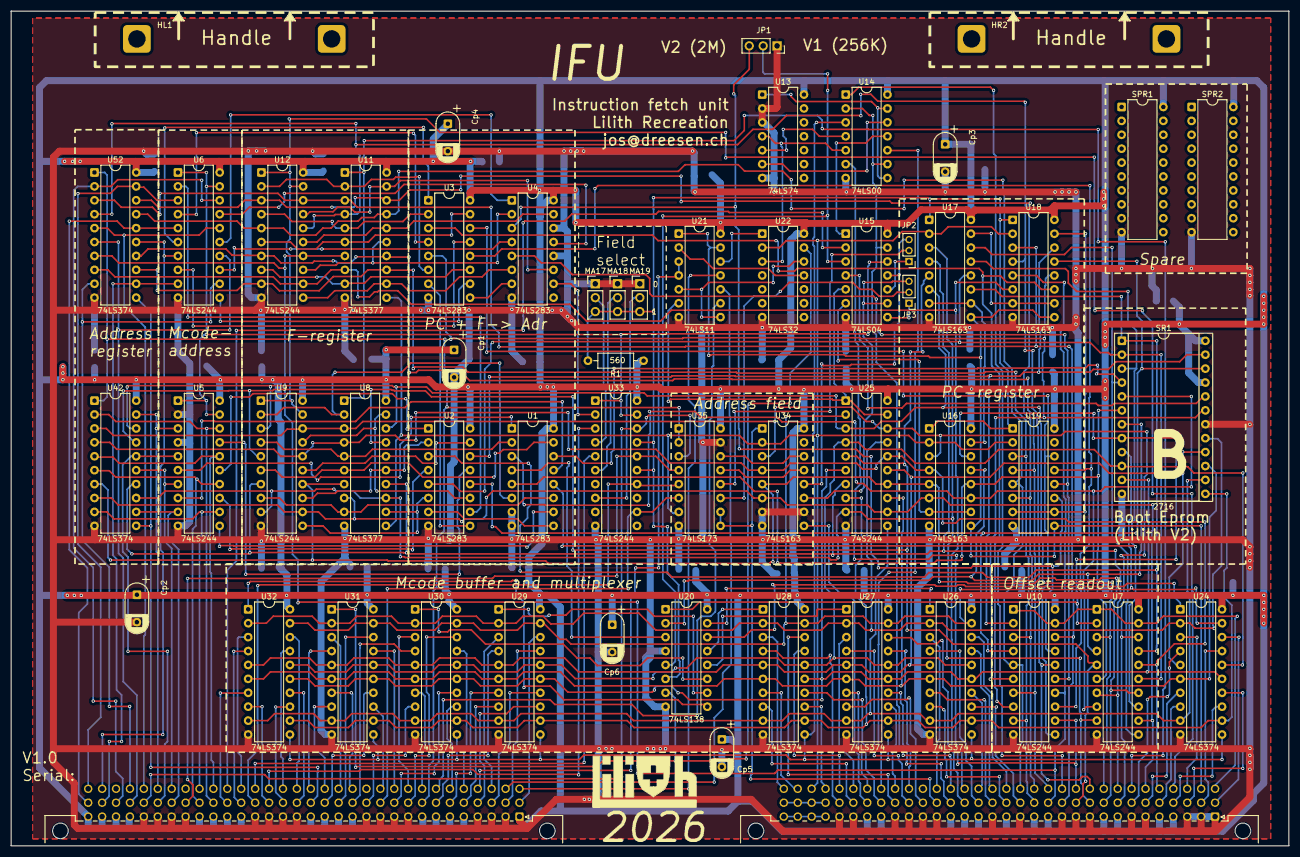
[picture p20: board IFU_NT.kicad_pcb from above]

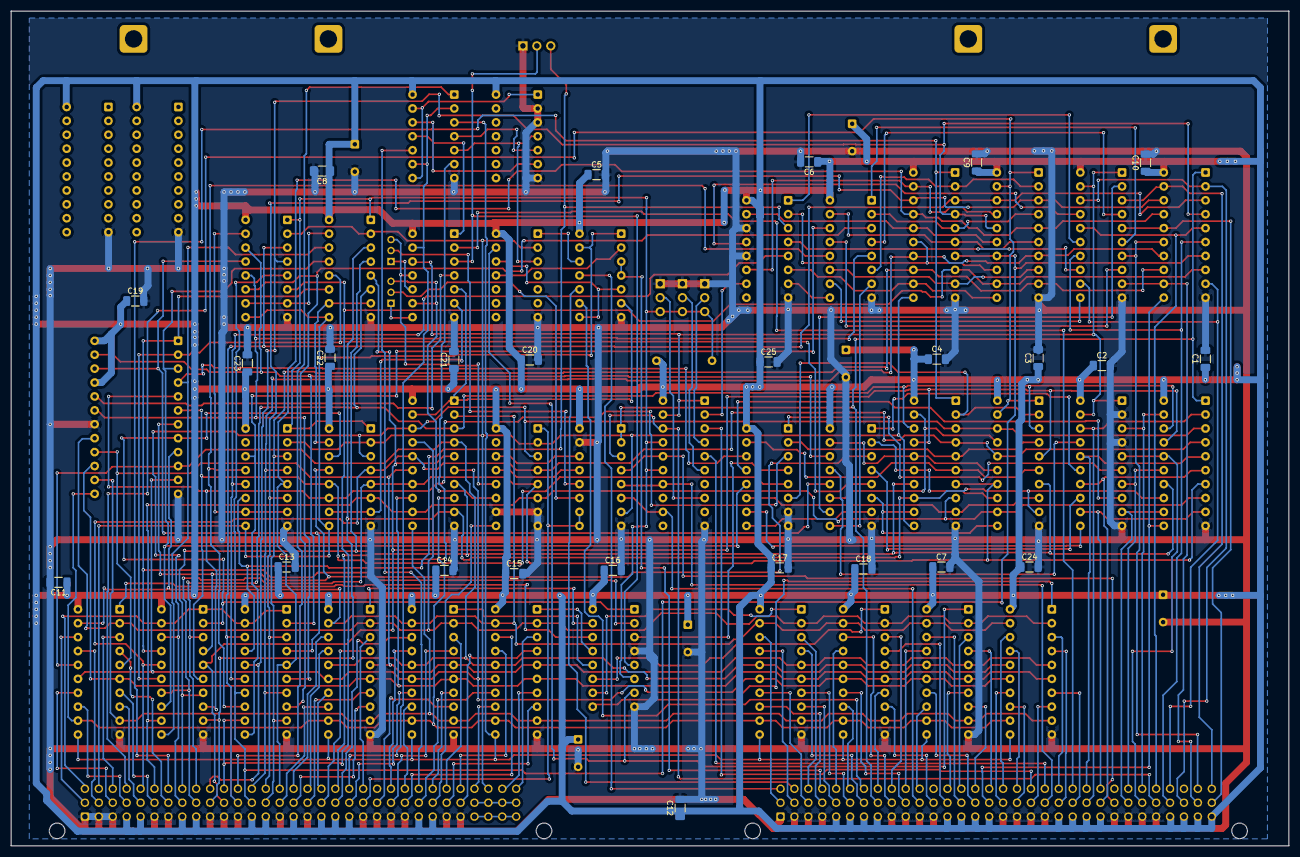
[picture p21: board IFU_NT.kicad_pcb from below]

Board: 2 copper layers, 233.3 x 152.4 mm, 80 parts (25 on the bottom side), 220 nets.

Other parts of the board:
MA17, MA18, MA19: Conn_01x03; PinHeader_1x03_P2.54mm_Vertical

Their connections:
/f0: MA17.2; also elsewhere on the board
/f1: MA18.2; also elsewhere on the board
/f2: MA19.2; also elsewhere on the board
/ifu_pu: MA17.3, MA18.3, MA19.3; also elsewhere on the board
GND: MA17.1, MA18.1, MA19.1; also elsewhere on the board

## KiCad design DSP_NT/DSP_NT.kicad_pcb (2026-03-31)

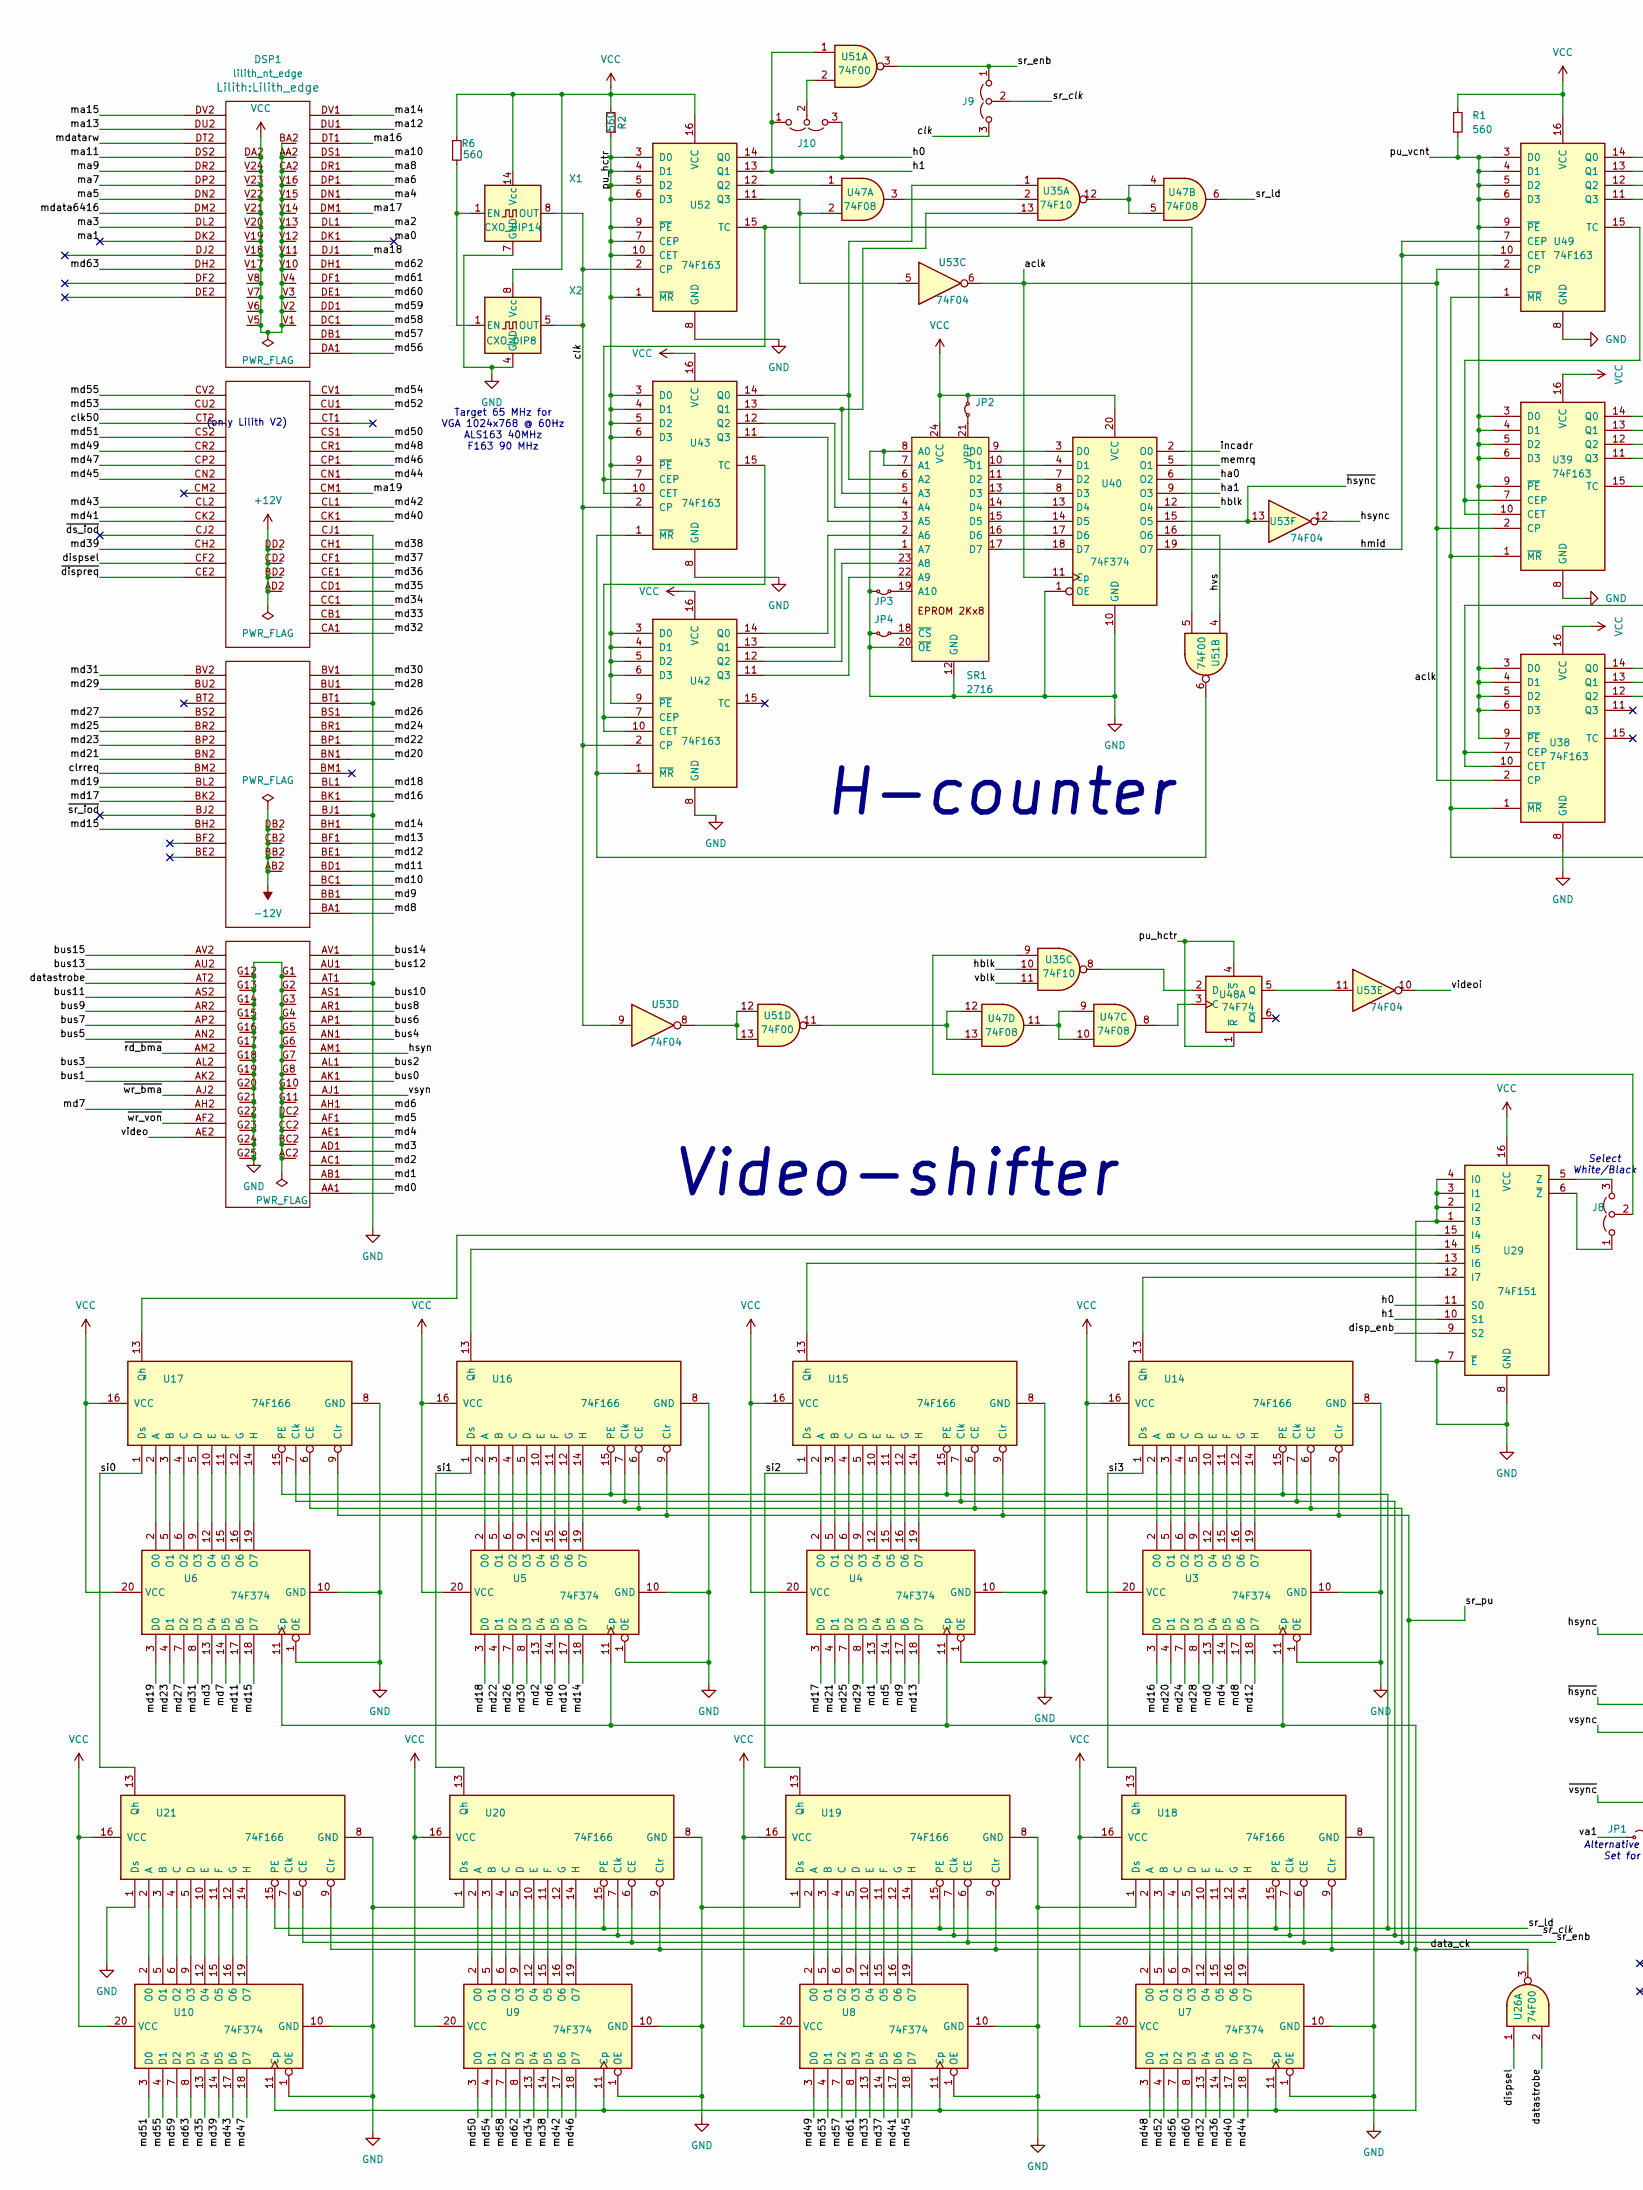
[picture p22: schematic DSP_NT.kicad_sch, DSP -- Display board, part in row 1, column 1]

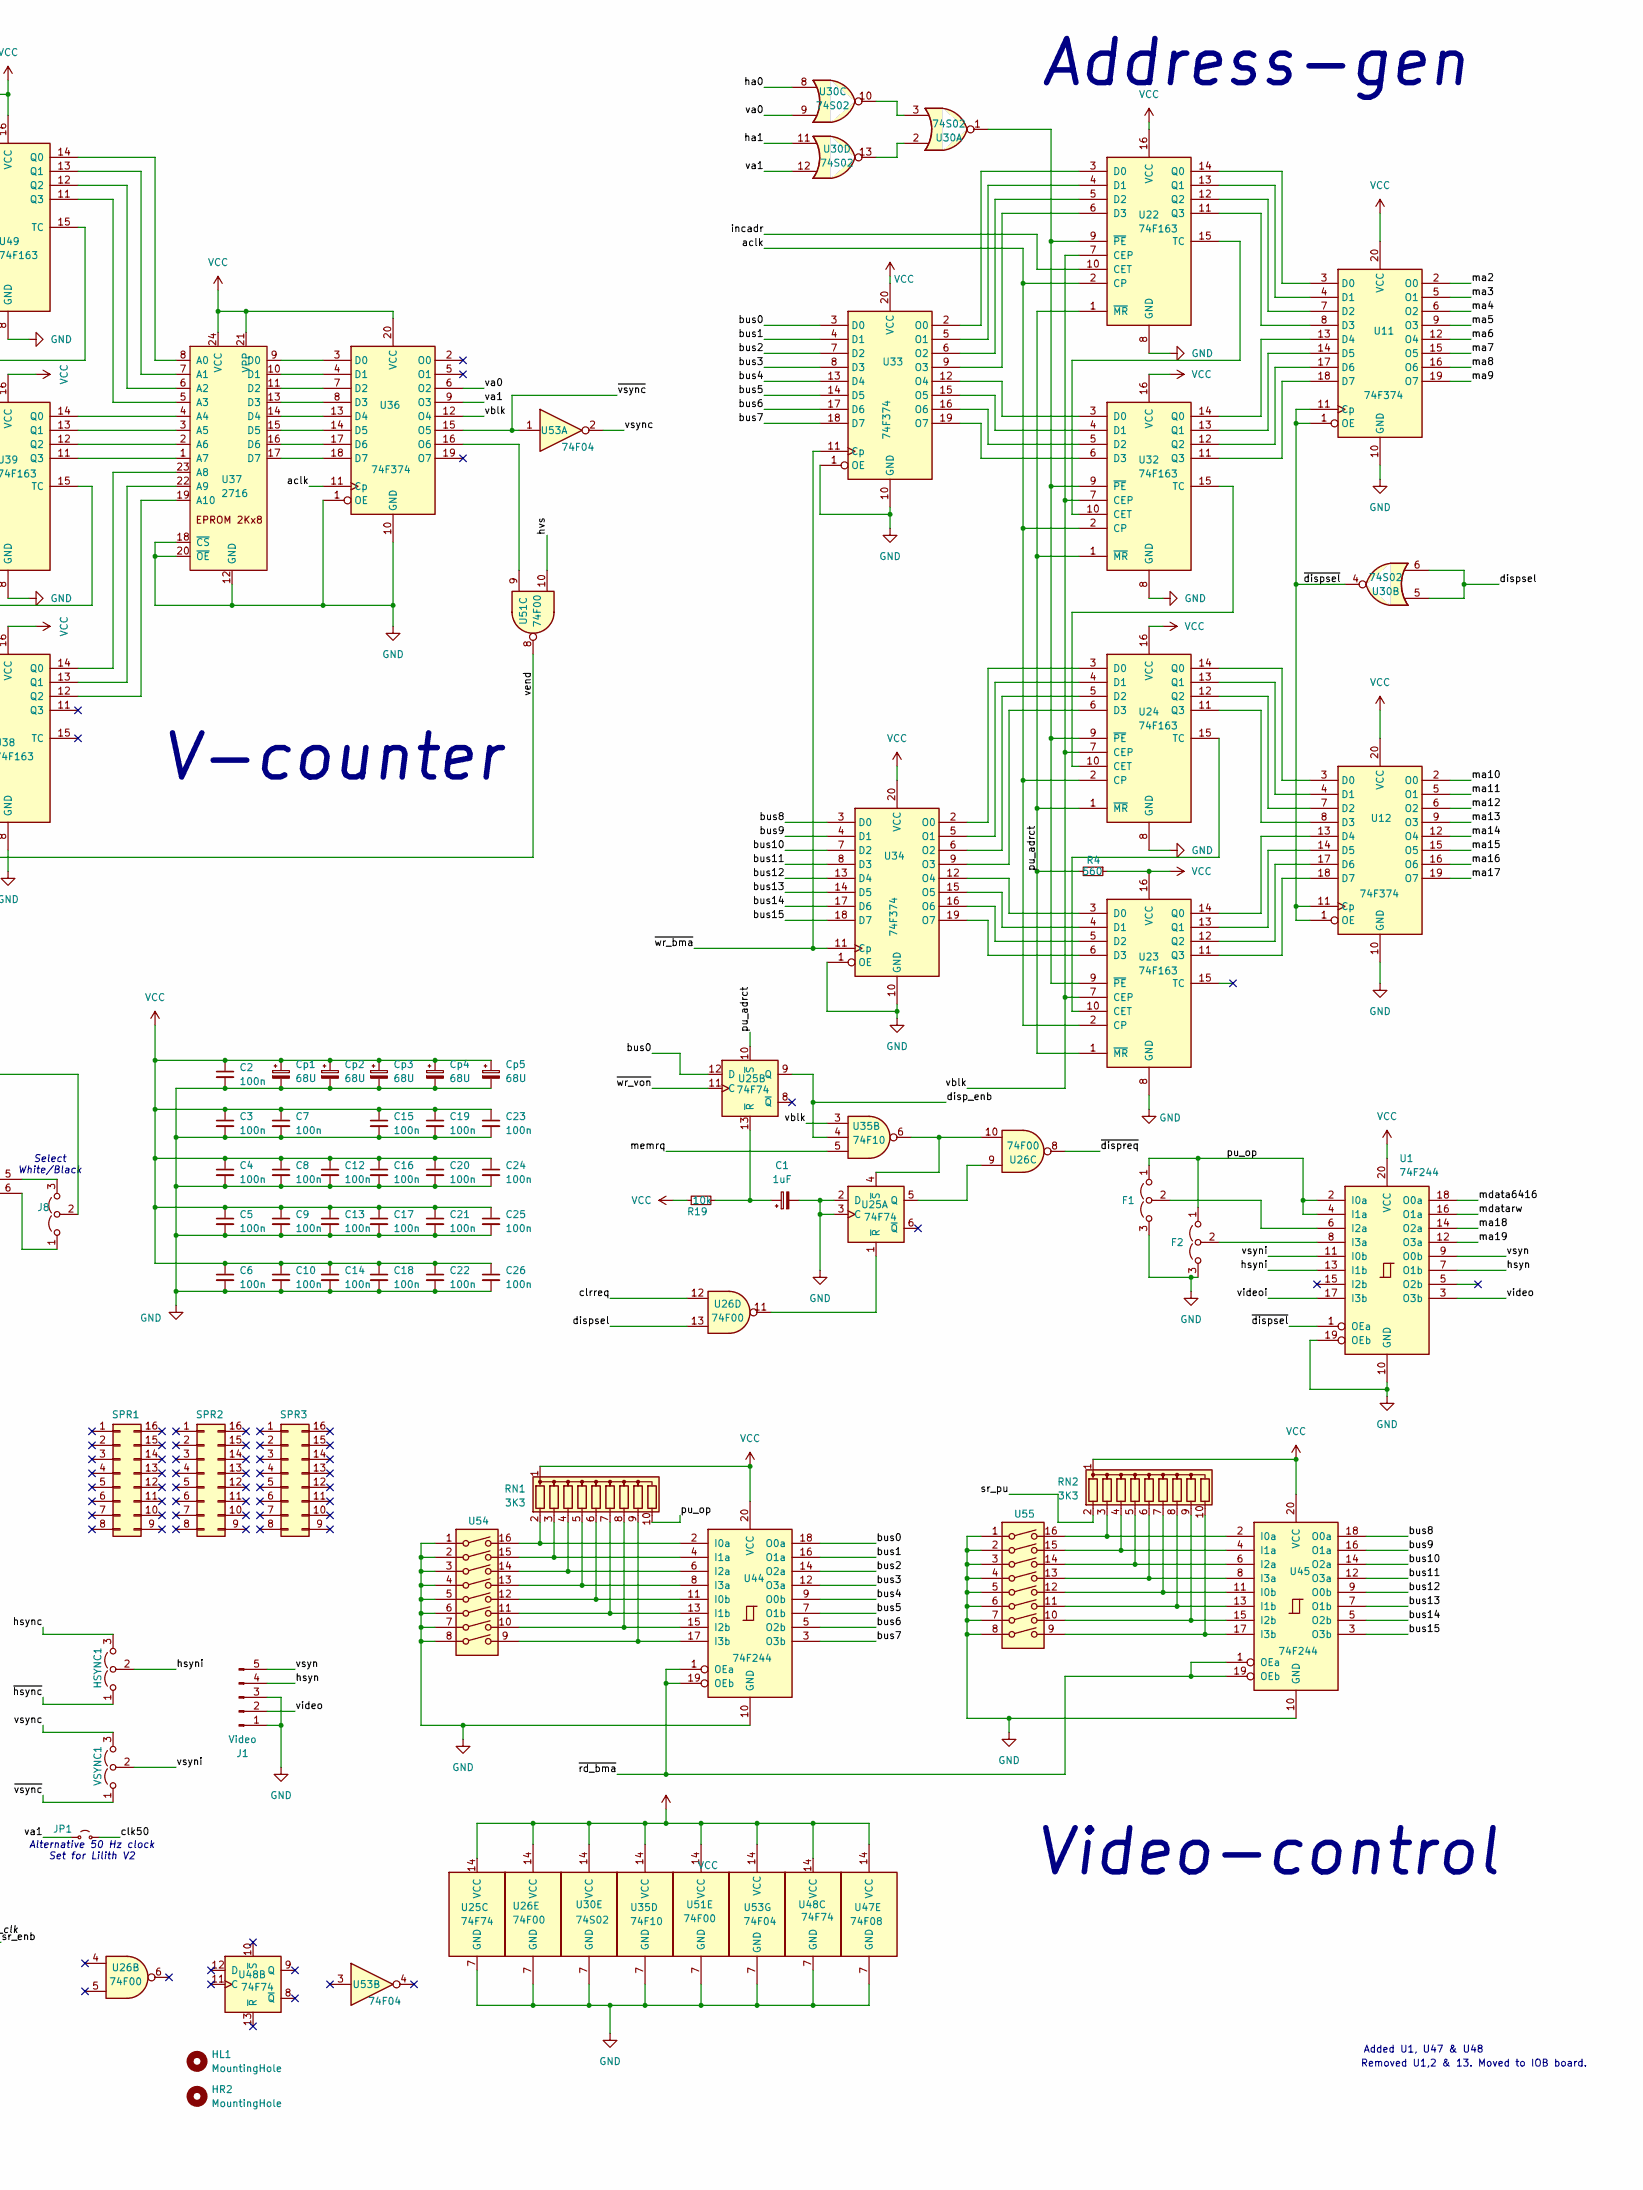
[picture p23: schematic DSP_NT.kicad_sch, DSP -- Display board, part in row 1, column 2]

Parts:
C1: 1uF; CP_Radial_D4.0mm_P2.00mm
C2, C3, C4, C5, C6, C7, C8, C9, C10, C12, C13, C14, C15, C16, C17, C18, C19, C20, C21, C22, C23, C24, C25, C26: 100n; C_1206_3216Metric_Pad1.33x1.80mm_HandSolder
Cp1, Cp2, Cp3, Cp4, Cp5: 68U; CP_PHP
DSP1: lilith_nt_edge; Lilith_edge
F1, F2: Jumper_3_Open; PinHeader_1x03_P2.54mm_Vertical
HL1: MountingHole; Handle
HR2: MountingHole; Handle
HSYNC1: Jumper_3_Open; PinHeader_1x03_P2.54mm_Vertical
J1: Video; PinSocket_1x05_P2.54mm_Vertical
J8: Jumper_3_Open; SW_Push_1P2T_Vertical_E-Switch_800UDP8P1A1M6
J9, J10: Jumper_3_Open; PinHeader_1x03_P2.54mm_Vertical
JP1: Jumper_2_Small_Open; PinHeader_1x02_P2.54mm_Vertical
JP2, JP3, JP4: Jumper_2_Small_Bridged; SolderJumper-2_P1.3mm_Bridged_RoundedPad1.0x1.5mm
R1, R2, R4, R6: 560; R_Axial_DIN0207_L6.3mm_D2.5mm_P10.16mm_Horizontal
R19: 10k; R_Axial_DIN0207_L6.3mm_D2.5mm_P10.16mm_Horizontal
RN1, RN2: 3K3; R_Array_SIP10
SPR1, SPR2, SPR3: Conn_02x08_Counter_Clockwise; DIP-16_W7.62mm
SR1: 2716; DIP-24_W15.24mm_Socket
U1, U44, U45: 74F244; DIP-20_W7.62mm
U3, U4, U5, U6, U7, U8, U9, U10, U11, U12, U33, U34, U36, U40: 74F374; DIP-20_W7.62mm
U14, U15, U16, U17, U18, U19, U20, U21: 74F166; DIP-16_W7.62mm
U22, U23, U24, U32, U38, U39, U42, U43, U49, U52: 74F163; DIP-16_W7.62mm
U25, U48: 74F74; DIP-14_W7.62mm
U26, U51: 74F00; DIP-14_W7.62mm
U29: 74F151; DIP-16_W7.62mm
U30: 74S02; DIP-14_W7.62mm
U35: 74F10; DIP-14_W7.62mm
U37: 2716; DIP-24_W15.24mm_Socket
U47: 74F08; DIP-14_W7.62mm
U53: 74F04; DIP-14_W7.62mm
U54, U55: SW_DIP_x08; DIP-16_W7.62mm
VSYNC1: Jumper_3_Open; PinHeader_1x03_P2.54mm_Vertical
X1: CXO_DIP14; Oscillator_DIP-14
X2: CXO_DIP8; Oscillator_DIP-8

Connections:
+12V: DSP1.AD2, DSP1.BD2, DSP1.CD2, DSP1.DD2
-12V: DSP1.AB2, DSP1.BB2, DSP1.CB2, DSP1.DB2
/aclk: U22.2 (CP), U23.2 (CP), U24.2 (CP), U32.2 (CP), U36.11 (Cp), U38.2 (CP), U39.2 (CP), U40.11 (Cp), U49.2 (CP), U53.6
/bus0: DSP1.AK1, U25.12 (D), U33.3 (D0), U44.18 (O0a)
/bus1: DSP1.AK2, U33.4 (D1), U44.16 (O1a)
/bus2: DSP1.AL1, U33.7 (D2), U44.14 (O2a)
/bus3: DSP1.AL2, U33.8 (D3), U44.12 (O3a)
/bus4: DSP1.AN1, U33.13 (D4), U44.9 (O0b)
/bus5: DSP1.AN2, U33.14 (D5), U44.7 (O1b)
/bus6: DSP1.AP1, U33.17 (D6), U44.5 (O2b)
/bus7: DSP1.AP2, U33.18 (D7), U44.3 (O3b)
/bus8: DSP1.AR1, U34.3 (D0), U45.18 (O0a)
/bus9: DSP1.AR2, U34.4 (D1), U45.16 (O1a)
/bus10: DSP1.AS1, U34.7 (D2), U45.14 (O2a)
/bus11: DSP1.AS2, U34.8 (D3), U45.12 (O3a)
/bus12: DSP1.AU1, U34.13 (D4), U45.9 (O0b)
/bus13: DSP1.AU2, U34.14 (D5), U45.7 (O1b)
/bus14: DSP1.AV1, U34.17 (D6), U45.5 (O2b)
/bus15: DSP1.AV2, U34.18 (D7), U45.3 (O3b)
/clk: J9.3 (B), U42.2 (CP), U43.2 (CP), U52.2 (CP), U53.9, X1.8 (OUT), X2.5 (OUT)
/clk50: DSP1.CT2, JP1.2 (B)
/clrreq: DSP1.BM2, U26.12
/data_ck: U3.11 (Cp), U4.11 (Cp), U5.11 (Cp), U6.11 (Cp), U7.11 (Cp), U8.11 (Cp), U9.11 (Cp), U10.11 (Cp), U26.3
/datastrobe: DSP1.AT2, U26.2
/disp_enb: U25.9 (Q), U29.9 (S2), U35.4
/dispsel: DSP1.CF2, U26.1, U26.13, U30.5, U30.6
/h0: J10.3 (B), U29.11 (S0), U52.14 (Q0)
/h1: J10.1 (A), U29.10 (S1), U51.1, U52.13 (Q1)
/ha0: U30.8, U40.6 (O2)
/ha1: U30.11, U40.9 (O3)
/hblk: U35.10, U40.12 (O4)
/hmid: U40.19 (O7), U49.7 (CEP), U49.10 (CET)
/hsyn: DSP1.AM1, J1.4, U1.7 (O1b)
/hsync: HSYNC1.3 (B), U53.12
/hsyni: HSYNC1.2 (C), U1.13 (I1b)
/hvs: U40.16 (O6), U51.4, U51.10
/incadr: U22.10 (CET), U40.2 (O0)
/ma0: DSP1.DK1
/ma1: DSP1.DK2
/ma2: DSP1.DL1, U11.2 (O0)
/ma3: DSP1.DL2, U11.5 (O1)
/ma4: DSP1.DN1, U11.6 (O2)
/ma5: DSP1.DN2, U11.9 (O3)
/ma6: DSP1.DP1, U11.12 (O4)
/ma7: DSP1.DP2, U11.15 (O5)
/ma8: DSP1.DR1, U11.16 (O6)
/ma9: DSP1.DR2, U11.19 (O7)
/ma10: DSP1.DS1, U12.2 (O0)
/ma11: DSP1.DS2, U12.5 (O1)
/ma12: DSP1.DU1, U12.6 (O2)
/ma13: DSP1.DU2, U12.9 (O3)
/ma14: DSP1.DV1, U12.12 (O4)
/ma15: DSP1.DV2, U12.15 (O5)
/ma16: DSP1.DT1, U12.16 (O6)
/ma17: DSP1.DM1, U12.19 (O7)
/ma18: DSP1.DJ1, U1.14 (O2a)
/ma19: DSP1.CM1, U1.12 (O3a)
/md0: DSP1.AA1, U3.13 (D4)
/md1: DSP1.AB1, U4.13 (D4)
/md2: DSP1.AC1, U5.13 (D4)
/md3: DSP1.AD1, U6.13 (D4)
/md4: DSP1.AE1, U3.14 (D5)
/md5: DSP1.AF1, U4.14 (D5)
/md6: DSP1.AH1, U5.14 (D5)
/md7: DSP1.AH2, U6.14 (D5)
/md8: DSP1.BA1, U3.17 (D6)
/md9: DSP1.BB1, U4.17 (D6)
/md10: DSP1.BC1, U5.17 (D6)
/md11: DSP1.BD1, U6.17 (D6)
/md12: DSP1.BE1, U3.18 (D7)
/md13: DSP1.BF1, U4.18 (D7)
/md14: DSP1.BH1, U5.18 (D7)
/md15: DSP1.BH2, U6.18 (D7)
/md16: DSP1.BK1, U3.3 (D0)
/md17: DSP1.BK2, U4.3 (D0)
/md18: DSP1.BL1, U5.3 (D0)
/md19: DSP1.BL2, U6.3 (D0)
/md20: DSP1.BN1, U3.4 (D1)
/md21: DSP1.BN2, U4.4 (D1)
/md22: DSP1.BP1, U5.4 (D1)
/md23: DSP1.BP2, U6.4 (D1)
/md24: DSP1.BR1, U3.7 (D2)
/md25: DSP1.BR2, U4.7 (D2)
/md26: DSP1.BS1, U5.7 (D2)
/md27: DSP1.BS2, U6.7 (D2)
/md28: DSP1.BU1, U3.8 (D3)
/md29: DSP1.BU2, U4.8 (D3)
/md30: DSP1.BV1, U5.8 (D3)
/md31: DSP1.BV2, U6.8 (D3)
/md32: DSP1.CA1, U7.13 (D4)
/md33: DSP1.CB1, U8.13 (D4)
/md34: DSP1.CC1, U9.13 (D4)
/md35: DSP1.CD1, U10.13 (D4)
/md36: DSP1.CE1, U7.14 (D5)
/md37: DSP1.CF1, U8.14 (D5)
/md38: DSP1.CH1, U9.14 (D5)
/md39: DSP1.CH2, U10.14 (D5)
/md40: DSP1.CK1, U7.17 (D6)
/md41: DSP1.CK2, U8.17 (D6)
/md42: DSP1.CL1, U9.17 (D6)
/md43: DSP1.CL2, U10.17 (D6)
/md44: DSP1.CN1, U7.18 (D7)
/md45: DSP1.CN2, U8.18 (D7)
/md46: DSP1.CP1, U9.18 (D7)
/md47: DSP1.CP2, U10.18 (D7)
/md48: DSP1.CR1, U7.3 (D0)
/md49: DSP1.CR2, U8.3 (D0)
/md50: DSP1.CS1, U9.3 (D0)
/md51: DSP1.CS2, U10.3 (D0)
/md52: DSP1.CU1, U7.4 (D1)
/md53: DSP1.CU2, U8.4 (D1)
/md54: DSP1.CV1, U9.4 (D1)
/md55: DSP1.CV2, U10.4 (D1)
/md56: DSP1.DA1, U7.7 (D2)
/md57: DSP1.DB1, U8.7 (D2)
/md58: DSP1.DC1, U9.7 (D2)
/md59: DSP1.DD1, U10.7 (D2)
/md60: DSP1.DE1, U7.8 (D3)
/md61: DSP1.DF1, U8.8 (D3)
/md62: DSP1.DH1, U9.8 (D3)
/md63: DSP1.DH2, U10.8 (D3)
/mdata6416: DSP1.DM2, U1.18 (O0a)
/mdatarw: DSP1.DT2, U1.16 (O1a)
/memrq: U35.5, U40.5 (O1)
/pu_adrct: R4.2, U22.1 (~MR), U23.1 (~MR), U24.1 (~MR), U25.10 (~S), U32.1 (~MR)
/pu_hctr: R2.1, U42.3 (D0), U42.4 (D1), U42.5 (D2), U42.6 (D3), U42.9 (~PE), U43.3 (D0), U43.4 (D1), U43.5 (D2), U43.6 (D3), U43.9 (~PE), U48.1 (~R), U48.4 (~S), U52.1 (~MR), U52.3 (D0), U52.4 (D1), U52.5 (D2), U52.6 (D3), U52.7 (CEP), U52.9 (~PE), U52.10 (CET)
/pu_op: F1.1 (A), F2.1 (A), RN1.10 (R9), U1.2 (I0a), U1.4 (I1a); also elsewhere on the board
/pu_vcnt: R1.2, U38.3 (D0), U38.4 (D1), U38.5 (D2), U38.6 (D3), U38.9 (~PE), U39.3 (D0), U39.4 (D1), U39.5 (D2), U39.6 (D3), U39.9 (~PE), U49.3 (D0), U49.4 (D1), U49.5 (D2), U49.6 (D3), U49.9 (~PE)
/si0: U17.1 (Ds), U21.13 (Qh)
/si1: U16.1 (Ds), U20.13 (Qh)
/si2: U15.1 (Ds), U19.13 (Qh)
/si3: U14.1 (Ds), U18.13 (Qh)
/sr_clk: J9.2 (C), U14.7 (Clk), U15.7 (Clk), U16.7 (Clk), U17.7 (Clk), U18.7 (Clk), U19.7 (Clk), U20.7 (Clk), U21.7 (Clk)
/sr_enb: J9.1 (A), U14.6 (CE), U15.6 (CE), U16.6 (CE), U17.6 (CE), U18.6 (CE), U19.6 (CE), U20.6 (CE), U21.6 (CE), U51.3
/sr_ld: U14.15 (PE), U15.15 (PE), U16.15 (PE), U17.15 (PE), U18.15 (PE), U19.15 (PE), U20.15 (PE), U21.15 (PE), U47.6
/sr_pu: RN2.2 (R1), U14.9 (Clr), U15.9 (Clr), U16.9 (Clr), U17.9 (Clr), U18.9 (Clr), U19.9 (Clr), U20.9 (Clr), U21.9 (Clr)
/va0: U30.9, U36.6 (O2)
/va1: JP1.1 (A), U30.12, U36.9 (O3)
/vblk: U22.7 (CEP), U23.7 (CEP), U24.7 (CEP), U32.7 (CEP), U35.3, U35.11, U36.12 (O4)
/vend: U38.1 (~MR), U39.1 (~MR), U49.1 (~MR), U51.8
/video: DSP1.AE2, J1.2, U1.3 (O3b)
/videoi: U1.17 (I3b), U53.10
/vsyn: DSP1.AJ1, J1.5, U1.9 (O0b)
/vsync: U53.2, VSYNC1.3 (B)
/vsyni: U1.11 (I0b), VSYNC1.2 (C)
/~dispreq: DSP1.CE2, U26.8
/~dispsel: U1.1 (OEa), U11.1 (OE), U11.11 (Cp), U12.1 (OE), U12.11 (Cp), U30.4
/~ds_iod: DSP1.CJ2
/~hsync: HSYNC1.1 (A), U40.15 (O5), U53.13
/~rd_bma: DSP1.AM2, U44.1 (OEa), U44.19 (OEb), U45.1 (OEa), U45.19 (OEb)
/~sr_iod: DSP1.BJ2
/~vsync: U36.15 (O5), U53.1, VSYNC1.1 (A)
/~wr_bma: DSP1.AJ2, U33.11 (Cp), U34.11 (Cp)
/~wr_von: DSP1.AF2, U25.11 (C)
GND: C1.2, C2.2, C3.2, C4.2, C5.2, C6.2, C7.2, C8.2, C9.2, C10.2, C12.2, C13.2, C14.2, C15.2, C16.2, C17.2, C18.2, C19.2, C20.2, C21.2, C22.2, C23.2, C24.2, C25.2, C26.2, Cp1.2, Cp2.2, Cp3.2, Cp4.2, Cp5.2, DSP1.AC2, DSP1.AT1, DSP1.BC2, DSP1.BJ1, DSP1.BT1, DSP1.CC2, DSP1.CJ1, DSP1.DC2, DSP1.G1 (GND), DSP1.G2 (GND), DSP1.G3 (GND), DSP1.G4 (GND), DSP1.G5 (GND), DSP1.G6 (GND), DSP1.G7 (GND), DSP1.G8 (GND), DSP1.G10, DSP1.G11, DSP1.G12, DSP1.G13, DSP1.G14, DSP1.G15, DSP1.G16, DSP1.G17, DSP1.G18, DSP1.G19, DSP1.G20, DSP1.G21, DSP1.G22, DSP1.G23, DSP1.G24, DSP1.G25, F1.3 (B), F2.3 (B), J1.1, J1.3, JP3.2 (B), JP4.2 (B), SR1.7 (A1), SR1.8 (A0), SR1.12 (GND), SR1.20 (~OE), U1.10 (GND), U1.19 (OEb), U3.1 (OE), U3.10 (GND), U4.1 (OE), U4.10 (GND), U5.1 (OE), U5.10 (GND), U6.1 (OE), U6.10 (GND), U7.1 (OE), U7.10 (GND), U8.1 (OE), U8.10 (GND), U9.1 (OE), U9.10 (GND), U10.1 (OE), U10.10 (GND), U11.10 (GND), U12.10 (GND), U14.8 (GND), U15.8 (GND), U16.8 (GND), U17.8 (GND), U18.1 (Ds), U18.8 (GND), U19.1 (Ds), U19.8 (GND), U20.1 (Ds), U20.8 (GND), U21.1 (Ds), U21.8 (GND), U22.8 (GND), U23.8 (GND), U24.8 (GND), U25.2 (D), U25.3 (C), U25.7 (GND), U26.7 (GND), U29.1 (I3), U29.2 (I2), U29.3 (I1), U29.4 (I0), U29.7 (~E), U29.8 (GND), U30.7 (GND), U32.8 (GND), U33.1 (OE), U33.10 (GND), U34.1 (OE), U34.10 (GND), U35.7 (GND), U36.1 (OE), U36.10 (GND), U37.12 (GND), U37.18 (~CS), U37.20 (~OE), U38.8 (GND), U39.8 (GND), U40.1 (OE), U40.10 (GND), U42.8 (GND), U43.8 (GND), U44.10 (GND), U45.10 (GND), U47.7 (GND), U48.7 (GND), U49.8 (GND), U51.7 (GND), U52.8 (GND), U53.7 (GND), U54.1, U54.2, U54.3, U54.4, U54.5, U54.6, U54.7, U54.8, U55.1, U55.2, U55.3, U55.4, U55.5, U55.6, U55.7, U55.8, X1.7 (GND), X2.4 (GND); also elsewhere on the board
unnamed 155: F1.2 (C), U1.6 (I2a); also elsewhere on the board
unnamed 156: F2.2 (C), U1.8 (I3a); also elsewhere on the board
unnamed: J8.1 (A), U29.6 (~Z)
unnamed: J8.3 (B), U29.5 (Z)
unnamed: J8.2 (C), U35.9
unnamed: J10.2 (C), U51.2
unnamed: JP2.1 (A), SR1.21 (VPP)
unnamed: JP3.1 (A), SR1.19 (A10)
unnamed: JP4.1 (A), SR1.18 (~CS)
unnamed: RN1.2 (R1), U44.2 (I0a), U54.16
unnamed: RN1.3 (R2), U44.4 (I1a), U54.15
unnamed: RN1.4 (R3), U44.6 (I2a), U54.14
unnamed: RN1.5 (R4), U44.8 (I3a), U54.13
unnamed: RN1.6 (R5), U44.11 (I0b), U54.12
unnamed: RN1.7 (R6), U44.13 (I1b), U54.11
unnamed: RN1.8 (R7), U44.15 (I2b), U54.10
unnamed: RN1.9 (R8), U44.17 (I3b), U54.9
unnamed: RN2.3 (R2), U45.2 (I0a), U55.16
unnamed: RN2.4 (R3), U45.4 (I1a), U55.15
unnamed: RN2.5 (R4), U45.6 (I2a), U55.14
unnamed: RN2.6 (R5), U45.8 (I3a), U55.13
unnamed: RN2.7 (R6), U45.11 (I0b), U55.12
unnamed: RN2.8 (R7), U45.13 (I1b), U55.11
unnamed: RN2.9 (R8), U45.15 (I2b), U55.10
unnamed: RN2.10 (R9), U45.17 (I3b), U55.9
unnamed: SR1.6 (A2), U35.1, U43.14 (Q0)
unnamed: SR1.5 (A3), U35.13, U43.13 (Q1)
unnamed: SR1.4 (A4), U43.12 (Q2)
unnamed: SR1.3 (A5), U43.11 (Q3)
unnamed: SR1.2 (A6), U42.14 (Q0)
unnamed: SR1.1 (A7), U42.13 (Q1)
unnamed: SR1.23 (A8), U42.12 (Q2)
unnamed: SR1.22 (A9), U42.11 (Q3)
unnamed: SR1.9 (D0), U40.3 (D0)
unnamed: SR1.10 (D1), U40.4 (D1)
unnamed: SR1.11 (D2), U40.7 (D2)
unnamed: SR1.13 (D3), U40.8 (D3)
unnamed: SR1.14 (D4), U40.13 (D4)
unnamed: SR1.15 (D5), U40.14 (D5)
unnamed: SR1.16 (D6), U40.17 (D6)
unnamed: SR1.17 (D7), U40.18 (D7)
unnamed: U10.2 (O0), U21.2 (A)
unnamed: U10.5 (O1), U21.3 (B)
unnamed: U10.6 (O2), U21.4 (C)
unnamed: U10.9 (O3), U21.5 (D)
unnamed: U10.12 (O4), U21.10 (E)
unnamed: U10.15 (O5), U21.11 (F)
unnamed: U10.16 (O6), U21.12 (G)
unnamed: U10.19 (O7), U21.14 (H)
unnamed: U11.3 (D0), U22.14 (Q0)
unnamed: U11.4 (D1), U22.13 (Q1)
unnamed: U11.7 (D2), U22.12 (Q2)
unnamed: U11.8 (D3), U22.11 (Q3)
unnamed: U11.13 (D4), U32.14 (Q0)
unnamed: U11.14 (D5), U32.13 (Q1)
unnamed: U11.17 (D6), U32.12 (Q2)
unnamed: U11.18 (D7), U32.11 (Q3)
unnamed: U12.3 (D0), U24.14 (Q0)
unnamed: U12.4 (D1), U24.13 (Q1)
unnamed: U12.7 (D2), U24.12 (Q2)
unnamed: U12.8 (D3), U24.11 (Q3)
unnamed: U12.13 (D4), U23.14 (Q0)
unnamed: U12.14 (D5), U23.13 (Q1)
unnamed: U12.17 (D6), U23.12 (Q2)
unnamed: U12.18 (D7), U23.11 (Q3)
unnamed: U3.2 (O0), U14.2 (A)
unnamed: U3.5 (O1), U14.3 (B)
unnamed: U3.6 (O2), U14.4 (C)
unnamed: U3.9 (O3), U14.5 (D)
unnamed: U3.12 (O4), U14.10 (E)
unnamed: U3.15 (O5), U14.11 (F)
unnamed: U3.16 (O6), U14.12 (G)
unnamed: U3.19 (O7), U14.14 (H)
unnamed: U14.13 (Qh), U29.12 (I7)
unnamed: U4.2 (O0), U15.2 (A)
unnamed: U4.5 (O1), U15.3 (B)
unnamed: U4.6 (O2), U15.4 (C)
unnamed: U4.9 (O3), U15.5 (D)
unnamed: U4.12 (O4), U15.10 (E)
unnamed: U4.15 (O5), U15.11 (F)
unnamed: U4.16 (O6), U15.12 (G)
unnamed: U4.19 (O7), U15.14 (H)
unnamed: U15.13 (Qh), U29.13 (I6)
unnamed: U5.2 (O0), U16.2 (A)
unnamed: U5.5 (O1), U16.3 (B)
unnamed: U5.6 (O2), U16.4 (C)
unnamed: U5.9 (O3), U16.5 (D)
unnamed: U5.12 (O4), U16.10 (E)
unnamed: U5.15 (O5), U16.11 (F)
unnamed: U5.16 (O6), U16.12 (G)
unnamed: U5.19 (O7), U16.14 (H)
unnamed: U16.13 (Qh), U29.14 (I5)
unnamed: U6.2 (O0), U17.2 (A)
unnamed: U6.5 (O1), U17.3 (B)
unnamed: U6.6 (O2), U17.4 (C)
unnamed: U6.9 (O3), U17.5 (D)
unnamed: U6.12 (O4), U17.10 (E)
unnamed: U6.15 (O5), U17.11 (F)
unnamed: U6.16 (O6), U17.12 (G)
unnamed: U6.19 (O7), U17.14 (H)
unnamed: U17.13 (Qh), U29.15 (I4)
unnamed: U7.2 (O0), U18.2 (A)
unnamed: U7.5 (O1), U18.3 (B)
unnamed: U7.6 (O2), U18.4 (C)
unnamed: U7.9 (O3), U18.5 (D)
unnamed: U7.12 (O4), U18.10 (E)
unnamed: U7.15 (O5), U18.11 (F)
unnamed: U7.16 (O6), U18.12 (G)
unnamed: U7.19 (O7), U18.14 (H)
unnamed: U8.2 (O0), U19.2 (A)
unnamed: U8.5 (O1), U19.3 (B)
unnamed: U8.6 (O2), U19.4 (C)
unnamed: U8.9 (O3), U19.5 (D)
unnamed: U8.12 (O4), U19.10 (E)
unnamed: U8.15 (O5), U19.11 (F)
unnamed: U8.16 (O6), U19.12 (G)
unnamed: U8.19 (O7), U19.14 (H)
unnamed: U9.2 (O0), U20.2 (A)
unnamed: U9.5 (O1), U20.3 (B)
unnamed: U9.6 (O2), U20.4 (C)
unnamed: U9.9 (O3), U20.5 (D)
unnamed: U9.12 (O4), U20.10 (E)
unnamed: U9.15 (O5), U20.11 (F)
unnamed: U9.16 (O6), U20.12 (G)
unnamed: U9.19 (O7), U20.14 (H)
unnamed: U22.3 (D0), U33.2 (O0)
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

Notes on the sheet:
Address-gen
Target 65 MHz for VGA 1024x768 @ 60Hz ALS163 40MHz F163 90 MHz
Added U1, U47 & U48
Alternative 50 Hz clock Set for Lilith V2
Removed U1,2 & 13. Moved to IOB board.
Video-shifter
(only Lilith V2)
H-counter
Video-control
Select White/Black
V-counter

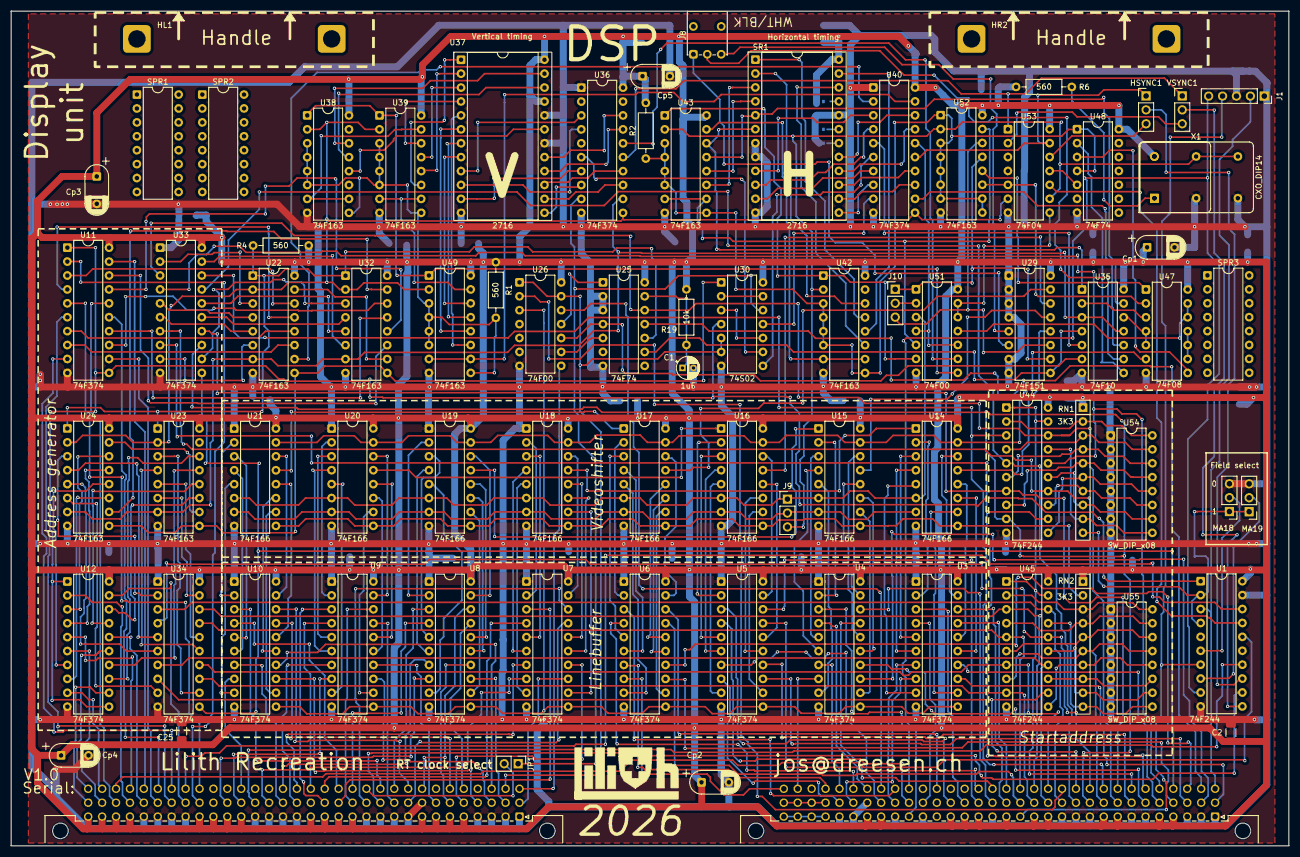
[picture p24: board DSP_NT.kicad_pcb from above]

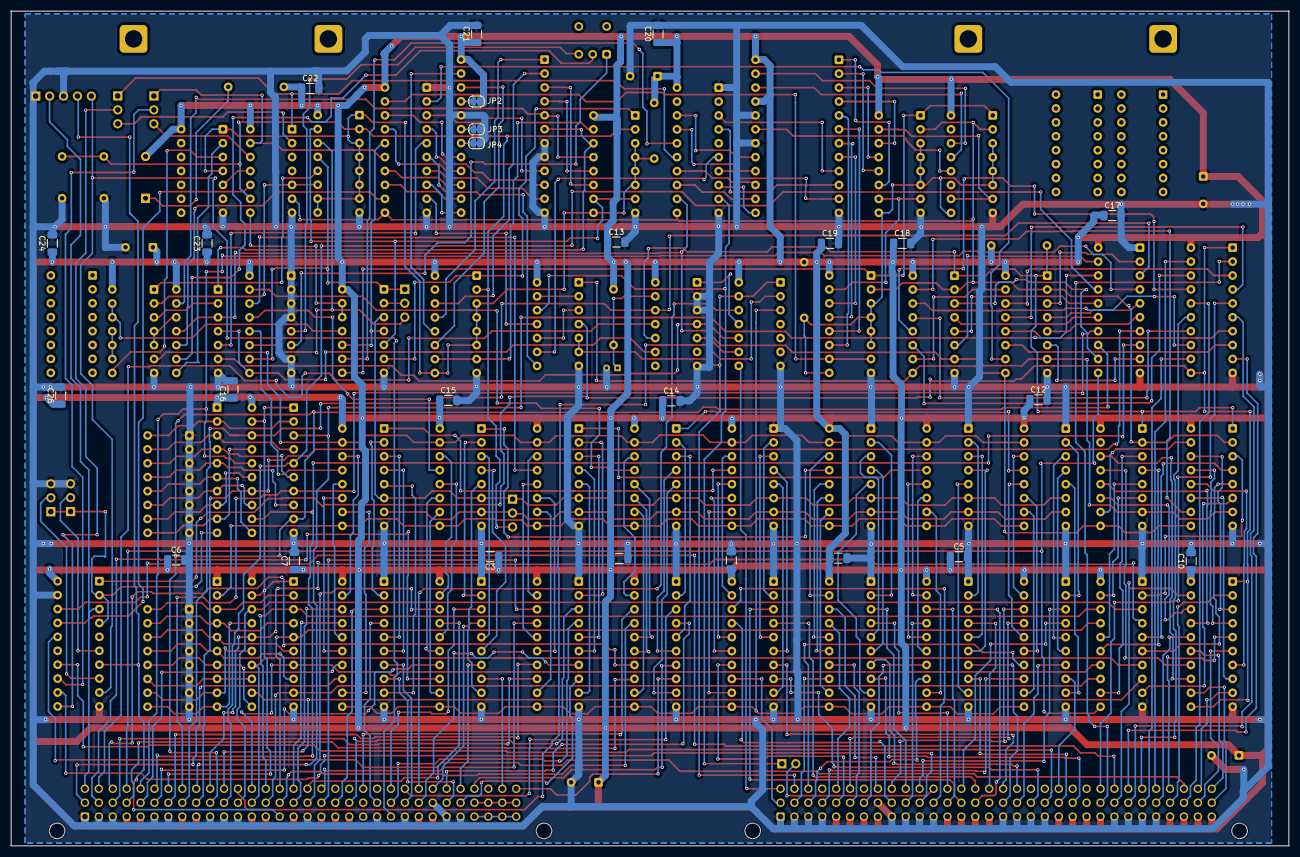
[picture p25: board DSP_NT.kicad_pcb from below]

Board: 2 copper layers, 233.3 x 152.4 mm, 105 parts (25 on the bottom side), 339 nets.

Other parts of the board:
MA18, MA19: Jumper_3_Open; PinHeader_1x03_P2.54mm_Vertical

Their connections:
/pu_op: MA18.1 (A), MA19.1 (A); also elsewhere on the board
GND: MA18.3 (B), MA19.3 (B); also elsewhere on the board
unnamed 155: MA18.2 (C); also elsewhere on the board
unnamed 156: MA19.2 (C); also elsewhere on the board

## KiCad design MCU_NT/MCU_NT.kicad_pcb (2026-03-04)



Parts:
C1: 220p; C_Disc_D5.0mm_W2.5mm_P2.50mm
C2, C3, C4, C5, C6, C7, C8, C9, C10, C11, C12, C13, C14, C15, C16, C17, C18, C19, C20, C21, C22, C23, C24, C25, C26: 100n; C_1206_3216Metric_Pad1.33x1.80mm_HandSolder
C27: 10p; C_Disc_D5.0mm_W2.5mm_P2.50mm
Cp1, Cp2, Cp3, Cp4, Cp5: 68U; CP_PHP
D1: Boot; LED_D3.0mm_Horizontal_O3.81mm_Z10.0mm
Field1: Hi/Lo Bank; PinHeader_1x03_P2.54mm_Vertical
H1, H2, H3, H4: MountingHole; MountingHole_2.7mm
HL1, HL2: MountingHole; Handle
JP1: CKsel; SolderJumper-3_P1.3mm_Bridged12_RoundedPad1.0x1.5mm_NumberL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
JP2: Jumper_2_Open; SolderJumper-2_P1.3mm_Bridged_RoundedPad1.0x1.5mm
L1: 10uH; L_Axial_L5.3mm_D2.2mm_P7.62mm_Horizontal_Vishay_IM-1
MCU1: lilith_nt_edge; Lilith_edge
OSC1: 74LS321; DIP-16_W7.62mm
R2: 560; R_Axial_DIN0204_L3.6mm_D1.6mm_P7.62mm_Horizontal
R6: 330; R_Axial_DIN0204_L3.6mm_D1.6mm_P7.62mm_Horizontal
RN1, RN2: 3K3; R_Array_SIP10
U1, U2, U3, U4, U5: WSI57C49; DuoDil24
U11: 74S32; DIP-14_W7.62mm
U13, U17: 74S08; DIP-14_W7.62mm
U15, U23, U55: 74S74; DIP-14_W7.62mm
U16: 74S00; DIP-14_W7.62mm
U18: 74S04; DIP-14_W7.62mm
U21: 74S10; DIP-14_W7.62mm
U22: 74S64; DIP-14_W7.62mm
U24: 74LS21; DIP-14_W7.62mm
U25, U26, U27, U30, U31: 74S374; DIP-20_W7.62mm
U28, U29, U42, U44, U48: 74S244; DIP-20_W7.62mm
U32, U33, U41, U43: 74S138; DIP-16_W7.62mm
U34: 74LS244; DIP-20_W7.62mm
U35, U45: 74LS377; DIP-20_W7.62mm
U36, U46: 74LS32; DIP-14_W7.62mm
U37: 74S157; DIP-16_W7.62mm
U38, U39, U40: 82S131; DIP-16_W7.62mm_Socket
U47: 74LS348; DIP-16_W7.62mm
U49, U50, U51: AMD2911; DIP-20_W7.62mm
U54: 74S140; DIP-14_W7.62mm
U56: 74S153; DIP-16_W7.62mm
Version1: OldNew; PinHeader_1x03_P2.00mm_Vertical
Y1: 13.3MHz; Crystal_HC18-U_Horizontal

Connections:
+12V: MCU1.AD2, MCU1.BD2, MCU1.CD2, MCU1.DD2
-12V: MCU1.AB2, MCU1.BB2, MCU1.CB2, MCU1.DB2
/bus0: MCU1.AK1, U34.3 (O3b), U35.18 (D7), U38.5 (A0), U39.5 (A0), U40.5 (A0), U44.3 (O3b)
/bus1: MCU1.AK2, U34.5 (O2b), U35.17 (D6), U38.6 (A1), U39.6 (A1), U40.6 (A1), U44.5 (O2b)
/bus2: MCU1.AL1, U34.7 (O1b), U35.14 (D5), U38.7 (A2), U39.7 (A2), U40.7 (A2), U44.7 (O1b)
/bus3: MCU1.AL2, U34.9 (O0b), U35.13 (D4), U38.4 (A3), U39.4 (A3), U40.4 (A3), U44.9 (O0b)
/bus4: MCU1.AN1, U34.12 (O3a), U35.8 (D3), U38.3 (A4), U39.3 (A4), U40.3 (A4), U44.12 (O3a)
/bus5: MCU1.AN2, U34.14 (O2a), U35.7 (D2), U38.2 (A5), U39.2 (A5), U40.2 (A5), U44.14 (O2a)
/bus6: MCU1.AP1, U34.16 (O1a), U35.4 (D1), U38.1 (A6), U39.1 (A6), U40.1 (A6), U44.16 (O1a)
/bus7: MCU1.AP2, U34.18 (O0a), U35.3 (D0), U38.15 (A7), U39.15 (A7), U40.15 (A7), U44.18 (O0a)
/bus8: MCU1.AR1, U42.3 (O3b)
/bus9: MCU1.AR2, U42.5 (O2b)
/bus10: MCU1.AS1, U42.7 (O1b)
/bus11: MCU1.AS2, U42.9 (O0b)
/bus12: MCU1.AU1, U42.12 (O3a)
/bus13: MCU1.AU2, U42.14 (O2a)
/bus14: MCU1.AV1, U42.16 (O1a)
/bus15: MCU1.AV2, U42.18 (O0a)
/cc: MCU1.DM1
/ccx: MCU1.DR2, U11.5
/cp_pu: OSC1.5 (ffd), RN2.6 (R5), U15.1 (~R), U15.10 (~S), U22.12 (A3), U22.13 (A4), U23.4 (~S), U23.10 (~S), U32.6 (E3), U54.1, U54.2, U54.12, U54.13, U56.3 (I3a), U56.4 (I2a), U56.5 (I1a), U56.12 (I2b), U56.13 (I3b), Version1.1 (A)
/cpu_clk: MCU1.BT2, U35.11 (CP), U45.11 (CP), U54.6
/dataportrdy: MCU1.AJ2, U23.12 (D), U23.13 (~R)
/ie0: U34.17 (I3b), U35.19 (Q7), U36.1
/ie1: U34.15 (I2b), U35.16 (Q6), U36.4
/ie2: U34.13 (I1b), U35.15 (Q5), U46.13
/ie3: U34.11 (I0b), U35.12 (Q4), U46.9
/ie4: U34.8 (I3a), U35.9 (Q3), U46.4
/ie5: U34.6 (I2a), U35.6 (Q2), U46.1
/ie6: U34.4 (I1a), U35.5 (Q1), U36.10
/ie7: U34.2 (I0a), U35.2 (Q0), U36.13
/ifurdy: MCU1.AM2, U23.1 (~R), U23.2 (D)
/intdis: U15.8 (~Q), U38.14 (A8), U39.14 (A8), U40.14 (A8)
/irq0: MCU1.BP2, RN1.9 (R8), U45.18 (D7)
/irq1: MCU1.BR1, RN1.8 (R7), U45.17 (D6)
/irq2: MCU1.BR2, RN1.7 (R6), U45.14 (D5)
/irq3: MCU1.BS1, RN1.6 (R5), U45.13 (D4)
/irq4: MCU1.BS2, RN1.5 (R4), U45.8 (D3)
/irq5: MCU1.BU1, RN1.4 (R3), U45.7 (D2)
/irq6: MCU1.BU2, RN1.3 (R2), U45.4 (D1)
/irq7: MCU1.BV1, RN1.2 (R1), U45.3 (D0)
/mclk: JP1.3 (B), OSC1.10 (fb), U23.3 (C), U23.11 (C), U55.3 (C), U55.11 (C)
/mcu_clk: MCU1.BN2, U15.3 (C), U15.11 (C), U25.11 (Cp), U26.11 (Cp), U27.11 (Cp), U30.11 (Cp), U31.11 (Cp), U49.1 (cp), U50.1 (cp), U51.1 (cp), U54.8
/mcu_pu: Field1.3 (B), RN2.7 (R6), U33.6 (E3), U37.5 (A1), U48.8 (I3a), U49.3 (~re), U50.3 (~re), U51.3 (~re), U51.17 (Cn)
/memrdy: U16.4, U16.12, U22.8 (z)
/mir0: MCU1.CD1, U25.2 (O0), U33.1 (A0), U43.1 (A0), U44.17 (I3b)
/mir1: MCU1.CE2, U25.5 (O1), U33.2 (A1), U43.2 (A1), U44.15 (I2b)
/mir2: MCU1.CE1, U25.6 (O2), U33.3 (A2), U43.3 (A2), U44.13 (I1b)
/mir3: MCU1.CF2, U25.9 (O3), U33.5 (E2), U43.6 (E3), U44.11 (I0b)
/mir4: MCU1.CF1, U25.12 (O4), U32.1 (A0), U41.1 (A0), U44.8 (I3a)
/mir5: MCU1.CH2, U25.15 (O5), U32.2 (A1), U41.2 (A1), U44.6 (I2a)
/mir6: MCU1.CH1, U25.16 (O6), U32.3 (A2), U41.3 (A2), U44.4 (I1a)
/mir7: MCU1.CJ2, U25.19 (O7), U32.5 (E2), U41.6 (E3), U44.2 (I0a)
/mir8: MCU1.CK1, U26.2 (O0)
/mir9: MCU1.CK2, U26.5 (O1)
/mir10: MCU1.CL1, U26.6 (O2)
/mir11: MCU1.CL2, U26.9 (O3)
/mir12: MCU1.CN1, U18.13, U26.12 (O4), U32.4 (E1), U33.4 (E1), U41.4 (E1), U43.4 (E1)
/mir13: MCU1.CN2, U26.15 (O5)
/mir14: MCU1.CP1, U11.4, U17.12, U26.16 (O6)
/mir15: MCU1.CP2, U16.1, U16.2, U16.5, U26.19 (O7)
/mir16: MCU1.CR1, U27.2 (O0), U37.13 (B2)
/mir17: MCU1.CR2, U27.5 (O1), U37.3 (B0), U37.10 (B3)
/mir18: MCU1.CS1, U27.6 (O2), U37.6 (B1)
/mir19: MCU1.CS2, U27.9 (O3)
/mir20: MCU1.CU1, U27.12 (O4)
/mir21: MCU1.CU2, U27.15 (O5)
/mir22: MCU1.CV1, U27.16 (O6)
/mir23: MCU1.CV2, U27.19 (O7)
/mir24: MCU1.DD1, U30.2 (O0)
/mir25: MCU1.DE2, U30.5 (O1)
/mir26: MCU1.DE1, U30.6 (O2)
/mir27: MCU1.DF2, U30.9 (O3)
/mir28: MCU1.DF1, U28.17 (I3b), U30.12 (O4)
/mir29: MCU1.DH2, U28.15 (I2b), U30.15 (O5)
/mir30: MCU1.DH1, U28.13 (I1b), U30.16 (O6)
/mir31: MCU1.DJ2, U28.11 (I0b), U30.19 (O7)
/mir32: MCU1.DK1, U28.8 (I3a), U31.2 (O0)
/mir33: MCU1.DK2, U28.6 (I2a), U31.5 (O1)
/mir34: MCU1.DL1, U28.4 (I1a), U31.6 (O2)
/mir35: MCU1.DL2, U28.2 (I0a), U31.9 (O3)
/mir36: MCU1.DN1, U29.17 (I3b), U31.12 (O4)
/mir37: MCU1.DN2, U29.15 (I2b), U31.15 (O5)
/mir38: MCU1.DP1, U29.13 (I1b), U31.16 (O6)
/mir39: MCU1.DP2, U29.11 (I0b), U31.19 (O7)
/mp0: U28.3 (O3b), U40.12 (Q0), U48.3 (O3b), U51.7 (D0)
/mp1: U28.5 (O2b), U40.11 (Q1), U48.5 (O2b), U51.6 (D1)
/mp2: U28.7 (O1b), U40.10 (Q2), U48.7 (O1b), U51.5 (D2)
/mp3: U28.9 (O0b), U40.9 (Q3), U48.9 (O0b), U51.4 (D3)
/mp4: U28.12 (O3a), U39.12 (Q0), U48.12 (O3a), U50.7 (D0)
/mp5: U28.14 (O2a), U39.11 (Q1), U48.14 (O2a), U50.6 (D1)
/mp6: U28.16 (O1a), U39.10 (Q2), U48.16 (O1a), U50.5 (D2)
/mp7: U28.18 (O0a), U39.9 (Q3), U48.18 (O0a), U50.4 (D3)
/mp8: U29.3 (O3b), U29.18 (O0a), U38.12 (Q0), U49.7 (D0)
/mp9: U29.5 (O2b), U29.16 (O1a), U38.11 (Q1), U49.6 (D1)
/mp10: U29.7 (O1b), U29.14 (O2a), U38.10 (Q2), U49.5 (D2)
/mp11: U29.9 (O0b), U29.12 (O3a), U38.9 (Q3), U49.4 (D3)
/req: MCU1.CT2, U24.5, U47.15 (E0)
/rom0: U1.9 (D0), U25.3 (D0)
/rom1: U1.10 (D1), U25.4 (D1)
/rom2: U1.11 (D2), U25.7 (D2)
/rom3: U1.13 (D3), U25.8 (D3)
/rom4: U1.14 (D4), U25.13 (D4)
/rom5: U1.15 (D5), U25.14 (D5)
/rom6: U1.16 (D6), U25.17 (D6)
/rom7: U1.17 (D7), U25.18 (D7)
/rom8: U2.9 (D0), U26.3 (D0)
/rom9: U2.10 (D1), U26.4 (D1)
/rom10: U2.11 (D2), U26.7 (D2)
/rom11: U2.13 (D3), U26.8 (D3)
/rom12: U2.14 (D4), U26.13 (D4)
/rom13: U2.15 (D5), U26.14 (D5)
/rom14: U2.16 (D6), U26.17 (D6)
/rom15: U2.17 (D7), U26.18 (D7)
/rom16: U3.9 (D0), U27.3 (D0)
/rom17: U3.10 (D1), U27.4 (D1)
/rom18: U3.11 (D2), U27.7 (D2)
/rom19: U3.13 (D3), U27.8 (D3)
/rom20: U3.14 (D4), U27.13 (D4)
/rom21: U3.15 (D5), U27.14 (D5)
/rom22: U3.16 (D6), U27.17 (D6)
/rom23: U3.17 (D7), U27.18 (D7)
/rom24: U4.9 (D0), U30.3 (D0)
/rom25: U4.10 (D1), U30.4 (D1)
/rom26: U4.11 (D2), U30.7 (D2)
/rom27: U4.13 (D3), U30.8 (D3)
/rom28: U4.14 (D4), U30.13 (D4)
/rom29: U4.15 (D5), U30.14 (D5)
/rom30: U4.16 (D6), U30.17 (D6)
/rom31: U4.17 (D7), U30.18 (D7)
/rom32: U5.9 (D0), U31.3 (D0)
/rom33: U5.10 (D1), U31.4 (D1)
/rom34: U5.11 (D2), U31.7 (D2)
/rom35: U5.13 (D3), U31.8 (D3)
/rom36: U5.14 (D4), U31.13 (D4)
/rom37: U5.15 (D5), U31.14 (D5)
/rom38: U5.16 (D6), U31.17 (D6)
/rom39: U5.17 (D7), U31.18 (D7)
/run: MCU1.BE2, RN2.3 (R2), U18.11
/ss_clk: MCU1.BC1, RN2.5 (R4), U17.5, U17.10
/ste: MCU1.BB1
/ua0: MCU1.DV2, U1.8 (A0), U2.8 (A0), U3.8 (A0), U4.8 (A0), U5.8 (A0), U51.12 (Y0)
/ua1: MCU1.DU2, U1.7 (A1), U2.7 (A1), U3.7 (A1), U4.7 (A1), U5.7 (A1), U51.13 (Y1)
/ua2: MCU1.DT2, U1.6 (A2), U2.6 (A2), U3.6 (A2), U4.6 (A2), U5.6 (A2), U51.14 (Y2)
/ua3: MCU1.DS2, U1.5 (A3), U2.5 (A3), U3.5 (A3), U4.5 (A3), U5.5 (A3), U51.15 (Y3)
/ua4: MCU1.DA1, U1.4 (A4), U2.4 (A4), U3.4 (A4), U4.4 (A4), U5.4 (A4), U50.12 (Y0)
/ua5: MCU1.DV1, U1.3 (A5), U2.3 (A5), U3.3 (A5), U4.3 (A5), U5.3 (A5), U50.13 (Y1)
/ua6: MCU1.DU1, U1.2 (A6), U2.2 (A6), U3.2 (A6), U4.2 (A6), U5.2 (A6), U50.14 (Y2)
/ua7: MCU1.DS1, U1.1 (A7), U2.1 (A7), U3.1 (A7), U4.1 (A7), U5.1 (A7), U50.15 (Y3)
/ua8: MCU1.DR1, U1.23 (A8), U2.23 (A8), U3.23 (A8), U4.23 (A8), U5.23 (A8), U49.12 (Y0)
/ua9: MCU1.DM2, U1.22 (A9), U2.22 (A9), U3.22 (A9), U4.22 (A9), U5.22 (A9), U49.13 (Y1)
/ua10: MCU1.DC1, U1.21 (A10), U2.21 (A10), U3.21 (A10), U4.21 (A10), U5.21 (A10), U49.14 (Y2)
/ua11: MCU1.DB1, U1.19 (ce2), U2.19 (ce2), U3.19 (ce2), U4.19 (ce2), U5.19 (ce2), U49.15 (Y3)
/vector0: U47.9 (A0), U48.17 (I3b)
/vector1: U47.7 (A1), U48.15 (I2b)
/vector2: U47.6 (A2), U48.13 (I1b)
/~cpuclk_dis: MCU1.BE1, RN2.2 (R1), U17.13
/~dis2911: MCU1.BF2, RN2.9 (R8), U18.9
/~dismir: MCU1.BD1, RN1.10 (R9), U18.1
/~ds_alu: MCU1.AF1, U13.8
/~ds_f: MCU1.AH2, U21.13, U41.9 (O6)
/~ds_hmar: MCU1.AH1, U41.10 (O5)
/~ds_ioa: MCU1.BA1, U32.9 (O6)
/~ds_iod: MCU1.AF2, U32.7 (O7)
/~ds_irm: U35.1 (~E), U41.15 (O0)
/~ds_mar: MCU1.AC1, U21.10, U32.12 (O3)
/~ds_mdst: MCU1.AE2, U32.10 (O5)
/~ds_md: MCU1.AA1, U21.11, U32.14 (O1)
/~ds_pc: MCU1.AB1, U21.1, U32.13 (O2)
/~ds_sr: MCU1.AD1, U32.11 (O4)
/~intdis: D1.1 (K), MCU1.CA1, U15.9 (Q), U24.1, U24.2, U24.4
/~io0_wait: MCU1.BV2, RN2.4 (R3), U16.9
/~iox_wait: MCU1.CC1, RN2.8 (R7), U16.10
/~mapenabl: MCU1.CM2, U11.8, U17.1, U38.13 (~ce), U39.13 (~ce), U40.13 (~ce), Version1.3 (B)
/~mclk: JP1.2 (C), MCU1.AT2
/~mir12: U13.10, U17.2, U18.12, U44.1 (OEa), U44.19 (OEb)
/~req: U47.14 (GS)
/~reset: MCU1.BJ2, RN2.10 (R9), U13.5, U15.13 (~R), U49.9 (~zero), U50.9 (~zero), U51.9 (~zero), U55.1 (~R), U55.13 (~R)
/~sr_12: MCU1.BN1, U43.11 (O4)
/~sr_6800: MCU1.BM2, U43.10 (O5)
/~sr_alu: MCU1.AE1, U33.15 (O0)
/~sr_f: MCU1.BL2, U43.9 (O6)
/~sr_iod: MCU1.BK2, U33.7 (O7)
/~sr_ir4: U11.10, U11.13, U18.5, U21.5, U33.12 (O3)
/~sr_ir8*: MCU1.BK1, U21.2, U24.12, U33.9 (O6)
/~sr_ir8+: MCU1.BH1, U21.4, U24.9, U33.11 (O4)
/~sr_ir8-: MCU1.BH2, U21.3, U24.10, U33.10 (O5), U42.2 (I0a), U42.4 (I1a), U42.6 (I2a), U42.8 (I3a), U42.11 (I0b), U42.13 (I1b), U42.15 (I2b), U42.17 (I3b)
/~sr_irm: U34.1 (OEa), U34.19 (OEb), U43.15 (O0)
/~sr_md: MCU1.CB1, U21.9, U33.14 (O1)
/~sr_pc: MCU1.BF1, U33.13 (O2)
/~vect_enb: U11.11, U29.1 (OEa), U48.1 (OEa), U48.19 (OEb)
GND: C1.2, C2.2, C3.2, C4.2, C5.2, C6.2, C7.2, C8.2, C9.2, C10.2, C11.2, C12.2, C13.2, C14.2, C15.2, C16.2, C17.2, C18.2, C19.2, C20.2, C21.2, C22.2, C23.2, C24.2, C25.2, C26.2, Cp1.2, Cp2.2, Cp3.2, Cp4.2, Cp5.2, Field1.1 (A), JP2.1 (A), MCU1.AC2, MCU1.AJ1, MCU1.AM1, MCU1.AT1, MCU1.BC2, MCU1.BJ1, MCU1.BM1, MCU1.CC2, MCU1.CM1, MCU1.DC2, MCU1.DJ1, MCU1.DT1, MCU1.G1 (GND), MCU1.G2 (GND), MCU1.G3 (GND), MCU1.G4 (GND), MCU1.G5 (GND), MCU1.G6 (GND), MCU1.G7 (GND), MCU1.G8 (GND), MCU1.G10, MCU1.G11, MCU1.G12, MCU1.G13, MCU1.G14, MCU1.G15, MCU1.G16, MCU1.G17, MCU1.G18, MCU1.G19, MCU1.G20, MCU1.G21, MCU1.G22, MCU1.G23, MCU1.G24, MCU1.G25, OSC1.3 (gnd1), OSC1.8 (gnd2), U1.12 (GND), U2.12 (GND), U3.12 (GND), U4.12 (GND), U5.12 (GND), U11.7 (GND), U13.7 (GND), U15.2 (D), U15.7 (GND), U16.7 (GND), U17.7 (GND), U18.7 (GND), U21.7 (GND), U22.7 (GND), U23.7 (GND), U24.7 (GND), U25.10 (GND), U26.10 (GND), U27.10 (GND), U28.10 (GND), U29.2 (I0a), U29.4 (I1a), U29.6 (I2a), U29.8 (I3a), U29.10 (GND), U30.10 (GND), U31.10 (GND), U32.8 (GND), U33.8 (GND), U34.10 (GND), U35.10 (GND), U36.7 (GND), U37.2 (A0), U37.8 (gnd), U37.11 (A3), U37.14 (A2), U37.15 (E), U38.8 (GND), U39.8 (GND), U40.8 (GND), U41.5 (E2), U41.8 (GND), U42.10 (GND), U43.5 (E2), U43.8 (GND), U44.10 (GND), U45.1 (~E), U45.10 (GND), U46.7 (GND), U47.5 (EI), U47.8 (GND), U48.2 (I0a), U48.4 (I1a), U48.6 (I2a), U48.10 (GND), U48.11 (I0b), U49.8 (gnd), U50.8 (gnd), U51.8 (gnd), U54.7 (GND), U55.7 (GND), U56.1 (Ea), U56.8 (GND), U56.15 (Eb)
unnamed: C1.1, R6.2, U11.2
unnamed: D1.2 (A), R2.2
unnamed: Field1.2 (C), U1.18 (ce3), U2.18 (ce3), U3.18 (ce3), U4.18 (ce3), U5.18 (ce3)
unnamed: JP1.1 (A), OSC1.9 (~fb)
unnamed: JP2.2 (B), U1.20 (~ce1), U2.20 (~ce1), U3.20 (~ce1), U4.20 (~ce1), U5.20 (~ce1)
unnamed: C27.1, L1.1, OSC1.1 (tnk1)
unnamed: C27.2, L1.2, OSC1.2 (tnk2)
unnamed: OSC1.14 (xtal1), Y1.1
unnamed: OSC1.15 (xtal2), Y1.2
unnamed: R6.1, U11.1, U17.6
unnamed: U11.9, U18.3, U24.6
unnamed: U11.12, U18.4
unnamed: U13.1, U13.2, U13.11
unnamed: U13.3, U54.9, U54.10
unnamed: U13.4, U17.8
unnamed: U15.5 (Q), U17.9
unnamed: U11.3, U15.4 (~S)
unnamed: U15.12 (D), Version1.2 (C)
unnamed: U16.3, U16.13
unnamed: U17.3, U24.13
unnamed: U17.4, U18.10
unnamed: U17.11, U54.5
unnamed: U16.8, U22.1 (A1), U22.11 (A2)
unnamed: U22.2 (C1), U22.4 (B1), U23.6 (~Q)
unnamed: U21.12, U22.5 (B2), U22.6 (B3)
unnamed: U21.6, U22.3 (C2)
unnamed: U21.8, U22.9 (D1)
unnamed: U22.10 (D2), U23.8 (~Q)
unnamed: U18.2, U25.1 (OE), U26.1 (OE), U27.1 (OE), U30.1 (OE), U31.1 (OE)
unnamed: U18.6, U28.1 (OEa), U28.19 (OEb), U29.19 (OEb)
unnamed: U13.9, U32.15 (O0)
unnamed: U37.4 (O0), U49.20 (pup), U50.20 (pup), U51.20 (pup)
unnamed: U37.7 (O1), U49.19 (~fe), U50.19 (~fe), U51.19 (~fe)
unnamed: U37.12 (O2), U49.11 (s1), U50.11 (s1), U51.11 (s1)
unnamed: U37.9 (O3), U49.10 (s0), U50.10 (s0), U51.10 (s0)
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

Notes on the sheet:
Checked against edgelist
Changed
U20 designed out. Single EXNOR gate moved to ALU.



Board: 2 copper layers, 233.3 x 152.4 mm, 96 parts (25 on the bottom side), 253 nets.

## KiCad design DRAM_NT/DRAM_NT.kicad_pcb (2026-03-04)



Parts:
BB0, BB1, BB2, BB3, BB4, BB5, BB6, BB7: 74LS245; DIP-20_W7.62mm
C0, C1, C2, C3, C4, C5, C6, C7, C8, C9, C10, C11, C12, C13, C14, C15, C18, C19, C20, C21, C22, C23, C24, C25, C26, C27, C28, C29, C30, C31, C32, C33, C34, C35, C36, C37, C38, C39, C40, C41, C44, C45, C46: 100n; C_1206_3216Metric_Pad1.33x1.80mm_HandSolder
C16, C43, C47, C48: 1n; C_Rect_L7.2mm_W3.5mm_P5.00mm_FKS2_FKP2_MKS2_MKP2
C17, C42: 100n; C_Rect_L7.2mm_W3.5mm_P5.00mm_FKS2_FKP2_MKS2_MKP2
C49, C50, C51, C52, C53, C54, C55, C56, C57, C58, C59, C60, C61, C62, C63, C64, C65, C66, C67, C68, C69, C70, C71, C72, C73, C74, C75, C76, C77, C78, C79, C80, C81, C82, C83, C84, C85, C86, C87, C88: 470n; C_0805_2012Metric_Pad1.18x1.45mm_HandSolder
Cp1, Cp2, Cp3, Cp4, Cp5: 68U; CP_PHP
Cp6, Cp7, Cp8: 68U; CP_EIA-7343-20_Kemet-V_HandSolder
D1: LED; LED_D5.0mm_Horizontal_O3.81mm_Z9.0mm
D2: 1N4148; D_DO-35_SOD27_P7.62mm_Horizontal
DR0, DR1, DR2, DR3, DR4, DR5, DR6, DR7, DR8, DR9, DR10, DR11, DR12, DR13, DR14, DR15: 256Kx4; DIP-20_W7.62mm
DRAM1: lilith_nt_edge; Lilith_edge
DRAM_CTRL1: SN74S409; DIP-48_W15.24mm
DRI1, DRI2: 74LS574; DIP-20_W7.62mm
DRO1, DRO2: 74LS574; DIP-20_W7.62mm
DramSM1: GAL16V8; DIP-20_W7.62mm_Socket
HL1, HL2: MountingHole; Handle
INV1: 74LS04; DIP-14_W7.62mm
JP1: Jumper_2_Small_Bridged; SolderJumper-2_P1.3mm_Bridged_RoundedPad1.0x1.5mm
R1, R2, R3, R4, R5, R6, R7, R8, R9, R10, R11, R12, R13, R14: 100; R_0805_2012Metric_Pad1.20x1.40mm_HandSolder
R15, R27, R28, R29, R30, R31: 100; R_Axial_DIN0207_L6.3mm_D2.5mm_P7.62mm_Horizontal
R16, R33, R34: 2K2; R_Axial_DIN0207_L6.3mm_D2.5mm_P7.62mm_Horizontal
R17, R18, R19, R21, R22, R23, R24, R25, R26: 0; R_0805_2012Metric_Pad1.20x1.40mm_HandSolder
R32: 4K7; R_Axial_DIN0207_L6.3mm_D2.5mm_P7.62mm_Horizontal
R35, R36: 3K3; R_Axial_DIN0207_L6.3mm_D2.5mm_P7.62mm_Horizontal
RB0, RB1, RB2, RB3, RB4, RB5, RB6, RB7: 74LS541; DIP-20_W7.62mm
RN1, RN2, RN3: 3K3; R_Array_SIP10
RamClk1: CXO_DIP14; Oscillator_DIP-14
RamClk2: CXO_DIP8; Oscillator_DIP-8
RefCp1: LM555xN; DIP-8_W7.62mm
U2: 74LS139; DIP-16_W7.62mm
U3, U22: 74LS74; DIP-14_W7.62mm
U4, U6: Spare; DIP-20_W7.62mm
U5: 74LS123; DIP-16_W7.62mm
U9: 74S00; DIP-14_W7.62mm
U19: 74S32; DIP-14_W7.62mm
U20: 74LS125; DIP-14_W7.62mm
exck1: Jumper_2_Small_Bridged; SolderJumper-2_P1.3mm_Bridged_RoundedPad1.0x1.5mm
prio0: 74ls278; DIP-14_W7.62mm
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

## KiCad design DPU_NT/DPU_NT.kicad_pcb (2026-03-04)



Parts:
BUF1: 74LS367; DIP-16_W7.62mm
C1, C2: 3.3u; CP_Radial_D5.0mm_P2.50mm
C3, C4, C6, C7, C8, C9, C18: 1uF; CP_Radial_Tantal_D5.0mm_P2.50mm
C5: 100n; C_Rect_L7.0mm_W3.5mm_P5.00mm
C10, C11, C12, C13, C14, C15, C16, C17, C20, C21, C22, C23, C24, C25, C26, C27, C30, C31, C32, C33, C34, C35, C36, C37, C42, C45, C46, C47: 100n; C_1206_3216Metric_Pad1.33x1.80mm_HandSolder
C19, C29, C38, C39, C40: 68uF; CP_PHP
C28, C41, C43, C44: 100n; C_0805_2012Metric
CPU1: 6802; DIP-40_W15.24mm
D1: 1N4001; D_DO-35_SOD27_P7.62mm_Horizontal
D2: 13v; D_DO-35_SOD27_P7.62mm_Horizontal
D3: 5.6V; D_DO-35_SOD27_P7.62mm_Horizontal
D4, D5: 1N4148; D_DO-35_SOD27_P7.62mm_Horizontal
DIV1: 74LS74; DIP-14_W7.62mm
DPU1: lilith_nt_edge; Lilith_edge
EPROM1: 27128; DIP-28_W15.24mm
GAL1: GAL16V8; DIP-20_W7.62mm_Socket
HL1, HL2: MountingHole; Handle
INV1: 74LS04; DIP-14_W7.62mm_LongPads
J1: DPU_serial; PinHeader_2x05_P2.54mm_Vertical
J2: Conn_02x02_Counter_Clockwise; PinHeader_2x02_P2.54mm_Vertical
J3: CPSEL; PinHeader_1x04_P2.54mm_Vertical
JP2: DPU_ENA; PinHeader_1x02_P2.54mm_Vertical
NA1: 74LS132; DIP-14_W7.62mm
PRG1: WSI57C49; DuoDil24
PSU1: Barrel_Jack_Switch; BarrelJack_GCT_DCJ200-10-A_Horizontal
Q1: 2N2219; TO-39-3
Q2, Q3: BC547; TO-92_Inline
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

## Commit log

2026-03-22 First release for newly finished IO block
    [IOB_NT.kicad_pcb, IOB_NT.kicad_sch]
2026-03-31 V1.0 release
    First release, corresponds to first version of PCB's
2026-03-31 V1.0 release
    This release corresponds to V1.0 release of the PCB.
    [Backplane_NT.kicad_sch]
2026-03-31 Release V1.0
    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
